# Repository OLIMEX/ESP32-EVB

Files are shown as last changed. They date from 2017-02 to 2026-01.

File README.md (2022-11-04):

# ESP32-EVB

ESP32 wifi / BLE development board with Ethernet, relays, microSD card, CAN, infrared, Li-Po charger, GPIOs.

Product page: https://www.olimex.com/Products/IoT/ESP32/ESP32-EVB/open-source-hardware

Open-source hardware board made with open-source CAD software. Comes with either ESP32-WROOM-32E or ESP32-WROOM-32UE module, depending on variant. Board vairants are:

| Board variant | ESP32 module  | External antenna  | Temperature range |
| --- | --- | ---  | --- |
| ESP32-EVB | ESP32-WROOM-32E  | No  | 0-70°C  |
| ESP32-EVB-EA  | ESP32-WROOM-32UE  | Yes  | 0-70°C  |
| ESP32-EVB-EA-IND  | ESP32-WROOM-32UE  | Yes  | -40+85°C |
| ESP32-EVB-IND  | ESP32-WROOM-32E  | No  | -40+85°C |

ESP32-EVB - ESP32-WROOM-32E module, no external antenna, commercial temeprature range 0-70°C

ESP32-EVB-EA - ESP32-WROOM-32UE module, fitting external antenna, commercial temeprature range 0-70°C

ESP32-EVB-EA-IND - ESP32-WROOM-32UE module, fitting external antenna, industrial temeprature range -40+85°C

ESP32-EVB-IND - ESP32-WROOM-32E module, no external antenna, industrial temeprature range -40+85°C

You can find design hardware sources, schematic exports, BOMs, and more, in the "HARDWARE" folder.

You can find ESP-IDF and Arduino IDE examples, in the "SOFTWARE" folder.

# FAQ

---

**Q:** I have some trouble downloading my code to ESP32-EVB. Is there a way to force boot mode?

**A:** By default the board comes without BOOT button functioanlity. However, we have providedan option to can convert user BUT1 into BOOT button to force button but this requires hardware change and soldering. Soldering experience is required since it is a tight spot. You need to perform two changes:

- Solder the pads of R46 together (or solder 0R resistor in 0603 size in the R46 position there);
- Unsolder R14 and solder its pads together (or again solder 0R resistor in 0603 size in the R14 position).

After the two changes, to manually force boot mode, hold button BUT1 then reset the board with RST1. Both R46 and R14 are near the button BUT1. Notice that the button will still act as user button after the initial boot sequence. You can find more about what changing these resistors does if you inspect the schematic.

---

**Q:** The Ethernet doesn't start after a restart, it throws "init phy failed" error. What should I do?

**A:** Ethernet might hang of initialized too quickly after a reset. Add some delay at the start of the code before the Ethernet initialization. For example, if you are using the default Arduino IDE demo for LAN8720 try adding delay () after Serial.begin(), as shown below:
```
void setup()
{
Serial.begin(115200);
delay (2000);
WiFi.onEvent(WiFiEvent);
ETH.begin();
}
```

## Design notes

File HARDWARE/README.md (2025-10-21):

# ESP32-EVB

Hardware revisions changes:

- revision A - internal, not released
- revision B - initial public release
- revision C - changes:

1. MicroUSB connector moved back, 40 mils to the middle of the board.
2. All mounting holes are now connected to GND.
3. Improved the ground layer around the infra red's pads and wires.

- revision C1 - changes:

1. Changed R38 from 10k/0603 to 100k/0603 to lower the time without clock
2. Changed C28 from 100n/0603 to 10n/0603 to increase the time in reset

- revision D - changes:

1. Added a resistor (1k) between OSC_DIS and reset of the PHY.
2. Added option to use MCP2562-E/SN and SN65HVD230D upotreba -> R58(NA/R0603)!
4. U2 be promeneno ot SY8009AAAC(SOT23-5) na SY8089AAAC(SOT23-5).
5. FET1 and FET2 were changed from IRLML6402 to WPM2015-3/TR.

- revision D1 - changes:

1. Removed C18(10uF)
2. U8 changed from BD5230G-TR(SSOP5/SOT-23-5) to NCP303LSN27T1G(SOT-23-5), due to unavailability;
3. C28 changed from 100nF/50V/20%/Y5V/C0603 to 470nF/16V/10%/X7R/C0603, because of the U8 change;

- revision D2 - changes:

1. U6 changed from MCP2551-I/SN(SOIC-8_150mil) to MCP2562-E/SN(SOIC-8_150mil)
2. R58 changed from NA/R0603 to 0R/R0603.

- revision E - changes:

MCP2551 got "Not recommended for new designs" status so it is replaced with MCP2562 and this lead to:

1. R58(0R/R0603) was deleted and U6's pin<5> was connected to +3.3V.
2. R52(680R/R0603) was deleted.
3. R50(330R/R0603) and R51(330R/R0603) were deleted.
4. The MCP2562-E_SN(SOIC-8_150mil)'s symbol was updated, i,.e. U6's component was exchanged with 2562!

Changes related to the problems with ethernet PHY:

5. The following components were added to enable powering on the PHY after the 50MHz oscillator has been started: L5(NA(FB0805/600R/2A)), FET3(WPM2015-3/TR), FET4(BSS138), C29(22uF/6.3V/20%/X5R/C0603), R50(1k/R0603) and R51(10k/R0603).

Changes related to optimizations:

6. R26(330R/R0603) and R27(330R/R0603) were changed to 220R/R0603 to reserve a feeder.
7. C1 was changed from 47uF/6.3V/20%/X5R/C0805 to NA(47uF/6.3V/20%/X5R/C0805).	
8. C3 was changed from 47uF/6.3V/20%/X5R/C0805 to NA(47uF/6.3V/20%/X5R/C0805).

- revision F - changes:

1. BUT1 and RST1 new packages.
2. Minor PCB routing optimizations.
3. All footprints were updated.

- revision G - internal, not released

1. Changed the Li-Po charger to BL4054B (was MCP73833 previously).

- revision H - limited release, changes:

1. CH340 now powered only from USB (not from battery). Added D7 and D8 on TX/RX, levels are adjusted via R35 and R40. Pin #20 now disconnected. SY8089AAAC(SOT23-5) devider now R20 49.9k and R19 220k. R24 now 470ê.
2. Added battery voltage sense option. This is controlled with jumper BAT/BUT1, C30, R9, and R10. It is not enabled by default to maintain compatiblity with previous revisions.
3. Added 3D models of the components.
4. L2 now 2.2uH/1.5A/DCR=72mR/20%/3.00x3.00x1.50mm/CD32(NR3015T2R2M). Some improvements on ESP-WROOM-32_MODULE package.

- revision H1 - released, changes:

Improved start up for certain hardware setups. Revision H1 has same PCB as revision H (and the PCB of revision H1 says "H") but couple of component changes:

1. Changed R24 from 470k/0603 to 1k/0603, the 1k resistor is soldered over the 470k one to reduce chances of damage.

- revsion I - released, changes:

Applied the changes from revision H1 to the PCB and the design, and further improved start-up reliability by adding a capacitor:

1. Added C31(1uF/10V/10%/X5R/C0603) on the ESP_EN signal and R24's value changed from 1k/0603 to 10k/0603;
2. Added several text lables at the botttom of the board about CAN's connector signals and the battery polarity.

- revision I1 - released, changes:

1. Changed C18 from NA(10uF/6.3V/20%/X5R/C0603) to 1nF/50V/5%/NPO(COG)/C0603 - this improves Ethernet reliability during relay switcing;

- revision I2 - released, changes:

1. Changed U8, from NCP303LSN27T1G(SOT-23-5) to NCP303LSN18T1G(SOT-23-5).

- revision I3 - released, changes:

1. Changed U6 from MCP2562-E/SN(SOIC-8_150mil) to SIT1042T/3(SOIC-8_150mil).

- revision I4 - released

1. Changed U2 value to NCV303LSN23T1G.

- revision J - not released

1. Due to global unavailability of MCP2562-E/SN chips, it was necessary to adjust the CAN schematic for compatiblity with MCP2551/SIT1050 too. Following changes were required:
- U6 changed from MCP2562-E/SN(SOIC-8_150mil) to SIT1050T(SOIC-8_150mil);
- Added R12, NA/R0603;
- Added R13, 330R/R0603;
- Added R15, 680R/R0603;
2. CE sign added in the PCB;
3. Changed C18 from NA(10uF/6.3V/20%/X5R/C0603) to 1nF/50V/5%/NPO(COG)/C0603 - this improves Ethernet behavior during relay switching;
4. Added U11(VDA2710NTA(SOT-23)), D10(BAT54A(SOT23-3)), R58(49.9R/1%/R0402), R52(220k/R0603) and C32(1uF/10V/10%/X5R/C0603), so that we can have option to replace the reset chip NCP303LSN27T1G(SOT-23-5). Changed U8 to (NA(NCP303LSN27T1G(SOT-23-5))) and C28 to NA(470nF/16V/10%/X7R/C0603);
5. Added D9(1N5819S4(SOD-123)), to rptoect ESP_EN from 4.2V surge during programming; also to protect C32 gettomg cjarged from DTR output of CH340, else new reset schematic (VDA2710NTA) has random timing after pressing reset button;
6. Added ESD protection on the Ethernet, TVS1(ESDS314DBVR(SOT-23-5));
7. R28, R31, R32, and R33 changed from 49.9R/1%/R0603 to 49.9R/1%/R0402;
8. U7 changed from RPM7236-H8 to VS1838B.

- revision K - released

1. Labelling improvements;
2. Removed "GPIO4" from the "Internal Bootstrapping Resistors" table.

- revision K1 - released

1. Changed reset IC from VDA2710NTA(SOT-23)to HX7027 (due to unavailability of VDA2710NTA).
2. HX7027 has slightly bigger consumption and when powered trought R52 the voltage might get too low; so also changed R52 from 220k to 100k.

- revision K2 - released
------
1. Changed battery chager to TP4054-42-SOT25-R;
2. Changed R8 from 2k to 10k to reduce battery charger current to 100mA.

- revision L - released
------

1. Migated the whole project to KiCad7;
2. R57 deleted to reduce possible environment noise picking in combination with relay switching;
3. Relays changed;
4. U2-SY8089 changed to TPS62A02ADRLR(SOT-563-6);
5. CH340 changed with smaller variant ch340X.

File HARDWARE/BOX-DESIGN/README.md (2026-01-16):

Box can be purchased from here: https://www.olimex.com/Products/IoT/ESP32/BOX-ESP32-EVB/

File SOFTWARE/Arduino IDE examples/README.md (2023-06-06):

Arduino IDE would not work with ESP32 boards out-the-box. ESP32-EVB and the rest of the Olimex-made ESP32 boards are supported by this Arduino for ESP32 package. You need to install ESP32 support in Arduino IDE, follow the advice here: 

https://docs.espressif.com/projects/arduino-esp32/en/latest/installing.html

After the package is installed select the ESP32-EVB entry from the board selector and the COM port it was assigned by your operating system.

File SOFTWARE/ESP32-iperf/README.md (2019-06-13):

This demo is based on the original iperf demo in esp-idf with adapted configuration for ESP32-EVB.

In order to make it work:
1) Select the port where the board has connected using menuconfig. To do so type inside the console (msys32 or terminal):
make menuconfig

2) Navigate to "Menu flasher config --> Default serial port" select your port.

3) After that flash the board (this may take a while the first time after you change any of the configurations)
make flash

4) Then run the terminal
make monitor

5) Wait to initialize follow the instructions on the terminal:
5.1) Run the ethernet
ethernet start
5.2) Optionally if you want to see more details (IP address, mask, default gateway) type
ethernet macro

6) Run the iperf
6.1) Server mode:
iperf -s -i 1 -t 10
with this you will run it for 10 seconds transfer (more than that will trigger the watchdog reset) and 1 second interval.

6.2) Client mode:
iperf -c SERVER_IP_ADDRESS -i 1

You can check the sample data inside the ESP32-PoE_Data.txt file.

YYYY/MM/DD
2019/06/13

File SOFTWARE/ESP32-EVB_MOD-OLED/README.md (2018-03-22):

Demo example for Olimex ESP32-EVB (revision D) with Olimex MOD-OLED-128x64 connected to the UEXT.

Used I2C-1 for communication between the host board and the module. More comments can be found in main.c. 

After programming on the screen you will see a welcome message. When you click the button BUT1, a counter will appear on the screen. The setup looks like this:

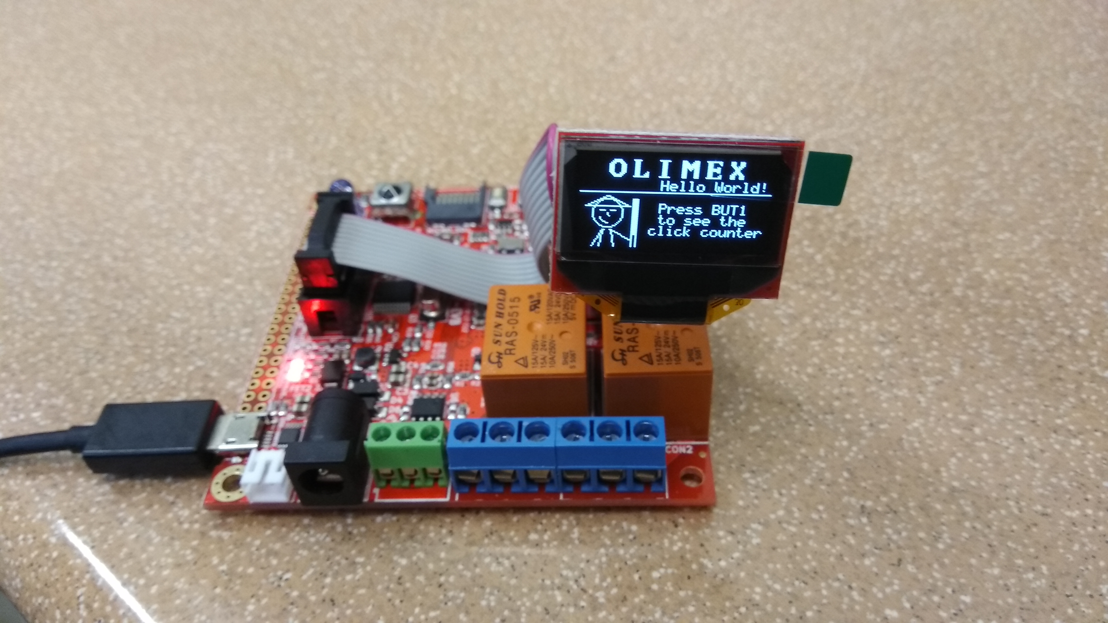
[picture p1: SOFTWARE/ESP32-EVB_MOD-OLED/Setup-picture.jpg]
Setup


Products used:

ESP32-EVB: https://www.olimex.com/Products/IoT/ESP32-EVB/open-source-hardware

MOD-OLED-128x64: https://www.olimex.com/Products/Modules/LCD/MOD-OLED-128x64/open-source-hardware

Stanimir Petev
2018/03/22

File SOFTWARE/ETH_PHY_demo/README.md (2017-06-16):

# Ethernet Example 
( customized for Olimex ESP32 EVB-REV-B with LAN8710 CAN & more ) 

Initialises the ethernet interface and enables it, then sends DHCP requests and tries to obtain a DHCP lease. If successful then you will be able to ping the device.

# PHY Configuration

Use "make menuconfig" to set the PHY model and the PHY address, and configure the SMI I/O pins (see below). These configuration items will vary depending on the hardware configuration you are using.

The customize default example configuration is correct for Olimex ESP32 EVB-REV B Ethernet board with LAN8710 PHY. 

## PHY Address

The PHY address depends on the hardware and the PHY configuration. Olimex ESP EVB-REV-B use PHY address 0.

FYI:
* Address 31 is correct for Espressif's Ethernet board with TLK110 PHY.
* Address 1 is correct for the common Waveshare LAN8720 PHY breakout.
* Default Address 0 is correct for the Olimex ESP32 EVB REV B IoT LAN8710 PHY Board with CAN
* Other LAN8720 breakouts may take address 0.

If the PHY address is incorrect then the EMAC will initialise but all attempts to read/write configuration registers on the PHY will fail.

## RMII PHY Wiring

The following PHY connections are required for RMII PHY data connections. These GPIO pin assignments cannot be changed.

| GPIO | RMII Signal | ESP32 EMAC Function | Notes |
| --- | --- | --- | ----- |
| 0 | REF_CLK | EMAC_TX_CLK | Currently this must be a 50MHz reference clock input from the PHY (ext_osc configuration). |
| 21 | TX_EN | EMAC_TX_EN | |
| 19 | TX0 | EMAC_TXD0 | |
| 22 | TX1 | EMAC_TXD1 | |
| 25 | RX0 | EMAC_RXD0 | |
| 26 | RX1 | EMAC_RXD1 | |
| 27 | CRS_DV | EMAC_RX_DRV | |

## RMII PHY SMI Wiring

The following PHY connections are required for RMII PHY SMI (aka MDIO) management interface. These GPIO pin assignments can be changed to any unused GPIO pin.

For the example, these pins are configured via `make menuconfig` under the Example configuration.

| Default Example GPIO | RMII Signal | Notes |
| --- | --- | --- |
| 23 | MDC | Output to PHY |
| 18 | MDIO | Bidirectional |

The defaults in the customized example are correct for Olimex EVB-REV-B Ethernet IoT board with CAN.

## Note about GPIO0

Because GPIO0 is a strapping pin for entering UART flashing mode on reset, care must be taken when also using this pin as EMAC_TX_CLK. If the clock output from the PHY is oscillating during reset, the ESP32 may randomly enter UART flashing mode.

One solution is to use an additional GPIO as a "power pin", which either powers the PHY on/off or enables/disables the PHY's own oscillator. This prevents the clock signal from being active during a system reset. For this configuration to work, GPIO0 also needs a pullup resistor and the "power pin" GPIO will need a pullup/pulldown resistor - as appropriate in order to keep the PHY clock disabled when the ESP32 is in reset.

See the example source code to see how the "power pin" GPIO can be managed in software.

To using GPIO 17 for this function can be overriden. Example on Espressif's Ethernet development board, GPIO 17 is the power pin used to enable/disable the PHY oscillator.

On Olimex ESP32 EVB REV B IoT LAN8710 PHY Board with CAN there is a own solution from Olimex.
For deeper Information look in the Hardware folder on Olimex Github. There is the Shematic.
Also there is the HDK with board pcb and other design Informations.

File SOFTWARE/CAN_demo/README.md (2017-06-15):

# CAN DEMO Code Example

Starts a CAN demo to receive Standard Frames
if there is test frame set in Kconfig ( menuconfig ) 
there is also send a test frame.

# Note:

Olimex EVB Rev B 

Rx CAN = GPIO 35

Tx CAN = GPIO  5 

See the README.md file in the components CAN directory for more information about 
CAN Driver Pack.

# credit 

# CAN Driver 
by Thomas Bart, 

http://www.barth-dev.de/

Repo: https://github.com/ThomasBarth/ESP32-CAN-Driver

# CAN Driver Pack ESP-IDF 
by Rudi Wagner, rudi ;-) 

http://esp32.de

Repo: https://github.com/ESP32DE/ESP32-CAN-Driver/tree/Component_CAN_Driver_Pack

# DEMO code for CAN Driver Pack 

https://github.com/ESP32DE/ESP32-CAN-Driver/tree/DEMO_CAN

# look allways first to the origin's

https://github.com/ThomasBarth/ESP32-CAN-Driver

https://github.com/ESP32DE/ESP32-CAN-Driver/tree/Component_CAN_Driver_Pack

https://github.com/ESP32DE/ESP32-CAN-Driver/tree/DEMO_CAN

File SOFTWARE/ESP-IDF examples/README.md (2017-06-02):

# ESP32-EVB Software development

## Install ESP-IDF
To run the examples in this directory or your own you'll need to get
SDK from Espressif called [ESP-IDF](https://github.com/espressif/esp-idf).
We recommend reading their
[setup guide](https://github.com/espressif/esp-idf#setting-up-esp-idf).

When IDF_PATH is in your PATH you're ready to continue with example running.

## Run examples
To run our example all you need to do is:

* Run menuconfig
```sh
    make menuconfig
```

    * Configure serial flasher

    ESP32-EVB has built-in serial flasher to help users upload their projects.
    Connect the board to PC via USB-micro cable. New serial device should
    apear, for example **/dev/ttyUSB0**. Then in the menuconfig configure
    flasher as follows:

    ```
    Serial flasher config  --->
            (/dev/ttyUSB0) Default serial port
            Default baud rate (115200 baud) --->
            [*] Use compressed upload
            Flash SPI mode (DIO)  --->
            Flash SPI speed (40 MHz) --->
            Flash size (4 MB) --->
            [*] Detect flash size when flashing bootloader
            Before flashing (Reset to bootloader)  --->
            After flashing (Reset after flashing)  --->
            'make monitor' baud rate (115200 bps)  --->
    ```

    * Configure example

    Some examples have their own configuration menu. If it's present
    you can modify the options:

    ```
    Example Configuration  --->
            Select board relay to use in the example (Relay 1)  --->
    ```

Exit and save configuration.

* Compile example
To compile example run:
```sh
make
```

* Uploading example
As we previously mention uploading application is done automatically.
If serial flasher is configured do:
```sh
make flash
```

You'll see something like this:
```
esptool.py v2.0-beta3
Flashing binaries to serial port /dev/ttyUSB0 (app at offset 0x10000)...
esptool.py v2.0-beta3
Connecting........__
Uploading stub...
Running stub...
Stub running...
Configuring flash size...
Auto-detected Flash size: 4MB
Flash params set to 0x0220
Compressed 15808 bytes to 9219...
Wrote 15808 bytes (9219 compressed) at 0x00001000 in 0.8 seconds (effective 154.5 kbit/s)...
Hash of data verified.
Compressed 356080 bytes to 168292...
Wrote 356080 bytes (168292 compressed) at 0x00010000 in 14.9 seconds (effective 191.3 kbit/s)...
Hash of data verified.
Compressed 3072 bytes to 82...
Wrote 3072 bytes (82 compressed) at 0x00008000 in 0.0 seconds (effective 1905.4 kbit/s)...
Hash of data verified.

Leaving...
Hard resetting...
```

Optionally you can open serial monitor by typing:
```sh
make monitor
```

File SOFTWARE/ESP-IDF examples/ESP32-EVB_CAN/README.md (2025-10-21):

| Supported Targets | ESP32 | 
| --- | ----- |

# CAN Example
(See the README.md file in the upper level 'examples' directory for more information about examples.)

## Overview

This example demonstrates basic usage of `CAN driver`. The work flow of the example could be as follows:

1. Install CAN driver
2. Receive CAN messages
3. Send CAN message
4. Enable filter and receive only filtered messages (not implemented)

Code was heavily based on https://docs.espressif.com/projects/esp-idf/en/release-v3.3/api-reference/peripherals/can.html

If you have a new CAN application to create (for example, J1939 communication to a tank), try this as a basic template, then add your own code.

## How to use example
See Build, Flash, and Run below.

### Hardware Required

This example assumes you have an Olimex ESP32-EVB and was tested with a REV I version. 

#### Pin Assignment

This example uses the embedded ESP32 CAN/TWAI controller. On the ESP32-EVB the pins are assigned as

* CAN-TX is on GPIO5
* CAN-RX is on GPI35

In the example code, these assignments are hard-coded.

### Configure the project

```
idf.py menuconfig
```
No configuration options have been set up.

The CAN transceiver is a MCP2562-E/SN. By default on the ESP32-EVB it operates on the +5V sourced from the PWR2 connector or USB connector.

### Build, Flash, and Run

Build the project and flash it to the board, then run monitor tool to view serial output. Use a CAN monitoring tool to see the transmitted message.

```
idf.py -p PORT build flash monitor
```

(Replace PORT with the name of the serial port to use.)

(To exit the serial monitor, type ``Ctrl-]``.)

See the [Getting Started Guide](https://docs.espressif.com/projects/esp-idf/en/latest/get-started/index.html) for full steps to configure and use ESP-IDF to build projects.

## Example Output

```bash
Driver installed
Driver started
Message received
Message is in Extended Format
ID:1CEBFFFA, data:2 90 E7 FF FF FF FF FF
Message queued for transmission
ESP_ERR_TIMEOUT
```

## Troubleshooting

See common troubleshooting for examples from [upper level](../README.md#common-troubleshooting).

(For any technical queries, please open an [issue](https://github.com/espressif/esp-idf/issues) on GitHub. We will get back to you as soon as possible.)

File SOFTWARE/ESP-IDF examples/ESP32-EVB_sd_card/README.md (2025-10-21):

# ESP32-EVB Software development
See the [README.md](../README.md) file in the upper level [examples](../) directory for more information about examples.

Copied from the OLD-ESP-IDF sd_card example without modification, except for deleting the makefiles and adding CMakeLists.txt as needed.

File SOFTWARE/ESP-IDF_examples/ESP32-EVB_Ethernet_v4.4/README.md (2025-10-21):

| Supported Targets | ESP32 | ESP32-S2 | ESP32-C3 |
| --- | ----- | --- | --- |

# Ethernet Example
(See the README.md file in the upper level 'examples' directory for more information about examples.)

## Overview

This example demonstrates basic usage of `Ethernet driver` together with `tcpip_adapter`. The work flow of the example could be as follows:

1. Install Ethernet driver
2. Send DHCP requests and wait for a DHCP lease
3. If get IP address successfully, then you will be able to ping the device

If you have a new Ethernet application to go (for example, connect to IoT cloud via Ethernet), try this as a basic template, then add your own code.

## How to use example

### Hardware Required

This example assumes you have an Olimex ESP32-EVB and was tested with a REV I version. The Ethernet PHY is a LAN8710A-EZC. See the Ethernet example in the Expressif ESP32 GitHub repository for information on using different hardware.

#### Configure the project (including Pin Assignment)
Set the following options using the Expressif-IDF SDK Configuration Editor (idf.py), or equivalent:
* Internal EMAC: enabled
* Ethernet PHY Device: LAN87xx
* SMI MDC GPIO number: 23
* SMI MDIO GPIO number: 18
* PHY Reset GPIO number: -1
* PHY Address: 0
* SPI Ethernet: disabled

### Build, Flash, and Run

Build the project and flash it to the board, then run monitor tool to view serial output:

```
idf.py -p PORT build flash monitor
```

(Replace PORT with the name of the serial port to use.)

(To exit the serial monitor, type ``Ctrl-]``.)

See the [Getting Started Guide](https://docs.espressif.com/projects/esp-idf/en/latest/get-started/index.html) for full steps to configure and use ESP-IDF to build projects.

## Example Output

```bash
I (394) eth_example: Ethernet Started
I (3934) eth_example: Ethernet Link Up
I (3934) eth_example: Ethernet HW Addr 30:ae:a4:c6:87:5b
I (5864) tcpip_adapter: eth ip: 192.168.2.151, mask: 255.255.255.0, gw: 192.168.2.2
I (5864) eth_example: Ethernet Got IP Address
I (5864) eth_example: ~~~~~~~~~~~
I (5864) eth_example: ETHIP:192.168.2.151
I (5874) eth_example: ETHMASK:255.255.255.0
I (5874) eth_example: ETHGW:192.168.2.2
I (5884) eth_example: ~~~~~~~~~~~
```

Now you can ping your ESP32 in the terminal by entering `ping 192.168.2.151` (it depends on the actual IP address you get).

## Troubleshooting

See common troubleshooting for Ethernet examples from [upper level](../README.md#common-troubleshooting).

(For any technical queries, please open an [issue](https://github.com/espressif/esp-idf/issues) on GitHub. We will get back to you as soon as possible.)

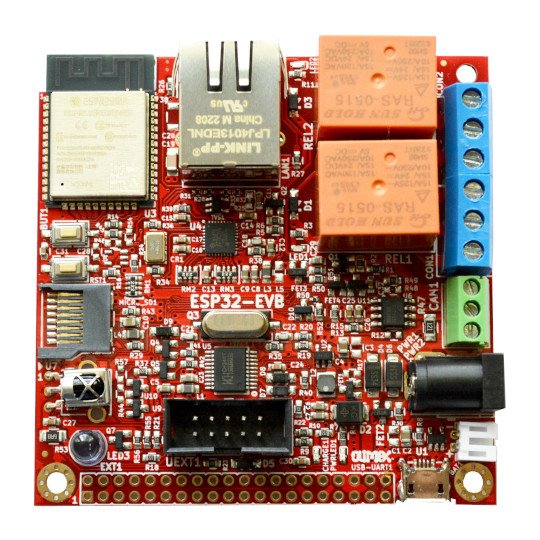
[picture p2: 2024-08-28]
DOCS/ESP32-EVB-2.jpg

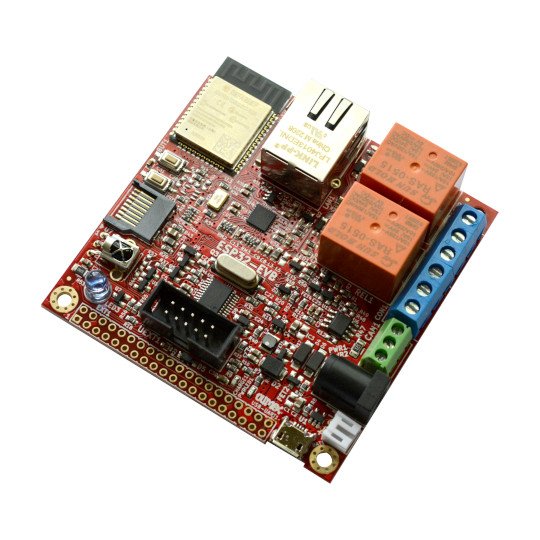
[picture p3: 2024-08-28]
DOCS/ESP32-EVB-1.jpg

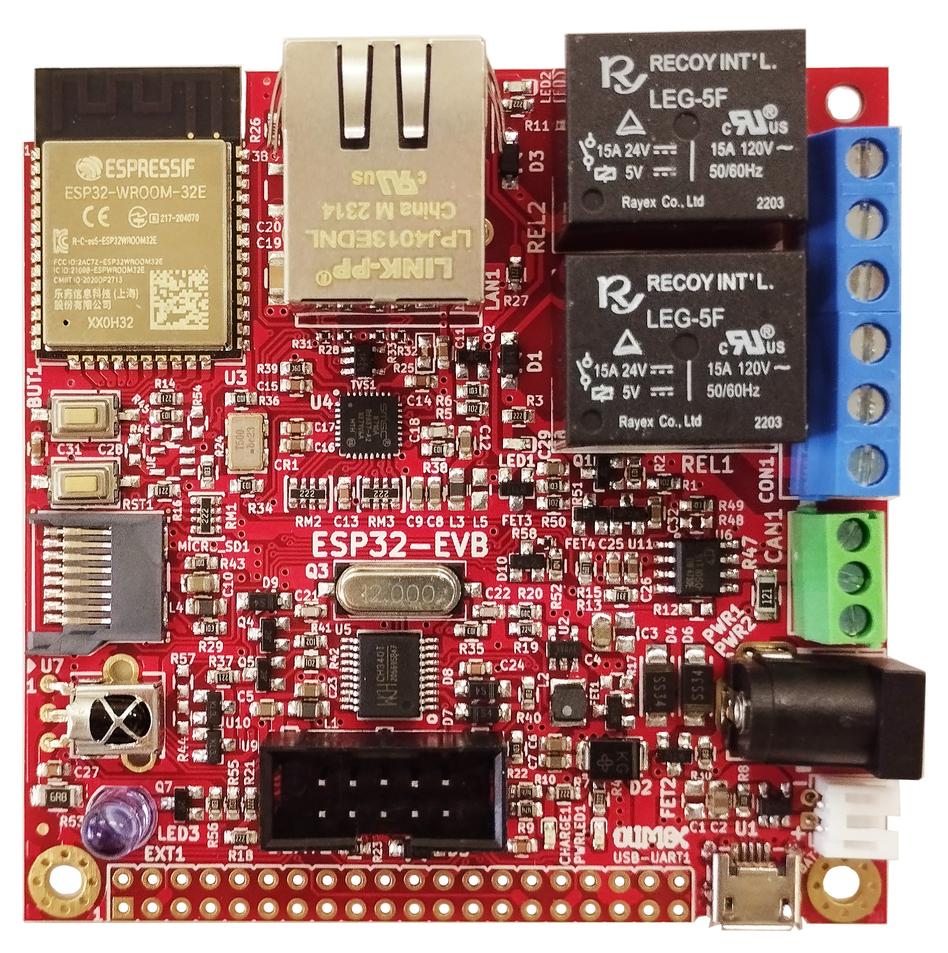
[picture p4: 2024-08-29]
DOCS/ESP32-EVB-2-new.jpg

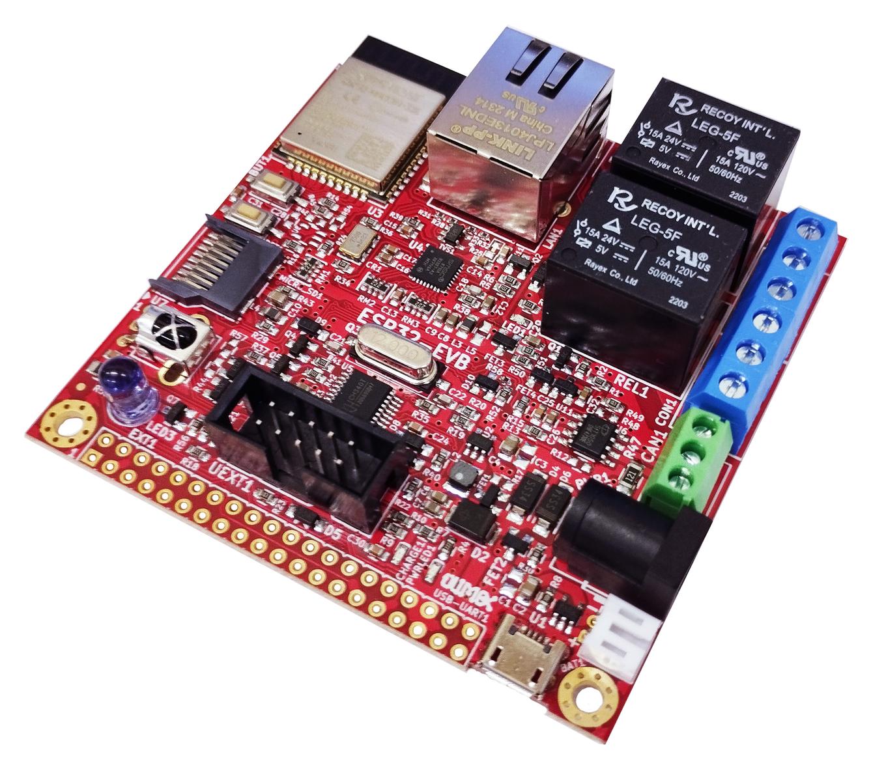
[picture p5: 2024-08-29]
DOCS/ESP32-EVB-1-new.jpg

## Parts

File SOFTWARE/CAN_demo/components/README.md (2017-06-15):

# Third Party Components

- ESPCan Driver 
  - Base CAN Driver [forked from Thomas Barth](https://github.com/ThomasBarth/ESP32-CAN-Driver)
  - General [Component CAN Driver Pack](https://github.com/ESP32DE/ESP32-CAN-Driver/tree/Component_CAN_Driver_Pack) Work for ESP-IDF with menuconfig from [rudi ;-)](http://esp32.de)

 version 0.1
 A basic CAN driver for the Espressif ESP32 by [Thomas Barth](http://barth-dev.de)
 
version 0.1_third_parts by [rudi ;-)](http://esp32.de)

Change Log from 21 May 2017
 - update to new DPORT Access
 - DPORT Access changed
    Details:
    https://github.com/espressif/esp-idf/commit/377a1f5ea1ca9152524d54df6a7294620f42173c

 - added RTR support
    Furetheremore, the complete FIR record is now copied into the 
    CAN frame type. This boosts performance.
    
    Details: 
    https://github.com/ThomasBarth/ESP32-CAN-Driver/commit/990a69465072a6ea7cf14f43f98fd6c95b8cf3a2

 - extended frames and interrupt types
    Added support for extended CAN frames and created an enum 
    for the CAN Interrupts.
    
    Details: 
    https://github.com/ThomasBarth/ESP32-CAN-Driver/commit/b1536a9ed3fe61abdeb1a1eaf4abdba978b2a09f

Change Log from 22 March 2017
 
   		- modified for esp-idf
   		- modified for component driver mode
 			- menuconfig file created
  			- cretaed component.mk for menuconfig and component version 
   		- modified and expanded demo code for using with menuconfig
 			- modified code for using it for Linux and Windows user
 
 			menuconfig config defines that you can use in the code:
 				ESPCan activated:
 					- CONFIG_ESPCAN ( bool ) 
  				baudrade 100,125, 250, 500, 800, 1000 and user: 
 					- CONFIG_CAN_SPEED_100KBPS 
 					- CONFIG_CAN_SPEED_125KBPS
 					- CONFIG_CAN_SPEED_250KBPS
 					- CONFIG_CAN_SPEED_500KBPS
 					- CONFIG_CAN_SPEED_800KBPS
 					- CONFIG_CAN_SPEED_1000KBPS
 					- CONFIG_CAN_SPEED_USER_KBPS
 				user CAN speed
 					- CONFIG_CAN_SPEED_USER_KBPS ( bool )
 						-CONFIG_CAN_SPEED_USER_KBPS_VAL (value)
 				gpio pins for CANRx and CANTx
 					- CONFIG_ESP_CAN_RXD_PIN_NUM
 					- CONFIG_ESP_CAN_TXD_PIN_NUM 
 				node id ( CAN identifier )
 					- CONFIG_ESP_CAN_NODE_ITSELF
 				enbable/disable send test frames
 					- CONFIG_CAN_TEST_SENDING_ENABLED
 					- CONFIG_CAN_TEST_SENDING_DISABLED

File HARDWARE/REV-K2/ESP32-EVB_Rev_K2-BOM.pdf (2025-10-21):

ESP32-EVB_Rev_K2_BOM | 02/25/2025
Qty | Designation | Package | Designator
1 | 0R(board_mounted) | 0R_0603 | R25
1 | 6.8R/R1206 | R_1206_5MIL_DWS | R53
2 | 10R/R0603 | R_0603_5MIL_DWS | R36,R43
5 | 49.9R/1%/R0402 | R_0402_5MIL_DWS | R28,R31,R32,R33,R58
1 | 120R/R1206 | R_1206_5MIL_DWS | R47
5 | 220R/R0603 | R_0603_5MIL_DWS | R14,R16,R26,R27,R37
1 | 330R/R0603 | R_0603_5MIL_DWS | R13
1 | 680R/R0603 | R_0603_5MIL_DWS | R15
6 | 1k/R0603 | R_0603_5MIL_DWS | R1,R5,R42,R41,R50,R55
1 | 2k/1%/R0603 | R_0603_5MIL_DWS | R8
6 | 2.2k/R0603 | R_0603_5MIL_DWS | R3,R4,R7,R11,R18,R21
15 | 10k/R0603 | R_0603_5MIL_DWS | R2,R6,R22,R23,R24,R29, R30,R34,R35,R38,R40,R45, R49,R51,R56
1 | 12.1k/1%/R0603 | R_0603_5MIL_DWS | R39
1 | 49.9k/1%/R0603 | R_0603_5MIL_DWS | R20
1 | 100k/R0603 | R_0603_5MIL_DWS | R52
1 | 220k/R0603 | R_0603_5MIL_DWS | R19
2 | 470k/R0603 | R_0603_5MIL_DWS | R9,R10
3 | RA1206_(4X0603)_4B8_2.2k | R_MATRIX_4 | RM1,RM2,RM3
2 | 27pF/50V/5%/C0G/C0603 | C_0603_5MIL_DWS | C21,C22
1 | 1nF/50V/5%/NPO(COG)/C0603 | C_0603_5MIL_DWS | C18
1 | 1nF/2000V/10%/X7R/C1206 | C_1206_5MIL_DWS_ISO | C19
9 | 100nF/50V/20%/Y5V/C0603 | C_0603_5MIL_DWS | C11,C13,C14,C15,C17, C25,C24,C27,C30
2 | 1uF/10V/10%/X5R/C0603 | C_0603_5MIL_DWS | C31,C32
1 | 2.2uF/6.3V/10%/X5R/C0603 | C_0603_5MIL_DWS | C16
1 | 10uF/6.3V/20%/X5R/C0603 | C_0603_5MIL_DWS | C26
8 | 22uF/6.3V/20%/X5R/C0603 | C_0603_5MIL_DWS | C5,C6,C7,C8,C9,C12,C23,C29
3 | 47uF/6.3V/20%/X5R/C0805 | C_0805_5MIL_DWS | C2,C4,C10
1 | 2.2uH/NRS3015T2R2MNGH | CD32 | L2
3 | 600R/2A/UPZ2012E-601-2R0TF | L_0805_5MIL_DWS | L1,L3,L4
1 | SMBJ6.0A(DO-214AA) | DO214AA_1(K)-2(A) | D2
2 | 1N5822/SS34/SMA | SMA-KA | D4,D6
6 | 1N5819S4(SOD-123) | SOD-123_1C-2A_KA | D1,D3,D5,D7,D8,D9
2 | BAT54C(SOT23-3) | SOT23-3 | U9,U10
1 | BAT54A(SOT23-3) | SOT23-3 | D10
1 | LED/IR333-A/5mm | LED-5mm-PTH-AK | LED3
1 | LED/Yellow/0603 | LED_0603_KA | CHARGE1
1 | LED/RED/0603 | LED_0603_KA | PWRLED1
2 | LED/GREEN/0603 | LED_0603_KA | LED1,LED2
5 | BC817-40(SOT23) | SOT23 | Q1,Q2,Q4,Q5,Q7
3 | WPM2015-3/TR | SOT23 | FET1,FET2,FET3
1 | BSS138 | SOT23 | FET4
1 | Q12MHz/2P/20ppm/20pF/HU49SM | Q_49U3HMS | Q3
1 | Q50MHz/25ppm/3V/4P/5x3.2mm | 5032-4P_HCX-3S | CR1
1 | ESDS314DBVR(SOT-23-5) | SOT-23-5 | TVS1
1 | ESP32-WROOM-32E-N4 | ESP-WROOM-32_MODULE | U3
1 | SIT1050T(SOIC-8_150mil) | SOIC-8_150mil | U6
1 | TP4054-42-SOT25-R | SOT-23-5 | U1
1 | LAN8710A-EZC(QFN32) | QFN32_EP(33)_5x5x0.9mm_ Pitch_0.5mm | U4
1 | HX7027(SOT-23) | SOT-23 | U11

ESP32-EVB_Rev_K2_BOM | 02/25/2025
1 | CH340T(SSOP20W) | SSOP-20W | U5
1 | SY8089AAAC(SOT23-5) | SOT-23-5 | U2
1 | VS1838B | RPM7236-H8 | U7
1 | PWRJ-2mm(YDJ-1134) | PWRJ-2mm(YDJ-1136) | PWR1
1 | BH10S(B-D-02x5-LF) | UEXT_ML10 | UEXT1
1 | TB3-3.5mm(HD-351 3P) | TB3-3.5mm | CAN1
1 | MISB-SWMM-5B-LF | USB-MICRO_MISB-SWMM-5B_LF | USB-UART1
1 | RJLBC-060TC1(LPJ4013EDNL) | RJLBC-060TC1 | LAN1
2 | DG306-5.0-3P | TB3-DG306-5.0_3P | CON1,CON2
1 | DW02R | LIPO_BAT-CON2DW02R | BAT1
1 | TFC-WXCP11-08-LF | TFC-WXCP11-08-LF | MICRO_SD1
2 | RAS-0515 (LEG-5) | Relay_RAS-05-15 | REL1,REL2
2 | T1107A(6x3,8x2,5MM) | T1107A(6x3,8x2,5MM) | BUT1,RST1
1 | Closed(1-2)/Opened(2-3) | SJ_2_SMALL_12_TIED | 5.0V/3.3V1
1 | Opened(2-3)/Soldered(1-2) | SJ_2_SMALL | BAT/BUT1
2 | Opened | SJ | CAN_T1,PHY_RST1
1 | NA(HN2x20) | HN2x20 | EXT1
1 | NA(TB2 DG306-5.0-2P) | TB2-DG306-5.0_2P | PWR2
1 | NA(1k/R0603) | R_0603_5MIL_DWS | R57
6 | NA/R0603 | R_0603_5MIL_DWS | R44,R54,R48,R46,R17,R12
2 | NA(47uF/6.3V/20%/X5R/C0805) | C_0805_5MIL_DWS | C3,C1
1 | NA(FB0805/600R/2A) | L_0805_5MIL_DWS | L5
1 | NA(470nF/16V/10%/X7R/C0603) | C_0603_5MIL_DWS | C28
1 | NA(1nF/2000V/10%/X7R/C1206) | C_1206_5MIL_DWS_ISO | C20
1 | NA(NCP303LSN27T1G) | SOT-23-5 | U8

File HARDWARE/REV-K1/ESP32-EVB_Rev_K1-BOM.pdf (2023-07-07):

ESP32-EVB_Rev_K1-BOM | 18/04/2023
Quantity | Designation | Package | Designator
1 | 0R(board_mounted) | R0603 | R25
1 | 6.8R/R1206 | R1206 | R53
2 | 10R/R0603 | R0603 | R36,R43
5 | 49.9R/1%/R0402 | R0402 | R28,R31,R32,R33,R58
1 | 120R/R1206 | R1206 | R47
5 | 220R/R0603 | R0603 | R14,R16,R26,R27,R37
1 | 330R/R0603 | R0603 | R13
1 | 680R/R0603 | R0603 | R15
6 | 1k/R0603 | R0603 | R1,R5,R41,R42,R50,R55
1 | 2k/1%/R0603 | R0603 | R8
6 | 2.2k/R0603 | R0603 | R3,R4,R7,R11,R18,R21
3 | RA1206_(4X0603)_4B8_2.2k | RA1206 | RM1,RM2,RM3
15 | 10k/R0603 | R0603 | R2,R6,R22,R23,R24,R29, R30,R34,R35,R38,R40, R45,R49,R51,R56
1 | 12.1k/1%/R0603 | R0603 | R39
1 | 49.9k/1%/R0603 | R0603 | R20
1 | 220k/R0603 | R0603 | R19
1 | 100k/R0603 | R0603 | R52
2 | 470k/R0603 | R0603 | R9,R10
3 | FB0805/600R/2A | L0805 | L1,L3,L4
1 | 2.2uH/1.5A/DCR=72mR/ 20%/3.00x3.00x1.50mm/ CD32(NR3015T2R2M) | CD32 | L2
2 | 27pF/50V/5%/C0G/C0603 | C0603 | C21,C22
1 | 1nF/50V/5%/NPO(COG)/C0603 | C0603 | C18
9 | 100nF/50V/20%/Y5V/C0603 | C0603 | C11,C13,C14,C15,C17, C24,C25,C27,C30
1 | 1nF/2000V/10%/X7R/C1206 | C1206 | C19
2 | 1uF/10V/10%/X5R/C0603 | C0603 | C31,C32
1 | 2.2uF/6.3V/10%/X5R/C0603 | C0603 | C16
1 | 10uF/6.3V/20%/X5R/C0603 | C0603 | C26
8 | 22uF/6.3V/20%/X5R/C0603 | C0603 | C5,C6,C7,C8,C9,C12,C23,C29
3 | 47uF/6.3V/20%/X5R/C0805 | C0805 | C2,C4,C10
1 | LED/Yellow/0603 | LED0603 | CHARGE1
1 | LED/RED/0603 | LED0603 | PWRLED1
2 | LED/GREEN/0603 | LED0603 | LED1,LED2
1 | LED/IR333-A/5mm | LED-5mm-PTH | LED3
1 | BAT54A(SOT23-3) | SOT23-3 | D10
2 | BAT54C(SOT23-3) | SOT23-3 | U9,U10
6 | 1N5819S4(SOD-123) | SOD-123 | D1,D3,D5,D7,D8,D9
2 | 1N5822/SS34/SMA | SMA | D4,D6
1 | ESDS314DBVR(SOT-23-5) | SOT-23-5 | TVS1
1 | SMBJ6.0A(DO-214AA) | DO214AA | D2
5 | BC817-40(SOT23) | SOT23 | Q1,Q2,Q4,Q5,Q7
1 | BSS138 | SOT23 | FET4
3 | WPM2015-3/TR | SOT23 | FET1,FET2,FET3
1 | BL4054B-42TPRN(SOT23-5) | SOT-23-5 | U1
1 | CH340T(SSOP20W) | SSOP-20W | U5
1 | ESP-WROOM-32 | ESP-WROOM-32 | U3
1 | LAN8710A-EZC(QFN32) | QFN32 | U4

ESP32-EVB_Rev_K1-BOM | 18/04/2023
1 | VS1838B | RPM7236-H8 | U7
1 | SIT1050T(SOIC-8_150mil) | SOIC-8 | U6
1 | SY8089AAAC(SOT23-5) | SOT-23-5 | U2
1 | HX7027(SOT-23) | SOT-23 | U11
1 | Q12MHz/20pF/30ppm/ 2P/HC-49SM(SMD) | Q_49U3HMS | Q3
1 | Q50MHz/25ppm/3V/4P/5x3.2mm | 5032-4P_HCX-3S | CR1
2 | RAS-0515 | Relay_RAS-05-15 | REL1,REL2
2 | T1107A(6x3,8x2,5MM) | T1107A(6x3,8x2,5MM) | BUT1,RST1
1 | BH10S | ML10 | UEXT1
1 | DW02R | DW02R | BAT1
1 | MISB-SWMM-5B-LF(USB_MICRO) | MISB-SWMM-5B_LF | USB-UART1
1 | PWRJ-2mm(YDJ-1134) | PWRJ-2mm | PWR1
1 | RJLD-060TC1(LPJ4013EDNL) | RJLBC-060TC1 | LAN1
1 | TB3-3.5mm | TB3-3.5mm | CAN1
2 | TB3-DG306-5.0-3P | DG306-5.0_3P | CON1,CON2
1 | TFC-WXCP11-08-LF | TFC-WXCP11-08-LF | MICRO_SD1
2 | Opened | SJ | CAN_T1,PHY_RST1
1 | Closed(1-2)/Opened(2-3) | SJ_2 | 5.0V/3.3V1
1 | Opened(2-3)/Soldered(1-2) | SJ_2 | BAT/BUT1
6 | NA/R0603 | R0603 | R12,R17,R44,R46,R48,R54
1 | NA(1k/R0603) | R0603 | R57
1 | NA(FB0805/600R/2A) | L0805 | L5
1 | NA(1nF/2000V/10%/X7R/C1206) | C1206 | C20
1 | NA(470nF/16V/10%/X7R/C0603) | C0603 | C28
2 | NA(47uF/6.3V/20%/X5R/C0805) | C0805 | C1,C3
1 | NA(NCP303LSN27T1G(SOT-23-5)) | SOT-23-5 | U8
1 | NA(HN2x20) | HN2x20 | EXT1
1 | NA(TB2 DG306-5.0-2P) | DG306-5.0_2P | PWR2

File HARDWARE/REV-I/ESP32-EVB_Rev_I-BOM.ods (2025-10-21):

Qty | Designation | Package | Designator
1 | DW02R | DW02R | BAT1
1 | 2.2uF/6.3V/10%/X5R/C0603 | C0603 | C16
1 | 1nF/2000V/10%/X7R/C1206 | C1206 | C19
3 | 47uF/6.3V/20%/X5R/C0805 | C0805 | C2,C4,C10
2 | 27pF/50V/5%/C0G/C0603 | C0603 | C22,C21
8 | 22uF/6.3V/20%/X5R/C0603 | C0603 | C23,C12,C9,C8,C7,C6, C5,C29
1 | 10uF/6.3V/20%/X5R/C0603 | C0603 | C26
9 | 100nF/50V/20%/Y5V/C0603 | C0603 | C27,C25,C24,C17,C15, C14,C13,C11,C30
1 | 470nF/16V/10%/X7R/C0603 | C0603 | C28
1 | 1uF/10V/10%/X5R/C0603 | C0603 | C31
1 | TB3-3.5mm | TB3-3.5mm | CAN1
1 | LED/Yellow/0603 | LED0603 | CHARGE1
2 | TB3 DG306-5.0-3P | TB3-DG306-5.0_3P | CON2,CON1
1 | Q50MHz/25ppm/3V/4P/5x3.2mm | 5032-4P_HCX-3S | CR1
1 | SMBJ6.0A(DO-214AA) | DO214AA | D2
5 | 1N5819S4(SOD-123) | SOD-123 | D3,D1,D5,D7,D8
2 | 1N5822/SS34/SMA | SMA-KA | D6,D4
3 | WPM2015-3/TR | SOT23 | FET2,FET1,FET3
1 | BSS138 | SOT23 | FET4
1 | 2.2uH/1.5A/DCR=72mR/20%/ 3.00x3.00x1.50mm/CD32 (NR3015T2R2M) | CD32 | L2
3 | FB0805/600R/2A | L0805 | L4,L3,L1
1 | RJLD-060TC1(LPJ4013EDNL) | RJLBC-060TC1 | LAN1
2 | LED/GREEN/0603 | LED0603 | LED2,LED1
1 | LED/IR333-A/5mm | LED-5mm | LED3
1 | TFC-WXCP11-08-LF | TFC-WXCP11-08-LF | MICRO_SD1
1 | PWRJ-2mm(YDJ-1134) | PWRJ-2mm(YDJ-1136) | PWR1
1 | LED/RED/0603 | LED0603 | PWRLED1
5 | BC817-40(SOT23) | SOT23 | Q1,Q4,Q5,Q7,Q2
1 | Q12MHz/20pF/30ppm/2P/HC-49SM(SMD) | Q_49U3HMS | Q3
6 | 1k/R0603 | R0603 | R1,R5,R41,R42,R50,R55
1 | 220k/R0603 | R0603 | R19
15 | 10k/R0603 | R0603 | R2,R6,R22,R23,R24,R29,R30, R34,R35,R38,R40,R45,R49, R51,R56
1 | 49.9k/1%/R0603 | R0603 | R20
1 | 0R(board_mounted) | R0603 | R25
4 | 49.9R/1%/R0603 | R0603 | R33,R32,R31,R28
5 | 220R/R0603 | R0603 | R37,R27,R26,R16,R14
1 | 12.1k/1%/R0603 | R0603 | R39
6 | 2.2k/R0603 | R0603 | R4,R21,R18,R11,R3,R7
2 | 10R/R0603 | R0603 | R43,R36
1 | 120R/R1206 | R1206 | R47
1 | 6.8R/R1206 | R1206 | R53
1 | 2k/1% | R0603 | R8
2 | 470k/R0603 | R0603 | R9,R10
2 | RAS-0515 | Relay_RAS-05-15 | REL1,REL2
3 | RA1206_(4X0603)_4B8_2.2k | R_MATRIX_4 | RM1,RM2,RM3
2 | T1107A(6x3,8x2,5MM) | T1107A(6x3,8x2,5MM) | RST1,BUT1
1 | BL4054B-42TPRN(SOT23-5) | SOT-23-5 | U1
2 | BAT54C(SOT23-3) | SOT23-3 | U10,U9
1 | SY8089AAAC(SOT23-5) | SOT-23-5 | U2
1 | ESP32-WROOM-32D-4MB | ESP-WROOM-32 | U3
1 | LAN8710A-EZC(QFN32) | QFN32 | U4
1 | CH340T(SSOP20W) | SSOP-20W | U5
1 | MCP2562-E/SN(SOIC-8_150mil) | SOIC-8_150mil | U6
1 | RPM7236-H8 | RPM7236-H8 | U7
1 | NCP303LSN27T1G(SOT-23-5) | SOT-23-5 | U8
1 | BH10S | UEXT_ML10 | UEXT1
1 | MISB-SWMM-5B-LF(USB_MICRO) | MISB-SWMM-5B_LF | USB-UART1
2 | Opened | SJ | CAN_T1,PHY_RST1
1 | Closed(1-2)/Opened(2-3) | SJ_2_SMALL_12_TIED | 5.0V/3.3V1
1 | Opened(2-3)/Soldered(1-2) | SJ_2_SMALL | BAT/BUT1
1 | NA(1k/R0603) | R0603 | R57
5 | NA/R0603 | R0603 | R44,R54,R48,R46,R17
2 | NA(47uF/6.3V/20%/X5R/C0805) | C0805 | C3,C1
1 | NA(1nF/2000V/10%/X7R/C1206) | C1206 | C20
1 | NA(HN2x20) | HN2x20 | EXT1
1 | NA(TB2 DG306-5.0-2P) | TB2-DG306-5.0_2P | PWR2
1 | NA(10uF/6.3V/20%/X5R/C0603) | C0603 | C18
1 | NA(FB0805/600R/2A) | L0805 | L5

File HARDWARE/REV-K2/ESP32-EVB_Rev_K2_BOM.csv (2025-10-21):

Id | Designator | Package | Quantity | Designation | Supplier and ref
1 | PWR2 | TB2-DG306-5.0_2P | 1 | NA(TB2 DG306-5.0-2P)
2 | PWR1 | PWRJ-2mm(YDJ-1136) | 1 | PWRJ-2mm(YDJ-1134)
3 | UEXT1 | UEXT_ML10 | 1 | BH10S(B-D-02x5-LF)
4 | U3 | ESP-WROOM-32_MODULE | 1 | ESP32-WROOM-32E-N4
5 | R33,R32,R28,R31,R58 | R_0402_5MIL_DWS | 5 | 49.9R/1%/R0402
6 | R43,R36 | R_0603_5MIL_DWS | 2 | 10R/R0603
7 | EXT1 | HN2x20 | 1 | NA(HN2x20)
8 | CAN1 | TB3-3.5mm | 1 | TB3-3.5ММ(HD-351 3P)
9 | LAN1 | RJLBC-060TC1 | 1 | RJLBC-060TC1(LPJ4013EDNL)
10 | REL2,REL1 | Relay_RAS-05-15 | 2 | RAS-0515 (LEG-5)
11 | BAT1 | LIPO_BAT-CON2DW02R | 1 | DW02R
12 | D4,D6 | SMA-KA | 2 | 1N5822/SS34/SMA
13 | D5,D7,D8,D3,D1,D9 | SOD-123_1C-2A_KA | 6 | 1N5819S4(SOD-123)
14 | Q3 | Q_49U3HMS | 1 | Q12MHz/2P/20ppm/20pF/HU49SM
15 | USB-UART1 | USB-MICRO_MISB-SWMM-5B_LF | 1 | MISB-SWMM-5B-LF
16 | BUT1,RST1 | T1107A(6x3,8x2,5MM) | 2 | T1107A(6x3,8x2,5MM)
17 | U6 | SOIC-8_150mil | 1 | SIT1050T(SOIC-8_150mil)
18 | U5 | SSOP-20W | 1 | CH340T(SSOP20W)
19 | MICRO_SD1 | TFC-WXCP11-08-LF | 1 | TFC-WXCP11-08-LF
20 | U4 | QFN32_EP(33)_5.00x5.00x0.90mm_Pitch_0.50mm | 1 | LAN8710A-EZC(QFN32)
21 | Sign_CE | CE_Sign | 1 | CE_Sign
22 | CON2,CON1 | TB3-DG306-5.0_3P | 2 | DG306-5.0-3P
23 | LED3 | LED-5mm-PTH-AK | 1 | LED/IR333-A/5mm
24 | U7 | RPM7236-H8 | 1 | VS1838B
25 | CR1 | 5032-4P_HCX-3S | 1 | Q50MHz/25ppm/3V/4P/5x3.2mm
26 | R29,R56,R49,R45,R30,R40,R38,R35,R34,R24,R23,R22,R6,R2,R51 | R_0603_5MIL_DWS | 15 | 10k/R0603
27 | C2,C4,C10 | C_0805_5MIL_DWS | 3 | 47uF/6.3V/20%/X5R/C0805
28 | Fid2,Fid1,Fid3 | Fiducial1x3 | 3
29 | R25 | 0R_0603 | 1 | 0R(board_mounted)
30 | D2 | DO214AA_1(K)-2(A) | 1 | SMBJ6.0A(DO-214AA)
31 | R57 | R_0603_5MIL_DWS | 1 | NA(1k/R0603)
32 | R44,R54,R48,R46,R17,R12 | R_0603_5MIL_DWS | 6 | NA/R0603
33 | U10,U9 | SOT23-3 | 2 | BAT54C(SOT23-3)
34 | Sign-RoHS | LOGO_ROHS_1 | 1 | Val**
35 | Sign-RecycleBin | LOGO_RECYCLEBIN_1 | 1
36 | Sign-PbFree | LOGO_PBFREE | 1
37 | Logo-OSHW | LOGO_OPENHARDWARE_8x8 | 1
38 | Sign-Antistatic | LOGO_ANTISTATIC_1 | 1 | Val**
39 | R37,R27,R26,R16,R14 | R_0603_5MIL_DWS | 5 | 220R/R0603
40 | C3,C1 | C_0805_5MIL_DWS | 2 | NA(47uF/6.3V/20%/X5R/C0805)
41 | R20 | R_0603_5MIL_DWS | 1 | 49.9k/1%/R0603
42 | R19 | R_0603_5MIL_DWS | 1 | 220k/R0603
43 | R4,R21,R18,R11,R3,R7 | R_0603_5MIL_DWS | 6 | 2.2k/R0603
44 | R55,R42,R41,R5,R1,R50 | R_0603_5MIL_DWS | 6 | 1k/R0603
45 | R53 | R_1206_5MIL_DWS | 1 | 6.8R/R1206
46 | R47 | R_1206_5MIL_DWS | 1 | 120R/R1206
47 | CAN_T1,PHY_RST1 | SJ | 2 | Opened
48 | C28 | C_0603_5MIL_DWS | 1 | NA(470nF/16V/10%/X7R/C0603)
49 | C27,C25,C24,C17,C15,C14,C13,C11,C30 | C_0603_5MIL_DWS | 9 | 100nF/50V/20%/Y5V/C0603
50 | C26 | C_0603_5MIL_DWS | 1 | 10uF/6.3V/20%/X5R/C0603
51 | C23,C12,C9,C8,C7,C6,C5,C29 | C_0603_5MIL_DWS | 8 | 22uF/6.3V/20%/X5R/C0603
52 | C22,C21 | C_0603_5MIL_DWS | 2 | 27pF/50V/5%/C0G/C0603
53 | C20 | C_1206_5MIL_DWS_ISO | 1 | NA(1nF/2000V/10%/X7R/C1206)
54 | C19 | C_1206_5MIL_DWS_ISO | 1 | 1nF/2000V/10%/X7R/C1206
55 | MH3,MH2 | Mounting_hole_Shield_3.3mm | 2 | Mounting_hole_Shield_3.3mm
56 | R39 | R_0603_5MIL_DWS | 1 | 12.1k/1%/R0603
57 | PWRLED1 | LED_0603_KA | 1 | LED/RED/0603
58 | LED2,LED1 | LED_0603_KA | 2 | LED/GREEN/0603
59 | GND1 | TESTPAD_40-ROUND | 1 | TESTPAD
60 | C18 | C_0603_5MIL_DWS | 1 | 1nF/50V/5%/NPO(COG)/C0603
61 | C16 | C_0603_5MIL_DWS | 1 | 2.2uF/6.3V/10%/X5R/C0603
62 | MH1 | Mounting_hole_3.3mm | 1 | Mounting_hole_Shield_3.3mm
63 | Logo-Olimex-Big | OLIMEX_LOGO_TB | 1
64 | RM1,RM2,RM3 | R_MATRIX_4 | 3 | RA1206_(4X0603)_4B8_2.2k
65 | U2 | SOT-23-5 | 1 | SY8089AAAC(SOT23-5)
66 | Q1,Q4,Q5,Q7,Q2 | SOT23 | 5 | BC817-40(SOT23)
67 | FET2,FET1,FET3 | SOT23 | 3 | WPM2015-3/TR
68 | U8 | SOT-23-5 | 1 | NA(NCP303LSN27T1G(SOT-23-5))
69 | L4,L3,L1 | L_0805_5MIL_DWS | 3 | 600R/2A/UPZ2012E-601-2R0TF
70 | L2 | CD32 | 1 | 2.2uH/NRS3015T2R2MNGH
71 | 5.0V/3.3V1 | SJ_2_SMALL_12_TIED | 1 | Closed(1-2)/Opened(2-3)
72 | FET4 | SOT23 | 1 | BSS138
73 | L5 | L_0805_5MIL_DWS | 1 | NA(FB0805/600R/2A)
74 | Logo-Olimex_Small | LOGO_OLIMEX_80 | 1
75 | CHARGE1 | LED_0603_KA | 1 | LED/Yellow/0603
76 | U1 | SOT-23-5 | 1 | TP4054-42-SOT25-R
77 | R8 | R_0603_5MIL_DWS | 1 | 2k/1%/R0603
78 | BAT/BUT1 | SJ_2_SMALL | 1 | Opened(2-3)/Soldered(1-2)
79 | R9,R10 | R_0603_5MIL_DWS | 2 | 470k/R0603
80 | C31,C32 | C_0603_5MIL_DWS | 2 | 1uF/10V/10%/X5R/C0603
81 | R13 | R_0603_5MIL_DWS | 1 | 330R/R0603
82 | R15 | R_0603_5MIL_DWS | 1 | 680R/R0603
83 | TVS1 | SOT-23-5 | 1 | ESDS314DBVR(SOT-23-5)
84 | D10 | SOT23-3 | 1 | BAT54A(SOT23-3)
85 | R52 | R_0603_5MIL_DWS | 1 | 100k/R0603
86 | U11 | SOT-23 | 1 | HX7027(SOT-23)

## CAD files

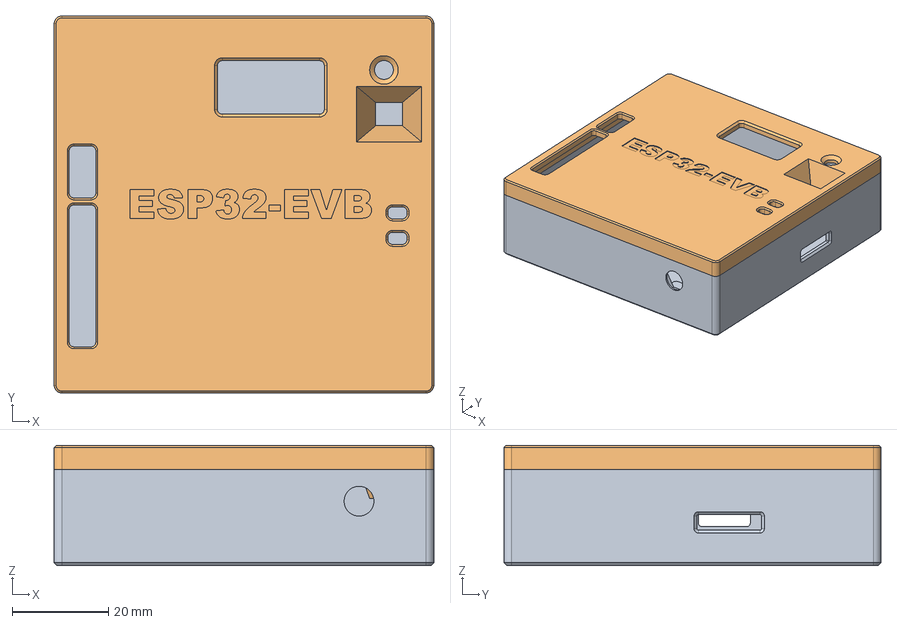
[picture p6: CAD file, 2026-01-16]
HARDWARE/BOX-DESIGN/esp32-evbrevk.step
79.0 x 78.4 x 25.0 mm

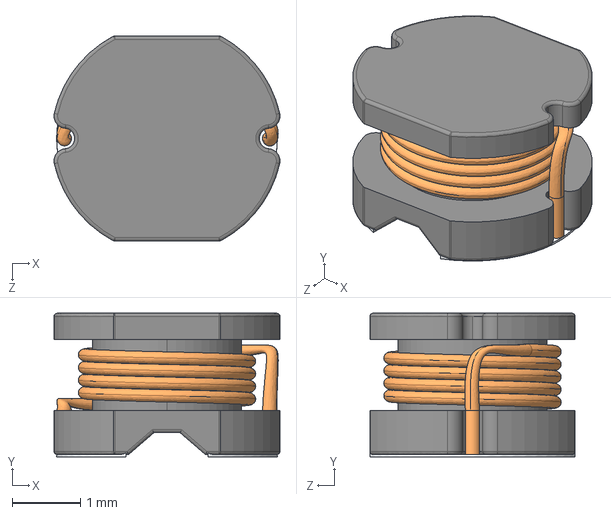
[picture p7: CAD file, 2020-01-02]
HARDWARE/REV-H/3d/CD32_inductor.step
3.30 x 2.10 x 3.00 mm

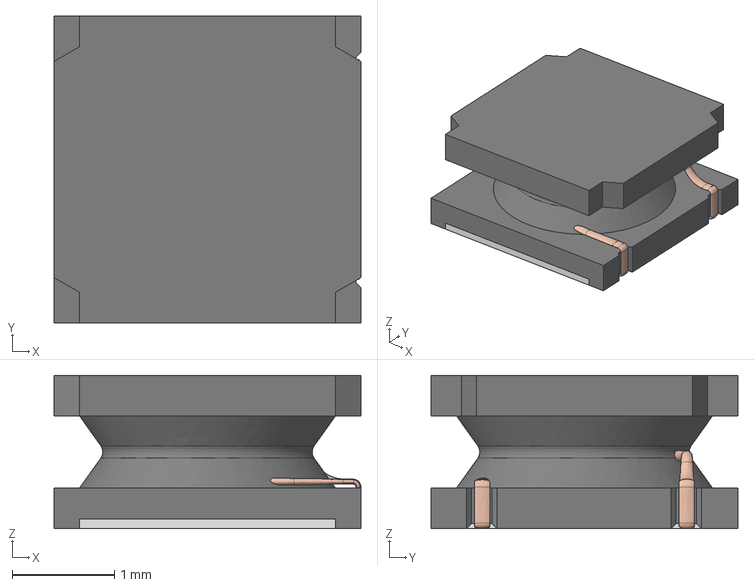
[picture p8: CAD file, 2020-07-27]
HARDWARE/REV-K2/3d/L-CD32_shielded.step
3.00 x 3.00 x 1.50 mm

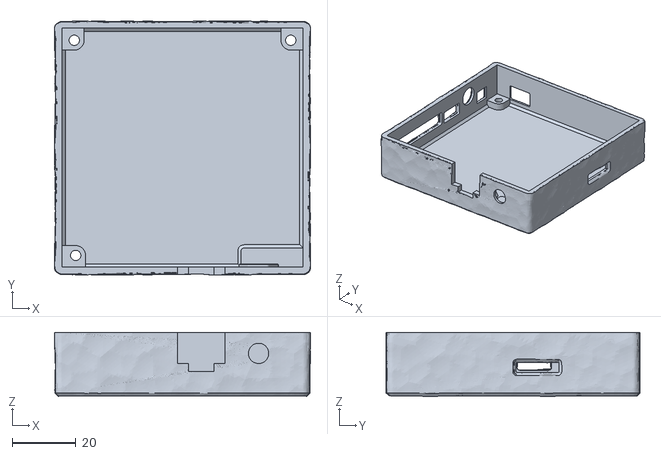
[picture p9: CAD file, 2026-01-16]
HARDWARE/BOX-DESIGN/bottom_v2_textured.stl
80.6 x 80.0 x 20.2

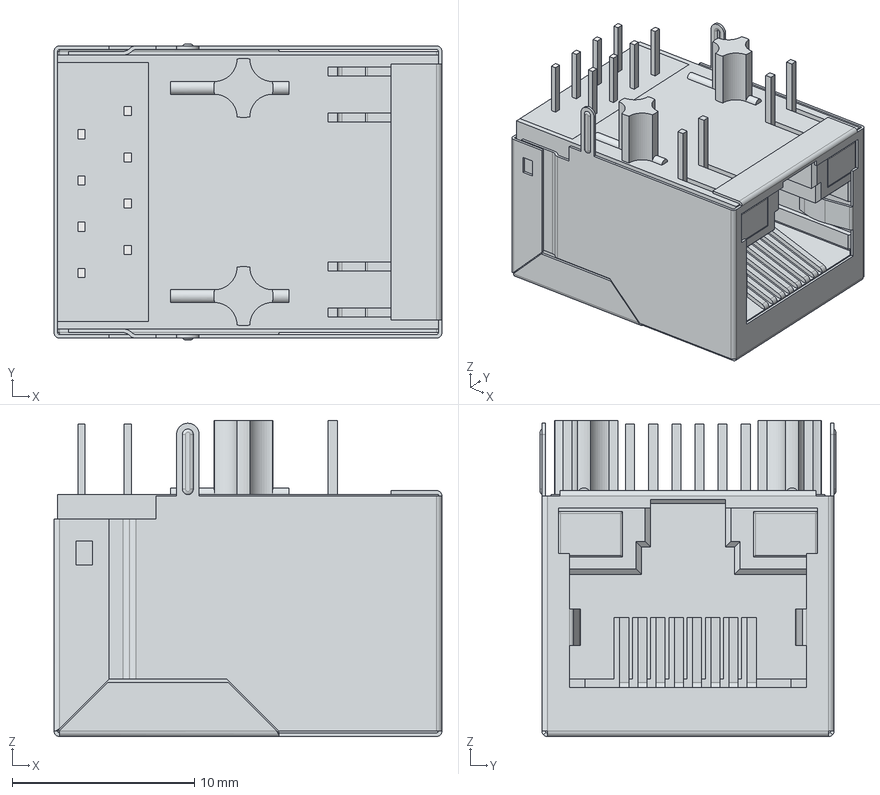
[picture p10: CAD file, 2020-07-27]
HARDWARE/REV-K2/3d/Connector_1Port_RJ45_Magjack_10-100Base-T_AutoMDIX_Wurth_Electronics-7499010441.stp
21.3 x 16.2 x 17.4 mm
Shielding
Insulator 3
Insulator 1
Insulator 2
Green_Yellow_LED x 2

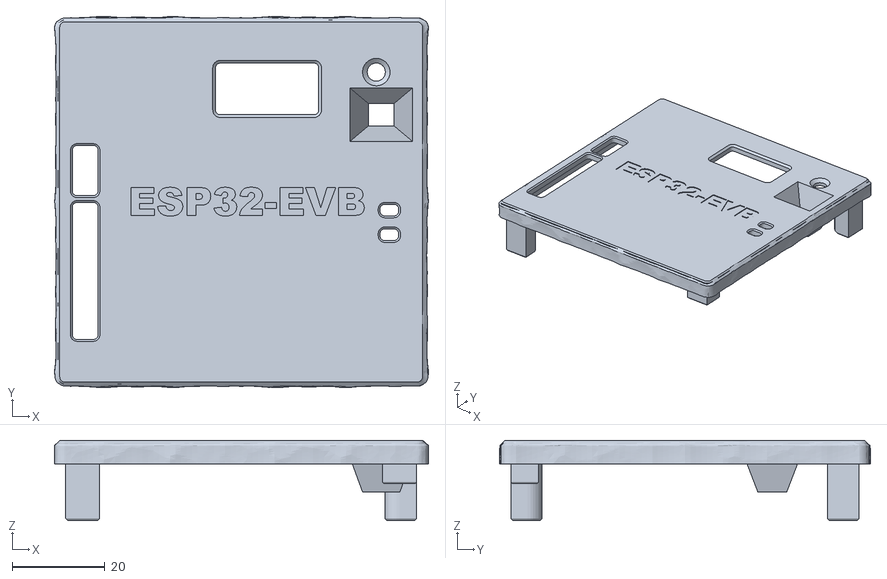
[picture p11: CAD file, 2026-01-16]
HARDWARE/BOX-DESIGN/top_v2_textured.stl
80.6 x 80.0 x 17.3

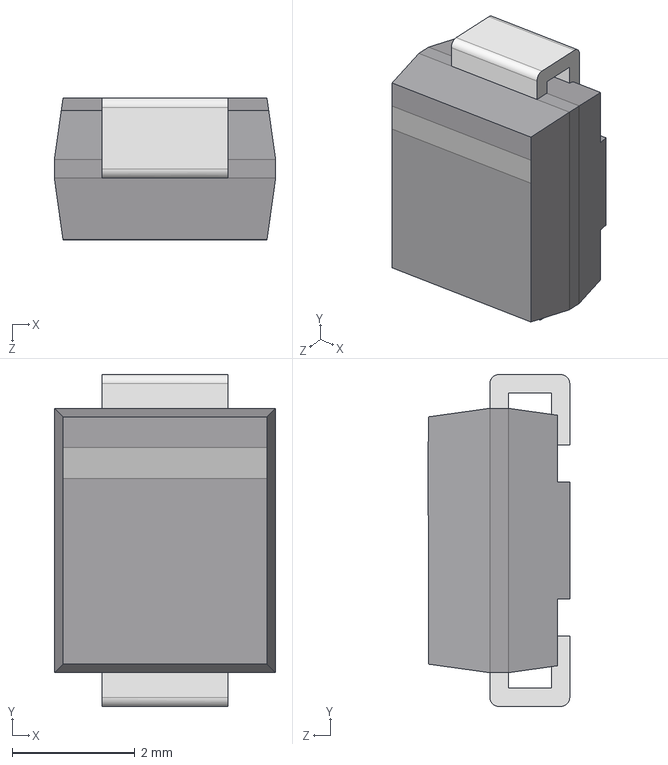
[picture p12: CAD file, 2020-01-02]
HARDWARE/REV-K2/3d/DO-214AA_SMB.step
3.60 x 5.40 x 2.30 mm

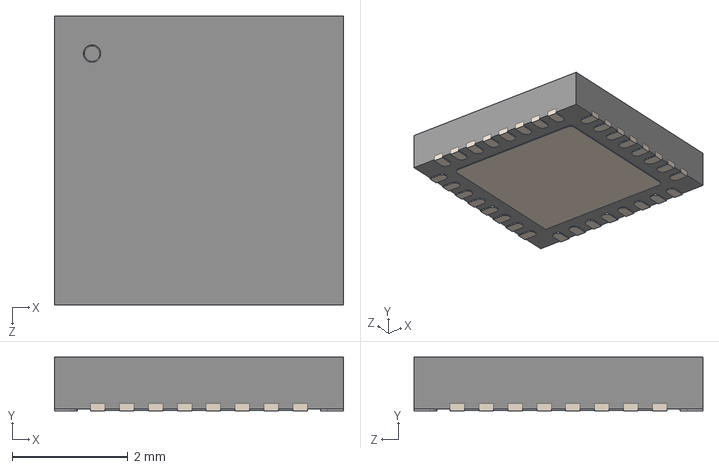
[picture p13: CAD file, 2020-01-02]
HARDWARE/REV-K2/3d/QFN32_5x5.step
5.00 x 0.93 x 5.00 mm

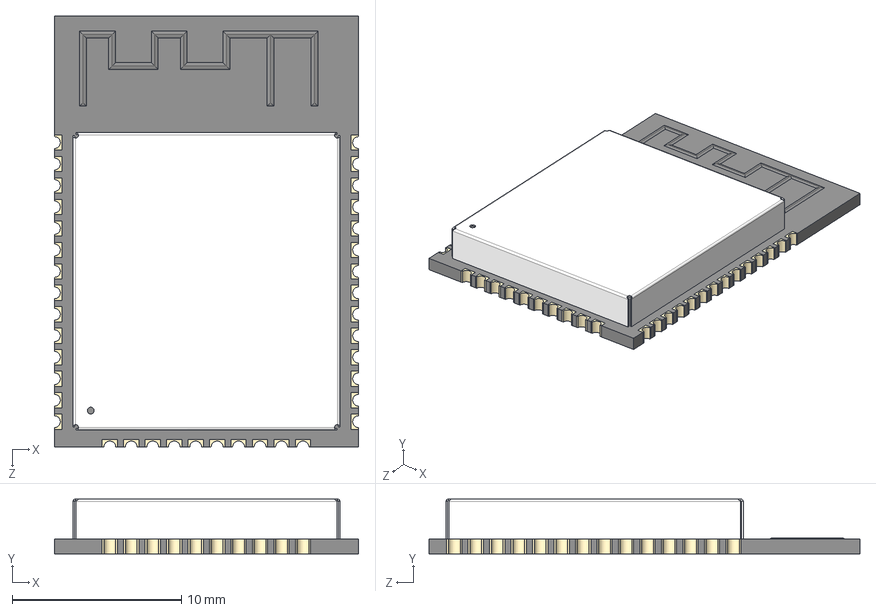
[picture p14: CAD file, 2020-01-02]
HARDWARE/REV-K2/3d/ESP32-WROOM-32D-56544.STEP
18.0 x 3.25 x 25.5 mm

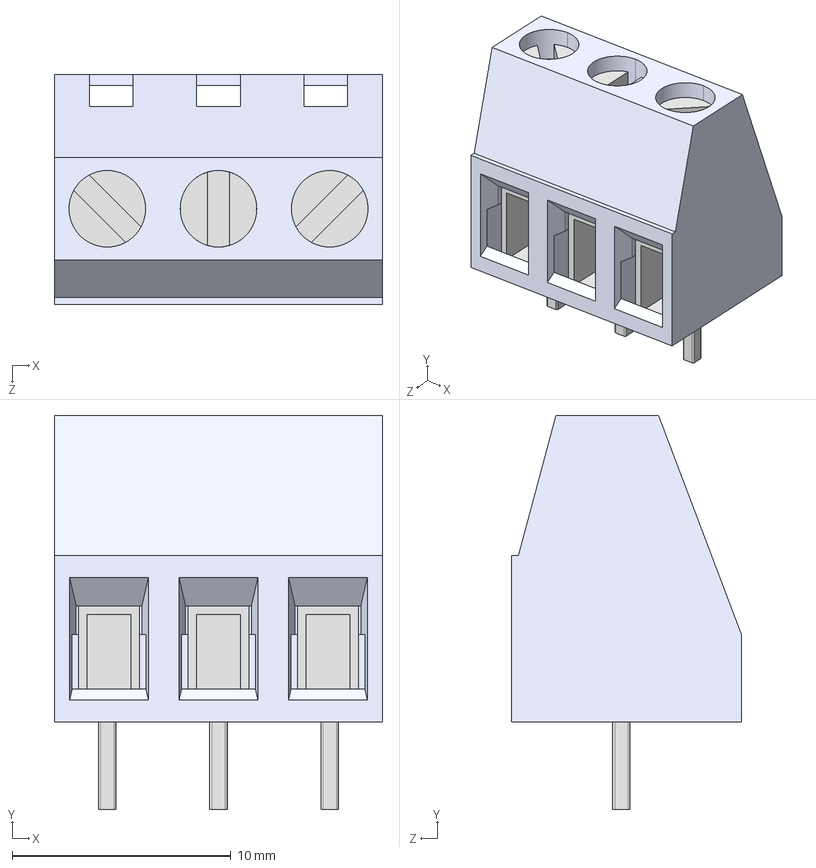
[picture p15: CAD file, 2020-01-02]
HARDWARE/REV-K2/3d/klema-5mm-3pin.step
15.0 x 18.0 x 10.5 mm

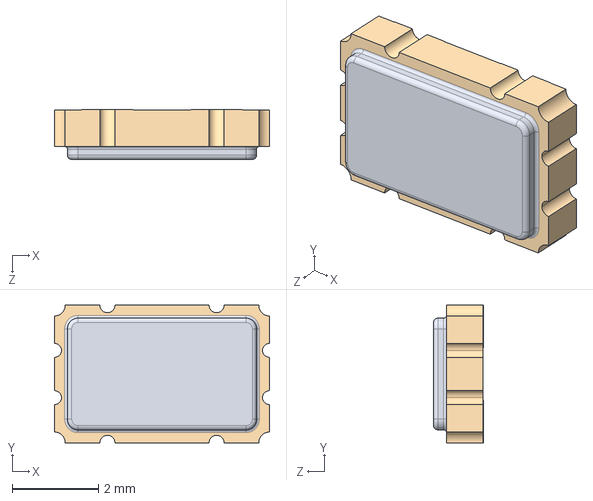
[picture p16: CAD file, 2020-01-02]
HARDWARE/REV-K2/3d/QSG5032.step
5.00 x 3.20 x 1.16 mm

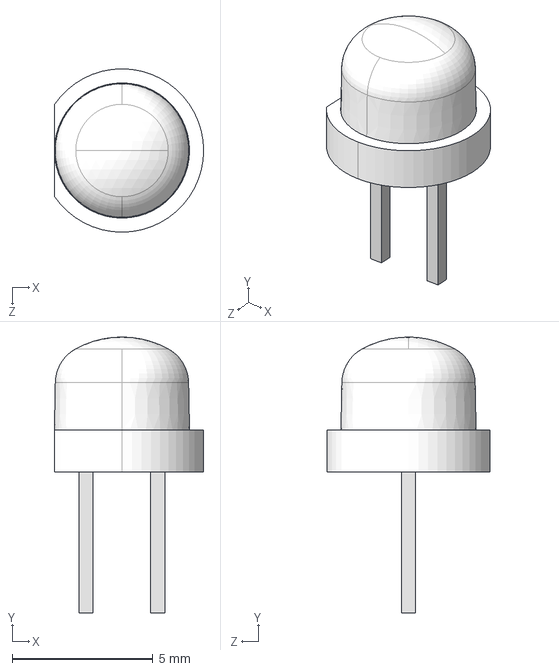
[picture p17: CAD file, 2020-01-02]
HARDWARE/REV-K2/3d/LED5mm_120.STEP
5.30 x 9.80 x 5.80 mm

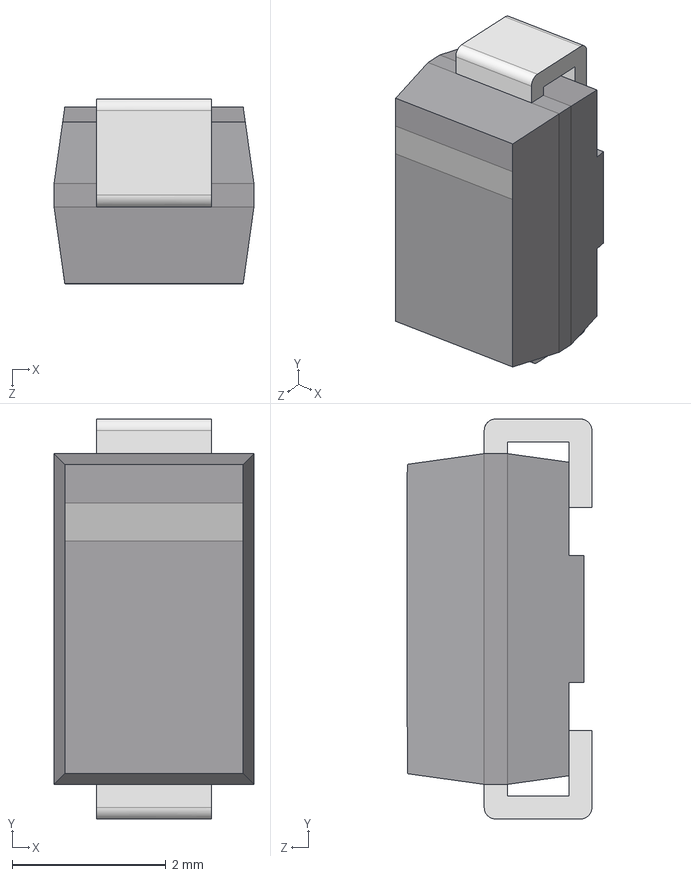
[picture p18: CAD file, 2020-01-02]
HARDWARE/REV-K2/3d/DO-214AC_SMA.step
2.60 x 5.20 x 2.40 mm

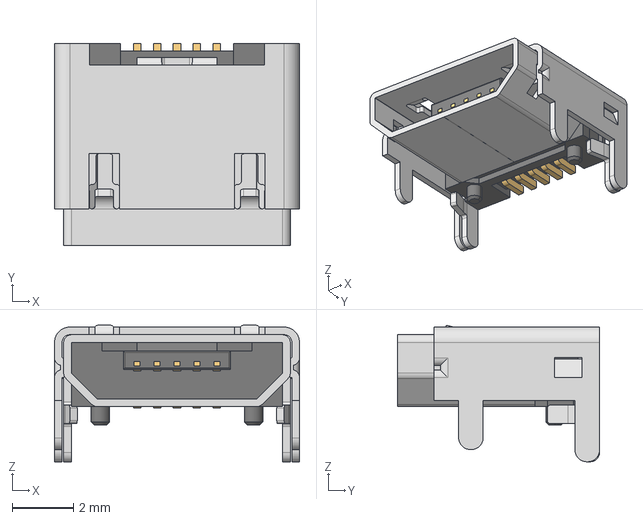
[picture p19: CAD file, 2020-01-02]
HARDWARE/REV-K2/3d/usb_micro_4p.stp
8.00 x 6.60 x 4.46 mm

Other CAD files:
HARDWARE/REV-K2/3d/User Library-GP1UE26.STEP
HARDWARE/REV-K2/3d/BAT54.step
HARDWARE/REV-K2/3d/TEConnectivity -ORWH-SH-124D1F000.stp
HARDWARE/REV-K2/3d/SOT-23-5.step
HARDWARE/REV-K2/3d/434121043836 (rev1).stp
HARDWARE/REV-K2/3d/5040771891.stp
HARDWARE/REV-K2/3d/BH-10__64.step
HARDWARE/REV-K2/3d/JST_B2B-PH-SM4-TB(DW02R).step
HARDWARE/REV-K2/3d/SO-8_150mil---SN65HVDA1050AQDRQ1.STEP
HARDWARE/REV-K2/3d/SOD123.step
HARDWARE/REV-K2/3d/SOT-23.step
HARDWARE/REV-K2/3d/User_Library-Crystal_HC49_US-SM.step
HARDWARE/REV-K2/3d/esp-wroom-32.step
HARDWARE/REV-K2/3d/pj-102ah.stp

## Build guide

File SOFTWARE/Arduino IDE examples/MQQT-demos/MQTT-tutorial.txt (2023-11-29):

MQTT examples between Olimex ESP32-EVB and public broker mqttx 

Each folder cotnains example with own ino file suitable for Arduino IDE. The four examples are:

ESP32-EVB_MQTT_GPIO - toggle relays and scans for the button state with commands via the MQTT app; uses WIFI for connecting to the internet;

ESP32-EVB_MQTT_GPIO_ETH - toggle relays and scans for the button state with commands via the MQTT app; uses Ethernet for connecting to the internet;

ESP32-EVB_MQTT_I2C - uses MOD-RTC module that is connected to the UEXT and I2C, allows to print data from MOD-RTC via the MQTT app using commands (time and date); uses WIFI for connecting;

ESP32-EVB_MQTT_I2C_ETH - uses MOD-RTC module that is connected to the UEXT and I2C, allows to print data from MOD-RTC via the MQTT app using commands (time and date); uses Ethernet for the Internet connection.

- Setting the ESP32-EVB with the code:

1. Pick one of the three Arduino examples. "ESP32-EVB_MQTT_GPIO" is easier to use since it requires no extra hardware. Demo allows to toggle the relays and also allows to scan the button state.
2. Edit the WIFI settings inside the example with the one of your WIFI network. 
3. Build the example and download it to the ESP32-EVB via Arduino IDE (remember to install the ESP32 for Arduino package, selected ESP32-EVB from the board selector).

- Setting the MQTT application:

1. Download the app from: https://mqttx.app/ and install it
2. Start the application
3. Create a "New Connection"
4. Enter a name and Client ID (they can be whatever)
5. Leave Host and Port with their default values: (mqtt://broker.emqx.io:1883)
6. Connect
7. Create a "New Subscription"
  7.1. At the Topic field you must enter the same topic that is defined in the Arduino sketch (for example: emqx/ESP32-EVB_GPIO). This is the topic you will listen to.
  7.2  At the bottom of the screen (just above the text box with the message) you type the same topic. This is the topic you will send to.
8. Click connect and you are ready to send and receive data.

Note: If you need, you can have multiple topics, from which you receive messages within the same connection.

Check the comments in the code for better understanding.

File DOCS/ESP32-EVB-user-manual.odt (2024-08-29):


ESP32-EVB

User Manual

Document revision 1.0, August 2024 | www. (http://www.olimex.com/)o (http://www.olimex.com/)limex.com (http://www.olimex.com/)

# 1. What is ESP32-EVB

ESP32-EVB is a mature Open Source Hardware development board that incorporates n ESP32 module. The ESP32-EVB board is designed and manufactured by Olimex, while the ESP32 module is designed and manufactured by Espressif systems. The ESP32 modules are extremely popular WIFI/BT modules due to their size, price, and very good documentation.

The ESP32-EVB board has the following features:

- ESP32-WROOM-32E or ESP32-WROOM-32UE module (depending on variant) with WiFi, BLE connectivity
- USB micro connector for powering and programming
- Built-in CH340T programmer for Arduino and ESP-IDF
- Ethernet 100Mb interface with ETH8710A
- MicroSD card
- 2x10A/250VAC (15A/120VAC 15A/24VDC) relays with connectors and status LEDs
- CAN transceiver and interface
- IR received and transmitter, up to 5 meters distance
- LiPo charger for stand alone operation during power breaks with 4 status LEDs
- Power jack for external power supply, 5V DC
- UEXT connector to for expansion modules
- Reset and user buttons
- GPIO 40 pin connector with all ESP32 ports
- Dimensions: (75x75)mm ~ (2.95x2.95)"
- Optional external antenna (-EA)
- Industrial grade -40+85C version available (-IND)

## 1.1 ESP32-EVB variants

The board has 4 variants – ESP32-EVB, ESP32-EVB-EA, ESP32-EVB-EA-IND, ESP32-EVB-IND. The base variant ESP32-EVB works in commercial temperature range (0-70 degrees C) and has on-module antenna.

ESP32-EVB and ESP32-EVB-IND come with ESP32-WROOM-32E module;

ESP32-EVB-EA and ESP32-EVB-EA-IND come with ESP32-WROOM-32UE and external antenna;

ESP32-EVB and ESP32-EVB-EA work in the commercial temperature range 0-70C;

ESP32-EVB-IND and ESP32-EVB-EA-IND are functionally identical, but have all components rated for operating in the industrial temperature range -40+85C.

## 1.2 Board use requirements

You only need a fitting USB cable and a personal computer. The board requires USB micro connector. Usually only such cable is required:

https://www.olimex.com/Products/Components/Cables/USB-CABLE-A-MICRO-1.8M/

The computer needs software compatible with ESP32 modules. Most commonly used tools are ESP-IDF and Arduino IDE with ESP32 package. You can use ESP32-EVB with any software tool that supports the main ESP32 module.

## 1.3 ESP32-EVB Open Source Licenses

ESP32-EVB is Open Source Hardware, listed in OSHWA.org here:

https://certification.oshwa.org/bg000011.html

The hardware files are released under CERN OSHW license (https://github.com/OLIMEX/USB-gLINK/blob/master/cern_ohl_s_v2.pdf).

The software is released under GPL 3 license (https://github.com/OLIMEX/USB-gLINK/blob/master/LICENSE).

The documentation is released under CC BY-SA 3.0 (https://creativecommons.org/licenses/by-sa/3.0/) license.

# 2. ESP32-EVB general layout

ESP32 module

Ethernet commector

Relay 2


UEXT connector

EXT header

Relay
terminals

CAN

terminal

Power jack

Li-Po
connector

Mount hole

Battery
LEDs

Micro USB

User

button

Reset

button

MicroSD

card holder

Infrared

User LED

# 3. ESP32-EVB power supply and consumption

ESP32-EVB typically consumes between 40mA and 200mA of current depending on the software. The board can consume much less using the power saving modes.

The absolute maximum power ESP32-EVB can draw from the power supply would be the determined by the maximum input of the regulator on the power input line. Of course, consider that on-board peripherals and the main module would use some of that current. There are two major cases:

1) If you power the board from the PWR jack or the USB – > the regulator is SY8089 can output maximum 2000mA continuously

2) If you power the board from battery –> the Li-Po battery charger MCP73833 can output up to 1200mA

# 4. ESP32-EVB schematics and dimensions

ESP32-EVB was designed with KiCAD (free and open-source CAD tool). ESP32-EVB schematics and sources can be found at GitHub here:

https://github.com/OLIMEX/ESP32-EVB/tree/master/HARDWARE

There are also PDF exports if you don’t want to install KiCAD.

Board dimensions can be found here:

https://github.com/OLIMEX/ESP32-EVB/blob/master/HARDWARE/ESP32-EVB_dimensions.pdf

# 5. ESP32-EVB pinout description:

The board doesn’t have many free pins, most of the free pins are available at the UEXT connector. Even at the UEXT some of the pins are multiplex with the SD card, meaning that if you have SD card attached these won’t work.

The ESP32 chip has very good multiplexer so you can set the free GPIO pins for alternative functions via software means.

The SD card interface is in 1-bit eMMC mode.

The CAN is controlled by SIT1050T (different hardware revisions might use different CAN transceiver chip) and by default the CAN terminating resistor is disconnected. If this is end CAN device (or if you just have 2 CAN devices on that bus) it is good idea to close it. Solder CAN_T1 jumper to connect the terminating resistor.

# 6. ESP32-EVB software installation

Esspresif guide for Arduino IDE installation (https://docs.espressif.com/projects/arduino-esp32/en/latest/installing.html) – after installation – there is own entry for the board, it should be listed as OLIMEX ESP32-EVB in the board selection

Espressif ESP-IDF installation (https://github.com/espressif/esp-idf)

Esspressif guide for PlatformIO installation (https://docs.espressif.com/projects/arduino-esp32/en/latest/installing.html).

Olimex provides some ESP-IDF and Arduino examples here:

https://github.com/OLIMEX/ESP32-EVB/tree/master/SOFTWARE

# 7. Document revision history

Revision 1.0 August 2024

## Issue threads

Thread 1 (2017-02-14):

Здравейте!

me-no-dev, 2017-02-14:
Здравейте!
Казвам се Христо Гочков, работя за Еспресиф и в частност съм отговорен за Ардуино средата за ЕСП32. Понеже сме си сънародници :) реших да ви пиша и да ви кажа че ще се радвам ако можем да сме си полезни, пък и да ви оставя контакт :) Ако имате въпроси относно контролерите, не се колебайте да ги зададете.

ESP32DE, 2017-02-15:
Fine! You are welcome Christo ;-)

best wishes
rudi ;-)

TsvetanUsunov, 2017-02-15:
Здрасти, прати един имейл на info @ olimex com

stankow, 2018-09-04:
Малко късно попадам на тази поща, чак след година. Работим с ESP32, много сме доволни ! Ценим много вашият принос ! Прехвърляме наш код от предишни Ардуино проекти и вашите библиотеки за ESP32 добре ни идват !  Поздрави, успех !

me-no-dev, 2018-09-04:
Нищо :) тя офертата си е валидна и сега

Closed 2017-07-19.

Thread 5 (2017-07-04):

Error in naming on schematics - IR block GPIO39 misnamed (lack of letter) :)

Netoperz, 2017-07-04:
as in title.

:)

DanKoloff, 2017-07-05:
I don't understand what do you mean. What is wrong and how should it be corrected?

DanKoloff, 2017-08-17:
I would close this since I believe what @Netoperz meant is that GPI36 should be named GPIO36; which is not very correct since it can be only input (it can't be output); so GPI is a more fitting abbreviation.

Netoperz, 2017-08-24:
Yes, the pin is input only in arduino ide. but can be innput/outp[ut if using driver on espressif ide. so naming it GPI is fine because normally without any magic it is input only.

Issu should be closed.

DanKoloff, 2017-08-25:
I am not happy with your explanation which might perplex someone reading this. The input/output availability has nothing to do with Arduino IDE, or ESP-IDF. In order to clarify I would cite version 1.7 of ESP32's datasheet, page 36:

"GPIO pins 34-39 are input-only. These pins do not feature an output driver or internal pullup/pull-down
circuitry. The pin names are: SENSOR_VP (GPIO36), SENSOR_CAPP (GPIO37), SENSOR_CAPN (GPIO38), SENSOR_VN (GPIO39), VDET_1 (GPIO34), VDET_2 (GPIO35)."

Closed 2017-08-17.

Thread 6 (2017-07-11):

USB-UART Circuit

Ayush123Singh, 2017-07-11:
Hi,
I am new to ESP32 and i am having some doubt in USB-UART circuit, what are the uses of DTR, DSR, RTS, CTS pin in CP2102.
If i have asked some obviously simple question then sorry for inconvenience but little help will be very much appreciated. Thanks.

StefanMavrodiev, 2017-07-12:
We are using CH340T, not CP2102.
CTS and DSR pins are not used.

On the schematic there is table about the work of DTR and RTS pins.
In short:
DTR = 1, RTS = 0 - the board is in reset
DTR = 0, RTS = 1 - GPIO0 is pulled low

carhero, 2017-07-12:
Are you having trouble to connect ESP32-EVB with windows?
If so please refer below.
https://github.com/OLIMEX/ESP32-EVB/issues/8

here is direct link for CH340T
http://www.winchiphead.com/download/CH341/CH341SER.ZIP

Closed 2017-08-17.

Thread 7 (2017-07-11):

SD card is not working!

pbecchi, 2017-07-11:
There is no documentation or example, but in EVB board rev B , the SD adapter is showing a SPI connection but SS pin is not connected to any GPio and is pulled up!
To allow communication from the SD, SS should be connected and/or pulled down.

Any other way to make it work?

StefanMavrodiev, 2017-07-12:
SS should be connected if you're using SD card in SPI mode, which is unnecessary. SD protocol needs only 3 pins: CMD, DATA0 and CLK.

You can check Physical Layer Simplified Specification here:
https://www.sdcard.org/downloads/pls/index.html

We will upload SD-card example later today.

StefanMavrodiev, 2017-07-12:
You can see working example here:
https://github.com/OLIMEX/ESP32-EVB/tree/master/SOFTWARE/sd_card

Here is the example output:

```
I (967) example: Initializing SD card
Name: SL08G
Type: SDHC/SDXC
Speed: default speed
Size: 7580MB
CSD: ver=1, sector_size=512, capacity=15523840 read_bl_len=9
SCR: sd_spec=2, bus_width=5
I (1137) example: Opening file
I (1247) example: File written
I (1317) example: Renaming file
I (1347) example: Reading file
I (1357) example: Read from file: 'Hello SL08G!'
I (1357) example: Card unmounted
```

pbecchi, 2017-07-12:
I have tested your example : it work only one time over ten trial......don't ask me why.
Arduino-core SdMMc example never work and it should!
May be you closed the issue too soon!

StefanMavrodiev, 2017-07-12:
> it work only one time over ten trial......don't ask me why.
You don't know or you won't tell us?

If you do the same change in the arduino library, example should work:

https://github.com/espressif/arduino-esp32/blob/master/libraries/SD_MMC/src/SD_MMC.cpp
```
host.max_freq_khz = SDMMC_FREQ_HIGHSPEED;
//host.flags = SDMMC_HOST_FLAG_1BIT; //use 1-line SD mode
```
to

```
host.max_freq_khz = SDMMC_FREQ_PROBING;
host.flags = SDMMC_HOST_FLAG_1BIT; //use 1-line SD mode
```

pbecchi, 2017-07-12:
Yes thanks
It is what I did , in my case it didn't work! May be you have to try this yourself.
Major problem anyhow is reliability : your code it doesn't work all the time.
I doubt may be due to the default pin left unconnected and may be used by other applications.

StefanMavrodiev, 2017-07-12:
Here is my output.

```
rst:0x10 (RTCWDT_RTC_RESET),boot:0x1b (SPI_FAST_FLASH_BOOT)
configsip: 0, SPIWP:0x00
clk_drv:0x00,q_drv:0x00,d_drv:0x00,cs0_drv:0x00,hd_drv:0x00,wp_drv:0x00
mode:DIO, clock div:1
load:0x3fff0008,len:8
load:0x3fff0010,len:160
load:0x40078000,len:10632
load:0x40080000,len:252
entry 0x40080034
SD_MMC Card Type: SDHC
SD_MMC Card Size: 7580MB
                        Listing directory: /
                                              FILE: /test.txt  SIZE: 0
  FILE: /foo.txt  SIZE: 13
Creating Dir: /mydir
                    Dir created
Listing directory: /
                      FILE: /test.txt  SIZE: 0
  FILE: /foo.txt  SIZE: 13
  DIR : /mydir
Removing Dir: /mydir
                    Dir removed
Listing directory: /
                      FILE: /test.txt  SIZE: 0
  FILE: /foo.txt  SIZE: 13
Writing file: /hello.txt
                        File written
Appending to file: /hello.txt
                             Message appended
Reading file: /hello.txt
                        Read from file: Hello World!
                                                    Deleting file: /foo.txt
                                                                           File deleted
Renaming file /hello.txt to /foo.txt
                                    File renamed
Reading file: /foo.txt
                      Read from file: Hello World!
                                                  0 bytes read for 0 ms
                                                                       1048576 bytes written for 25351 ms

```

Maybe there is something wrong with the SD-card?

pbecchi, 2017-07-12:
The main problem is in HW.
I guess is probably a contact from card holder and SD. Moving the SD card goes and fail.
I tried also with core SdMMc library with similar results : could be the holder of the SD but I tried with several SD.
I had also a problem of SD non written by the SW (with no error) probably because it was a Fat32 SD.

StefanMavrodiev, 2017-07-12:
Could you try several tests, while you press the SD card towards the board?

pbecchi, 2017-07-12:
Done several test, unfortunately I have only 2 SD formatted FAT16 :
for booth moving SD sideways (perpendicular to insertion movement) create bad or good contact.
This may be due to an holder too large or due to two narrow SD.

quikue, 2019-02-11:
Sorry,
:)
I have the problem of I can use SPI with SD_MMC,
I understand that the pinout is:
MISO 02
MOSI 15
CLK    14
CHIP SELECT CS0 14
But that also need a SPI with four wires.

Can you help me?

Thanks!

quikue, 2019-02-11:
Sorry,
:)
I have the problem of I can't use SPI with SD_MMC,
I understand that the pinout is:
MISO 02
MOSI 15
CLK 14
CHIP SELECT CS0 14
But that also need a SPI with four wires.

Can you help me?

Thanks!

bioshock2k, 2020-10-24:
Hi, did anyone had it working with the Arduino IDE?

teson2000, 2023-08-24:
SD_CARD working in Arduino IDE when changing library from SD to MMC.
(This fixes the 4-bit vs 1-bit problem)
Likewise, any references to SD needs to be changed to MMC. Working example:

```
#include "SD_MMC.h"
#include "SPI.h"

void initSDCard(){
  if(!SD_MMC.begin("/sdcard",true)) {
    Serial.println("Card Mount Failed");
    return;
  }
  uint8_t cardType = SD_MMC.cardType();

  if(cardType == CARD_NONE){
    Serial.println("No SD card attached");
    return;
  }

  Serial.print("SD Card Type: ");
  if(cardType == CARD_MMC){
    Serial.println("MMC");
  } else if(cardType == CARD_SD){
    Serial.println("SDSC");
  } else if(cardType == CARD_SDHC){
    Serial.println("SDHC");
  } else {
    Serial.println("UNKNOWN");
  }
  uint64_t cardSize = SD_MMC.cardSize() / (1024 * 1024);
  Serial.printf("SD Card Size: %lluMB\n", cardSize);
}

void setup() {
  delay(1000);
  Serial.begin(115200);
  initSDCard();
}

void loop() {

}
```

gjt211, 2023-09-15:
@teson2000, thanks kindly - I have been trying to get this to work for hours. The SD_MMC example works for me.

Closed 2017-08-25.

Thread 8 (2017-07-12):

Is there USB2.0-Serial driver files?

carhero, 2017-07-12:
When I insert micro USB into ESP32-EVB(Rev.B), PC does not recognize this device.
I prefer to develop in windows os not linux.
Is there USB2.0-Serial driver file for manual installing?
I'm using windows 7 os.

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

carhero, 2017-07-12:
It is cleared with below USB driver for windows.
http://www.winchiphead.com/download/CH341/CH341SER.ZIP

Closed 2017-07-12.

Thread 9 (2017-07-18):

MicroPython compatibility?

riklaunim, 2017-07-18:
I wonder if someone tried flashing this board with MicroPython for ESP32 and if so - which features are supported out of the box?

magantiakhilchandra, 2018-06-08:
Well I was trying to use CAN. No modules for that. Says we can export a CAN module on to it and import but, I was not sucessful

DanKoloff, 2018-06-08:
For the CAN look here: https://github.com/OLIMEX/ESP32-EVB/tree/master/SOFTWARE/CAN_demo

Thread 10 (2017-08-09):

Flash / monitor failure

jonface, 2017-08-09:
I am getting the following errors when trying to flash and use monitor, unit is brand new.

The default linux ch341 driver gave me input/output error when trying to open the serial port. I've compiled and inserted the ch34x driver from your website which at least allows me to open the serial port.

Any ideas? Broken unit?

Thanks

```
/hello_world$ make flash
Flashing binaries to serial port /dev/ttyUSB0 (app at offset 0x10000)...
esptool.py v2.1-beta1
Connecting........_____....._____....._____....._____....._____....._____....._____....._____....._____....._____

A fatal error occurred: Failed to connect to ESP32: Timed out waiting for packet header
/home/jmasters/Downloads/xtensa-esp32-elf/esp-idf/components/esptool_py/Makefile.projbuild:52: recipe for target 'flash' failed
make: *** [flash] Error 2
```

```
MONITOR
--- idf_monitor on /dev/ttyUSB0 115200 ---
--- Quit: Ctrl+] | Menu: Ctrl+T | Help: Ctrl+T followed by Ctrl+H ---
ets Jun  8 2016 00:22:57

rst:0x1 (POWERON_RESET),boot:0x1b (SPI_FAST_FLASH_BOOT)
flash read err, 1000
Falling back to built-in command interpreter.
OK
>ets Jun  8 2016 00:22:57

rst:0x10 (RTCWDT_RTC_RESET),boot:0x1b (SPI_FAST_FLASH_BOOT)
flash read err, 1000
Falling back to built-in command interpreter.
OK
>ets Jun  8 2016 00:22:57

rst:0x10 (RTCWDT_RTC_RESET),boot:0x1b (SPI_FAST_FLASH_BOOT)
flash read err, 1000
Falling back to built-in command interpreter.
OK
>ets Jun  8 2016 00:22:57

... This goes on forever
```

```
Linux vmxubuntu16 4.4.0-45-generic #66-Ubuntu SMP Wed Oct 19 14:12:37 UTC 2016 x86_64 x86_64 x86_64 GNU/Linux
```

`chmod 777 on /dev/ttyUSB0`

jonface, 2017-08-09:
I have also tried from an un powered USB hub and powered. Also external 5v.

DanKoloff, 2017-08-14:
The re-occurring message is not surprising ("flash read err, 1000"). The board comes with empty flash.

It is more interesting why the programming fails. Probably very high baud rate (try with lower) or bad USB port (try with another USB port).

jonface, 2017-08-14:
OK, I setup the environment using the windows UART drivers, Arduino IDE and it is flashing fine @ 115200

I think, at a guess, it is the linux UART driver, even at 9600 I get nothing. I might try Wireshark at some point and check, if anything, what the USB port is doing.

The main thing is the hardware is working, feel free to close this.

Thanks

DanKoloff, 2017-08-14:
By default Linux should come with properly working ch34x driver. The driver that we published is only for old kernels older than version 3.14. Your ubuntu has kernel 4.4.0+ and doesn't need this driver.

jonface, 2017-08-16:
I've tried again, with the built in HL-340 driver,

`1a86:7523 QinHeng Electronics HL-340 USB-Serial adapter`

monitor is working, I understand what you meant previously now about the error, as I can see the serial output fine from the application, but flashing still doesn't work (tried 9600/115200)

```
Flashing binaries to serial port /dev/ttyUSB0 (app at offset 0x10000)...
esptool.py v2.1-beta1
Connecting........_____....._____....._____....._____....._____....._____....._____....._____....._____....._____

A fatal error occurred: Failed to connect to ESP32: Timed out waiting for packet header
/home/jmasters/Downloads/xtensa-esp32-elf/esp-idf/components/esptool_py/Makefile.projbuild:52: recipe for target 'flash' failed
make: *** [flash] Error 2
```

I'm assuming this isn't technically a problem with the ESP32-EVB so I should really head over to the ESP github?

Thanks

DanKoloff, 2017-08-16:
Since you managed to program it via the Arduino, I'd guess the problem is not in the hardware.

jonface, 2017-08-16:
Closing as problem not specific to Olimex ESP32-EVB.

Thanks.

Closed 2017-08-16.

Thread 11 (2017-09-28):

Emac rx buff err in ETH example

gjongenelen, 2017-09-28:
Hello,

I bought a ESP21-EVB Rev.C  board and am trying to run the ETH_PHY_demo program. Connection to the PHY is established, but I'm getting the following error:
`E (137287) emac: emac rx buf err!!`

Is this a result of using Rev.B examples on a Rev.C board?

No IP is assigned to the ethernet-port via DHCP btw.

DanKoloff, 2017-09-29:
The software example was written for older version of ESP-IDF, it needs to be updated, for now follow the advice I posted here until we fix it: https://github.com/OLIMEX/ESP32-GATEWAY/issues/3

gjongenelen, 2017-10-09:
Thanks, it works

jovermann, 2017-12-13:
I see the same issue with the Olimex ETH_PHY_demo (also using a Rev C board). I can also confirm that the workaround pointed to by the link above works.

Concretely, the workaround is:
1. Use the ethernet example provided with the esp-idf. Do not use the ETH_PHY_demo at all.
2. Use these settings in make menuconfig:
CONFIG_PHY_TLK110=
CONFIG_PHY_LAN8720=y
CONFIG_PHY_ADDRESS=0
CONFIG_PHY_CLOCK_GPIO0_IN=y
CONFIG_PHY_CLOCK_GPIO0_OUT=
CONFIG_PHY_CLOCK_GPIO16_OUT=
CONFIG_PHY_CLOCK_GPIO17_OUT=
CONFIG_PHY_CLOCK_MODE=0
CONFIG_PHY_USE_POWER_PIN=
CONFIG_PHY_SMI_MDC_PIN=23
CONFIG_PHY_SMI_MDIO_PIN=18

DanKoloff, 2018-03-27:
The examples had been updated and should work properly with the latest ESP-IDF.

Closed 2018-06-07.

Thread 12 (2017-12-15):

EXT1 and USB-UART1 are too close

Miceuz, 2017-12-15:
It is impossible to use 40 pin IDC shrouded header for EXT1 as USB connector is too close.

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

It is possible to trick it into semi-usable configuration, but pin numbering is screwed up in this case and ultra-thin usb connector has to be used.

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

So basically, the only workaround is to use 34 pin connector and loose access to +5V and +3.3V.

Otherwise, thank you for this board. We are using it to build an electronic lock in our hackerspace.

DanKoloff, 2018-09-27:
This is not the connector we had in mind during the design. The schematic of the board says what is the component that we had in mind while designing these pinholes - it is HN2X20 (and the NA is short from Not Assembled). Search for "HN2x20 connector" to see such products.

The pinholes were meant to be used with male connectors like these: https://www.olimex.com/Products/Components/Connectors/MALE-PAV16X-2x05/ - they have a plastic base that would lift it above the micro USB connector and would allow connecting a female.

Closed 2018-09-27.

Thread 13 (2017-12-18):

ESP32-EVB Non-Evaluation board

Elkrival, 2017-12-18:
Hello Olimex,

Is there a production ready version of this board?

Best,

Ivan

DanKoloff, 2017-12-18:
What does this mean? Like stripped down version of ESP32-EVB with less features?

Elkrival, 2017-12-18:
On the Olimex website there's this notice.

 Evaluation Board/Kit Important Notice

OLIMEX Ltd provides the enclosed product(s) under the following conditions:

This evaluation board/kit/module is intended for use for ENGINEERING DEVELOPMENT, DEMONSTRATION OR EVALUATION PURPOSES ONLY and is not considered by OLIMEX Ltd to be finished end-product fit for general consumer use. Persons handling the product must have electronics training and observe good engineering practice standards. As such the goods being provided are not intended to be complete in terms of required design-, marketing-, and/or manufacturing related protective considerations, including product safety and environmental measures typically found in the products that incorporate such semiconductor components or circuit boards. This evaluation board/kit/module does not fall within the scope of the European Union directives regarding electromagnetic compatibility, FCC, CE or UL and therefore may not meet the technical requirements of these directives or other related documents.

The user assumes all responsibility and liability for proper and safe handling of the goods. Further the user indemnifies OLIMEX from all claims arising from the handling or use of the goods. Due to the open construction of the product, it's the user responsibility to take any and all appropriate precautions with regard to electrostatic discharge, conducted and radiated emissions.

EXCEPT TO THE EXTENT OF THE INDEMNITY SET FORTH ABOVE NEITHER PARTY SHALL BE LIABLE TO THE OTHER FOR ANY INDIRECT SPECIAL INCIDENTAL OR CONSEQUENTIAL DAMAGES.

I wanted to know if there's a model of this board that is not only for development.

DanKoloff, 2017-12-18:
This is the only version of the ESP32-EVB board (we have a variant called ESP32-GATEWAY). We have the exact same notice under ALL of our products. Feel free to use the product for professional purposes, a lot of people embed our boards in their designs. There are reasons for the notice, but I bet you can find why it is there yourself.

Elkrival, 2017-12-18:
Appreciate the help and Thank you for the quick response!

Closed 2017-12-18.

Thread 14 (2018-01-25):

ETH-PHY  demo doesn't work

hexanet67, 2018-01-25:
Hi,

I'm trying ETH_PHY_demo on Olimex ESP32-EVB. No problem with compilation, but when flash compiled firmware, yellow led on ETH connector start flashing and I can see thi in terminal log window:

`I (257) cpu_start: Pro cpu start user code
I (275) cpu_start: Starting scheduler on PRO CPU.
I (0) cpu_start: Starting scheduler on APP CPU.
I (277) emac: mac version 1137a
I (277) emac: emac start !!!

I (277) emac: emac reset done
I (287) system_api: Base MAC address is not set, read default base MAC address from BLK0 of EFUSE
E (1297) emac: Timed out waiting for PHY register 0x2 to have value 0x0007 (mask 0xffff). Current value 0xffff
E (2297) emac: Timed out waiting for PHY register 0x3 to have value 0xc0f0 (mask 0xfff0). Current value 0xffff
E (3297) emac: Timed out waiting for PHY register 0x2 to have value 0x0007 (mask 0xffff). Current value 0xffff
E (4297) emac: Timed out waiting for PHY register 0x3 to have value 0xc0f0 (mask 0xfff0). Current value 0xffff
E (5297) emac: Timed out waiting for PHY register 0x2 to have value 0x0007 (mask 0xffff). Current value 0xffff
E (6297) emac: Timed out waiting for PHY register 0x3 to have value 0xc0f0 (mask 0xfff0). Current value 0xffff
E (7297) emac: Timed out waiting for PHY register 0x2 to have value 0x0007 (mask 0xffff). Current value 0xffff
`
I have also tried with external power supply 5V/2A but results are the same.
Any idea how to get ethernet working ?

Regards,

    Jan

DanKoloff, 2018-01-26:
Take a look here: https://github.com/OLIMEX/ESP32-EVB/issues/11

hexanet67, 2018-01-26:
Hi,
thank you for a quick reply.
I did what is described in 'Emac rx buff err in ETH example #11' and I can confirm that it worked for me.
I was trying original ethernet example in esp-idf before, but probably didn't set all configuration options correctly.
Regards,
    Jan

Closed 2018-01-26.

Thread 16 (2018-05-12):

Error While opening PCB Design file

Karthick1994, 2018-05-12:
EAGLE
Error:

line 1, column 1: Start tag expected.

DanKoloff, 2018-05-21:
Are you trying to open the hardware sources with Eagle? The design of ESP32-EVB is made with KiCAD - it is open source and free to download. Make sure to get the latest nightly build (the latest stable release might not be recent enough to open the design without problems).

Closed 2018-05-21.

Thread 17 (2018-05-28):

Guys if you use KiCad nightly please at least give the version you used in the readme!

poeschlr, 2018-05-28:
Projects created with nightlies are only guaranteed to work with that one version. Earlier nightlies and all stable releases will most likely not be able to open it.
Even a later nightly builds can struggle as sometimes a file format modification is later removed again.

_This has happened once in the version 5 development cycle. There where a few days where the 3d model offset value [at] used mm instead of inches. Later the at value was again used for inches whereas a new field was introduced for the metric stuff [offset]. So if you would open a project that was created within these few days with any other version of kicad, you would get the wrong 3d model offset._

---

It seems at least Rev D is made with a recent nightly. So with luck it is one from after the feature freeze. (Meaning the dangers described above should be minimized.)

TsvetanUsunov, 2018-05-29:
KiCAD always embed the version which is used in the first line of PCB and SCH files:

(kicad_pcb (version 20170123) (host pcbnew "(2017-04-24 revision 50716c901)-makepkg")

Closed 2018-05-29.

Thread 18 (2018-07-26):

ethernet can't be connected with ethernet

shubham7946, 2018-07-26:
This type of error is coming while connecting with LAN to olimex.My connected network is of DHCP type.

E (1323) emac: Timed out waiting for PHY register 0x2 to have value 0x2000 (mask 0xffff). Current value 0xffff
E (2323) emac: Timed out waiting for PHY register 0x3 to have value 0xa210 (mask 0xfff0). Current value 0xffff
E (3323) emac: Timed out waiting for PHY register 0x2 to have value 0x2000 (mask 0xffff). Current value 0xffff
E (4323) emac: Timed out waiting for PHY register 0x3 to have value 0xa210 (mask 0xfff0). Current value 0xffff

Kindly suggest me solution.

DanKoloff, 2018-07-26:
Did you try using exactly this demo: https://github.com/OLIMEX/ESP32-EVB/tree/master/SOFTWARE/ETH_PHY_demo ?

maqtech, 2018-10-03:
Hi I tried to use the demo with a REV C, but the board does not connect to ethernet, could you please support me!

DanKoloff, 2018-10-04:
What exactly happens? Is there some error message or where does it stop?

DanKoloff, 2020-07-17:
Closing due to lack of reply and details. If the problem remains and new details emerge I'd reopen it.

Closed 2020-07-17.

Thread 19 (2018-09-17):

The BOM does not have a suggested part number for the CR1

tracemils, 2018-09-17:
Can the BOM be more detailed with suggested part numbers

DanKoloff, 2018-09-18:
We can't recommend parts that we haven't used and the parts that we use are wholesale - you can't find then nor purchase small volumes. That is why we provide details on what to search for. In the case of the oscillator search for Q50MHz/25ppm/3V/4P/5x3.2mm.

I have narrowed it down to this search: https://www.digikey.com/short/jwhtbm

DanKoloff, 2020-07-17:
Seems answered, closing this issue.

Closed 2020-07-17.

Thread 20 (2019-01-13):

CAN Demo Speed & Power Requirements

steffeng, 2019-01-13:
I'm trying to get the CAN demo running with the code provided. When monitoring I see the "Can Init done" message but no can bus or error messages are printed.

As my bus is using 20kbps, I changed the range of CAN_SPEED_USER_KBPS_VAL. Does the Rev. D work with this speed as well. Why is this set to a minimum of 50kbps?

My board is powered by USB, does the CAN adapter need additional power?

steffeng, 2019-08-27:
[ESP32 CAN documentation](https://docs.espressif.com/projects/esp-idf/en/latest/api-reference/peripherals/can.html) lists valid values for parameters that determine the bitrate:

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

So maximum number of time quanta is 25 (1 + 16 + 8), which would need an unsupported brp of 80000000 / (20000 * 25) = 160. The minimum bitrate is 25Kbps.

Power via USB is sufficient.

Closed 2019-08-27.

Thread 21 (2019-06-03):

Working on examples for Arduino

RevoluPowered, 2019-06-03:
I'm working on Arduino code examples for this board, do you mind if I submit a PR with them?

It will include the button usage, relay control, can interface, 1-wire demo for (DS18B20 sensors).

also had some luck making the SD card slot work, as others have had difficulty with the SD_MMC not working for the ESP32/EVB so can also provide this too (to clatify, it has issues on Arduino, not on the ESP specific toolchain)

TsvetanUsunov, 2019-06-04:
no problem, let us review

RevoluPowered, 2019-06-04:
Cool will do, I will fork and merge later on when I'm back from work.

P.S. Really liking the EVB

RevoluPowered, 2019-06-07:
@TsvetanUsunov Still working on this but having some issues with the SD library from arduino-esp32.

Reading from SD MMC card slot with 1 wire bus interface takes 7 seconds to read 1 MB, even when using optimal settings but it does function.

Anything you know which can possibly help improve this?

I will probably do performance read/write tests with the ESP32 SDK

RevoluPowered, 2019-06-08:
https://github.com/espressif/arduino-esp32/issues/1611

Digging is available, appears to not be an issue with the evb, seems to be related to arduino-esp32 library as confirmed by my tests.

wimmmb, 2019-08-02:
Hi, i get the watering example not compiling, i placed the WebPage.c in data, uploaded it with the ESP32 sketch data upload tool and try to compile, get the error:
sketch\ESP32_Watering.ino.cpp.o:(.literal._Z13Print_WebpageR10WiFiClient+0x4): undefined reference to `WebPage'

Seems the external doesn work somehow:
extern const char WebPage [168][80];

Thanks, Wim

DanKoloff, 2020-07-17:
Closing due to inactivity. If you are still interested please comment I would re-open it.

Closed 2020-07-17.

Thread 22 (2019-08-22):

Program does not start correctly with GPIO4 on high.

Nestornp, 2019-08-22:
I need the UART1 for my project, with GPIO4 for U1TX and GPIO36 for U1RX. Uart on ESP32 works at 3.3v but the destiny UART target works at 2.7v, so i'm using a Logic Level Converter (the standar TXS0108E). The problem is that with this converter, the gpio4 is high when you connect the power and the olimex esp32 does not start the program. I do not understand why. It is necessary to press the reset button on the olimex 32 to start the program correctly (When you press the reset, the gpio4 is set to 0 V and the program starts correctly). This is a serious problem for me, on my application I need to turn the olimex on and off without having to press the reset button.
Any solution?

DanKoloff, 2019-08-22:
Look at the "Internal Bootstrapping Resistors" table GPIO4 is present and has a Pull-Down. Maybe this bugs the converter and the logic.

You can use one of the other pins at the UEXT connector instead of GPIO4 - Like all peripherals, the pins for the UARTs can be logically mapped to any of the available pins on the ESP32.

For example, try using GPIO16 (pin #6 from the UEXT); of course remember to change it in the code.

nagyrobi, 2021-12-28:
For reference, from: https://www.olimex.com/forum/index.php?topic=8093.0
_It seems like adding 1K pull down resistor between GPIO4 and GND fixes the issue._

Closed 2019-08-23.

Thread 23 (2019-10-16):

ethernet PHY init problem

micbuh, 2019-10-16:
Some month ago I purchased 2x ESP32-EVB boards Rev.D.
At that time, i didn't manage to get them reliable connected via ethernet.
Now, I tried once more the arduino examples (gpios adjusted), but I still have the issue, that
it will only connect sometimes. In most case I get following output:

`16:06:12.960 -> ETH Disconnected`
`16:06:24.983 -> ETH Connected`
`16:06:26.986 -> ETH Disconnected`
`16:06:34.975 -> ETH Connected`

The README.md contains following info:
> Changes related to the problems with ethernet PHY:
>The following components were added to enable powering on the PHY after the 50MHz oscillator >has been started: L5(NA(FB0805/600R/2A)), FET3(WPM2015-3/TR), FET4(BSS138), >C29(22uF/6.3V/20%/X5R/C0603), R50(1k/R0603) and R51(10k/R0603).

Is this related to what I am seeing? What have been the problems? Is there a work around for older revisions?

Thx.

DanKoloff, 2019-10-17:
After you upload the software, can you try to remove the power supply, wait 5 seconds and apply it again? Does the Ethernet start working after doing so?

drdelgado, 2019-12-31:
> After you upload the software, can you try to remove the power supply, wait 5 seconds and apply it again? Does the Ethernet start working after doing so?

This is typically what I see, with revision C gateway

DanKoloff, 2020-07-17:
Did you find the reason for this or the problem remains?

DanKoloff, 2020-10-13:
Closing due to inactivity.

Closed 2020-10-13.

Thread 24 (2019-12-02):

Use master branch of ESP-IDF (V4.x)

GISED-Link, 2019-12-02:
Hi,

We are currently running your demo code with an opcua server (see https://github.com/cmbahadir/opcua-esp32). To run your demo, we need ESP-IDF V3.3. That was the case 6 month ago. Is the project compatible with the new release of the ESP-IDF now?

At the moment, to update to the version 4.x of ESP-IDF, we need to rewrite the ETH part. If it is not done yet, we can do it. But it is possible to contribute on this git?

Thank you for the greate work until now 👍

DanKoloff, 2019-12-03:
We haven't updated our examples for ESP-IDF version 4.x since the official tags are still marked as either "dev" or "beta". There is still no stable release of ESP-IDF version 4.x. As soon as there is a stable tag we would start working on updating our examples. This was also announced here: https://github.com/OLIMEX/ESP32-POE/issues/7#issuecomment-523761856

The edit itself shouldn't be very difficult, a couple of paths are different. The last two posts of the issue thread that I linked above contain some instructions on getting the Ethernet working. These can be a bit different for ESP32-EVB (since it uses external clock generator, while all other Olimex ESP32 designs use the internal clock).

GISED-Link, 2019-12-04:
Thank you for the reply. I have some trouble between lwip and opcua layers (lwip and open62541) and I am not able to see what is happening. The guy who has ported open62541 to the esp32 use the latest V4.x of the ESP-IDF and has something that work quite properly. I really want to see if an update can fix the issue I have.

DanKoloff, 2020-07-17:
We published an Ethernet demo for version 4.0 here now: https://github.com/OLIMEX/ESP32-EVB/tree/master/SOFTWARE/ESP32-EVB_Ethernet_v4.0

Closed 2020-07-17.

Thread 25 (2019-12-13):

Kicad issues

johanliebs, 2019-12-13:
Downloaded the Kicad files to have a look and I am getting errors opening the project, PCB layout and schematic files for both revisions D & F.

Project error: file '/home/johan/...Rev-F/NB-IoT-DevKit_RevB.pro',line 7:'=' expected

Ubuntu 18.04
Kicad 5.1.15 (also 5.02 before upgrade)

Thanks!

DanKoloff, 2019-12-16:
Mmmm why does it say "Project error: file '...NB-IoT-DevKit_RevB.pro',line 7:'=' expected" - did you try to open NB-IoT-DevKit_RevB.pro project?

I assume you checked out something different there is no such file here: https://github.com/OLIMEX/ESP32-EVB/tree/master/HARDWARE/REV-F

johanliebs, 2019-12-16:
At first I downloaded the ZIP file and extracted it to : /home/johan/kicad/olimex iot dev kit/Rev-F/. When I open the *.pro file:

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

Second attempt is manually downloading each file from Rev-F (right click - save link as) to : /home/johan/kicad/olimex iot dev kit/Rev-F_manual_download/.  Same errors as the zip file.

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

Also when I try to open any other file like the schematic, I get more errors. The 1st error:
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

But if I go to https://github.com/RevoluPowered/ESP32-EVB and do a ZIP download of Rev-D, Kicad opens the project just file without any errors.

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

DanKoloff, 2019-12-17:
Can the issue be related to the path that you used to store the design files and which contains 3 x "space" character, namely "olimex iot dev kit". One thing I've learned is that Linux doesn't like space character, let alone three of them.

If you look at the path of the successfully opening revision D files - there is no space.

Re-downloaded and tested the design files on several machines here. No such issues here. And if I can't replicate it I can't fix it.

It doesn't seem like a problem with our design sources, not only because we have no such issue but also no one else reported something similar and these files had been out for some time. Aside from placing the project in path without "space" character I'd also suggest, that it might be some specific issue with the KiCAD release for your operating system. I'd recommend re-installing KiCAD and maybe trying latest nightly build for your system. If the problem persists report it to the KiCAD team.

johanliebs, 2019-12-18:
Removed all the spaces, made it simple, still the same error :
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

johanliebs, 2019-12-18:
I did another test with Kicad  4.0.6 on Mageia 6, which works fine without errors. Will try to re-install Kicad on Ubuntu 18.04

johanliebs, 2019-12-18:
Same as before after un-installing and re-installing the latest version of Kicad on Ubuntu 18.04....

But if I go to https://github.com/RevoluPowered/ESP32-EVB and do a ZIP download of Rev-D, Kicad opens the project just file without any errors. Why would Rev-D work fine?

TsvetanUsunov, 2019-12-18:
Hi
if you open the PCB file with text editor you will read this:
(kicad_pcb (version 20171130) (host pcbnew 6.0.0-rc1-unknown-0cca1c6~65~ubuntu16.04.1)
which means this file is made with KiCad PCB 6.0.0-rc1-unknown-0cca1c6~65~ubuntu16.04.1
you have to install same version of KiCad (hint read how to install the nightly builds) to may open and work with the file.
You try to open files made with 6.0 with KiCad 4 or 5 which is not possible.

Closed 2019-12-18.

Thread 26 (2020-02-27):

No issue

W-M-D, 2020-02-27:
I just wanted to thank you for being awesome and releasing these to make my life easier.

W-M-D, 2020-02-27:
I would like to recommend the teardrop via plugin as I see that you're manually changing trace width near THT holes.

DanKoloff, 2020-02-28:
Thanks, suggestions forwarded.

Closed 2020-02-28.

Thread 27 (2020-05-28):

Ethernet demo Compatibility with ESP-IDF(v4.0)

BHAKTIDESHPANDE, 2020-05-28:
I am working on olimex ESP32-EVB and using Ethernet interface for an application but after updating esp-idf to v4.0 the demo codes are not working.
When will you update your Ethernet component and demo example for esp-idf v4.0?

DanKoloff, 2020-07-17:
There is a demo for v4.0 here now: https://github.com/OLIMEX/ESP32-EVB/tree/master/SOFTWARE/ESP32-EVB_Ethernet_v4.0

Closed 2020-07-17.

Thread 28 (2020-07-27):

assets for rev I ?

wolfspyre, 2020-07-27:
Hi there!

It seems like this repo needs to be updated to include rev I of the board?

DanKoloff, 2020-07-27:
Hey,

Thanks for the notice, revision changes for H1 and I added. Files for revision I added.

https://github.com/OLIMEX/ESP32-EVB/tree/master/HARDWARE

Best regards,
Lub/OLIMEX

Closed 2020-07-27.

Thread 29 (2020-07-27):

Visual datasheet / hookup guides?

wolfspyre, 2020-07-27:
Hihi!

Thanks for updating the docs to incl rev. I of the board.
I reviewed the site/ this project, and any links I could find, but have yet to locate a diagram similar to the way sparkfun describes their boards:
take their esp32wroom for example:
https://www.sparkfun.com/products/15663
if you look at the documents tab on  that page:
they make a graphical datasheet for the board:
https://cdn.sparkfun.com/assets/learn_tutorials/8/5/2/ESP32ThingPlusV20.pdf

and then do a 'hookup guide'
https://learn.sparkfun.com/tutorials/esp32-thing-plus-hookup-guide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

that covers the nuance of that board.... it sorta serves as a collation point for information relating to that board.

is there such a place for y'alls products and I'm just.... ignorant?

DanKoloff, 2020-07-28:
Thanks for the feedback. This is definitely something we are looking into creating. We will see about ESP32-EVB, we have similar pinouts for the rest of the boards, for example:

https://www.olimex.com/Products/IoT/ESP32/ESP32-GATEWAY/resources/ESP32-GATEWAY-GPIOs-Rev.F-up.pdf
https://www.olimex.com/Products/IoT/ESP32/ESP32-POE/resources/ESP32-POE-GPIO.png
https://www.olimex.com/Products/IoT/ESP32/ESP32-POE-ISO/resources/ESP32-POE-ISO-GPIO.png

wolfspyre, 2020-07-31:
it appears riot-os has some of this info laid out for ya:

https://riot-os.org/api/group__boards__esp32__olimex-esp32-evb.html

Closed 2020-10-13.

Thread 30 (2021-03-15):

Ethernet restart

iBobik, 2021-03-15:
Hello,
I sometimes have issues with Ethernet stability (probably due power stagility or interferences). This could be easilly fixed by a restart of whole board (SW restart on ESP is not enough). Powering off or short circuit 3.3V with GND restarted it well enough. But I need to do it automatically.

So it seems like I need to restart Ethernet controller. Could I somehow restart it from ESP by it's GPIOs?

DanKoloff, 2021-03-16:
"short circuit 3.3V with GND" is not good idea... better remove the 3.3V instead of short-circuiting the board...

The reset signal that is connected to the reset button is ESP_EN, it can be found on pin #33 of the EXT1 header. To reset the board you need to keep ESP_EN in low position and then release it back up. It is risky to connect it to ESP32's GPIO tho, you might shoot yourself in the foot.

iBobik, 2021-03-16:
Thank you for reply.

Will be safe to ground ESP_EN by a transistor controlled by some GPIO?
Which transistor shoudl work?

Honza Pobořil

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

DanKoloff, 2021-03-17:
First test directly with a free GPIO, place 1uF capacitor on the wire. It is worth testing the simple setup first.

iBobik, 2021-04-14:
Hello,
I've tried to ground ESP_EN by 1-4 0,95uF capacitors, but restart not happened.

iBobik, 2021-04-14:
Here someone recommended to just wire GPIO and RST:
https://www.researchgate.net/post/How-to-reboot-reset-ESP32-without-pressing-the-reboot-button-on-the-board

What could happen?

DanKoloff, 2021-04-30:
Well I wrote the same: "First test directly with a free GPIO, place 1uF capacitor on the wire. It is worth testing the simple setup first."

iBobik, 2021-04-30:
Sorry, I am not sure I understand you, so I draw it :-)

Here is what I tried:
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

iBobik, 2021-04-30:
Also tried this:
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

DanKoloff, 2021-05-04:
Why GPIO5 exactly? Did you toggle GPIO5 in those tests by software means?

Try with one of the GPIOs that are available at the UEXT connector - for example GPIO16 or GPIO13.

iBobik, 2021-05-04:
U use GPIO5 because it is not used anywhere else. Yes, I toggled it by SW.
Is there something wrong with this?

I have not used UEXT pins because I use this connector for something else
(only GPIO 13, 14 and 15).

Honza Pobořil

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

DanKoloff, 2021-05-05:
Just as a test try with one of the pins from the UEXT instead of GPIO5, for example GPIO16 which seems that you don't use for the other connection.

Closed 2021-09-30.

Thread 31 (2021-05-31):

CAN bus cannot receive anything

githubxup, 2021-05-31:
I tried to receive messages from CAN bus by this board with CAN demo example, but nothing was happened.
I verified that the CAN sender is fine by using arduino UNO + CAN bus shield, and the messages are received as expected.
Do you have any suggestion?
Thank you

James

DanKoloff, 2021-06-01:
1) Make sure that the hardware connections are proper, CAN-HI is next to the power jack, CAN-LOW is in the middle.

2) Try another software, there is default CAN driver in ESP-IDF just change the pins to the ones we use.

3) In ESP32-EVB, the default the termination resistor is disconnected. Try enabling the termination resistor, it is actually required to have the termination resistors enabled in first and last node of a CAN network. If you have only two CAN devices you need to have termination circuits of both. To enable the termination resistor - close jumper CAN_T1 - solder carefully its pads together to establish connection.

githubxup, 2021-06-01:
Hi DanKoloff,

I got it work after sodering CAN_T1.
Thank you a lot.

James

Closed 2021-06-01.

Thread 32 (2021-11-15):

Schematics blank in Altium

katutxakurra, 2021-11-15:
I've noticed that the schematic files show an empty board when I open them in Altium. Any idea why this could be? It only happens after rev C. First 3 revisions show the board OK.

TsvetanUsunov, 2021-11-16:
They are designed with KiCad, try to open them with KiCad or contact Altium support, maybe they do not support some KiCad format feature which is used in the newer schematics

Closed 2021-11-16.

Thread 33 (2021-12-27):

Modbus transceiver generates CRC Check errors

nagyrobi, 2021-12-27:
Connecting to a MODBUS device using a transceiver like this one:
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
It's a pretty standard MAX485 RS485-TTL converter module.

This transceiver connected to a Nodemcu ESP-32S module works perfectly, software runs as expected (tested for several weeks now).
Moving the transceiver to ESP32-EVB, the exact same GPIOs and software generates Modbus CRC Check failed errors.

Tried various other GPIO combinations. Checked not to use bootstrapping pins. Tried adding pull-up and pull down resistors to TX, RX and Flow control pin - nothing changed. Replaced cables etc. nothing helps.
The transceiver, the bus and the device itself is OK because as soon as I connect it back in ESP-32S, things get back to normal.

The goal is to have Ethernet connection instead of WiFi and later use the 2 relays. This board is just perfect for the task, but I can't imagine what could interfere with the data transmission, as the old Nodemcu board doesn't have this issue.
I would prefer to use the UEXT1 connector if possible, it's just 4 GPIOs I need, 3 for this TTL board (RX, TX, Flow control) and 1 for Dallas temp sensors.

nagyrobi, 2021-12-28:
Seems like the problem is missing a [Modbus termination resistor](https://know.innon.com/bias-termination-rs485-network). The 120ohm resistor has to be put between the A+ and B+ wires of the bus.

But what I don't understand, is why when the transceiver is attached to Nodemcu ESP-32S this resistor is not needed (and works super reliable for long time), but when attached to Olimex ESP32-EVB I have to put it on, otherwise bad data appears immediately.

Closed 2021-12-28.

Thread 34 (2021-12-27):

ESP32-EVB vs ESP32-EVB-IND

nagyrobi, 2021-12-27:
I ordered an ESP32-EVB-IND but I think the mailman brought an ESP32-EVB. Is there any clear notation difference on the PCB that this actually is an IND version? It only has printed ESP32-EVB on it.
The first thing I noticed is that the relays are black and not orange as in the product photo on the website (RECOY LEG.5), this doesn't seem to comply with the -40+85C rated for the IND version board. That's what made me wonder, could it be that by mistake I did not receive an IND version?

I plan to use this board in harsh environment, I specifically need an IND version.

(Also having an ESP32-POE-ISO, which is clearly marked on the board as -ISO, that's why I would expect the -IND to be marked too.)

DanKoloff, 2021-12-28:
All ESP32-EVB board variants use same PCB hence white print is the same. However, the Ethernet chip is different modification. One is suitable for wider temperature range. The regular version uses LAN8720A while the industrial uses LAN8720Ai.

nagyrobi, 2021-12-29:
Like this?
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

DanKoloff, 2021-12-30:
Yes, my bad. It is 8710A and 8710Ai. This is also visible in the schematic. I've edited my previous post. The chip on your board is the industrial version.

Still I understand why it is not clear, this doesn't seem to be mentioned on the schematic. I will speak to the designers to generate Bill of Materials (BOM) for each board variant so I can upload it to GitHub.

The ESP32-POE and ESP32-POE-ISO have a lot of differences in the design to galvanically isolate the power supply from the POE and from the USB hence they have different PCBs. Still the IND versions just have few different components.

nagyrobi, 2021-12-30:
It's just the question of how can the customer easily identify, check that he received the correct product.

Closed 2021-12-30.

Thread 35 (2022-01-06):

Ethernet disconnects when relay is switching 240V

nagyrobi, 2022-01-06:
My ESP32-EVB exhibits a strange behavior. I have 2 consumers connected to the relays, one relay is switching a circuit feedig a small fishtank oxgen bubbles pump at 12V, the other relay is swithing a heating cable of 90W, at 240V. The board is powered by a quality 5V 2A MeanWell type power source.

Occasionally the board looses Ethernet connection after switching on the relay in the 240V circuit. The MCU is still running because I can see the other relay doing its job (switching on and off every few minutes). This only happens when the 240V circuit is powered on, regardless of the relay: I tried to swap the relays (use the first one for 240V and the second one for 12V) and the problem moved with the 240V circuit. No problem when switching 12V. Ethernet only disconnects when 240V switching occurs.

This happens in 70% of the cases and the biggest issue is that the board has to be powered off and back on to recover connection which is painful. Sometimes I have to cut the power twice to get the board's Ethernet back.

Seems like I'm not the only one having this issue: https://esp32.com/viewtopic.php?t=8055
Somehow I have a feeling that there's an interference issue affecting the `power_pin` of the LAN chip...? (On ESP32-POE it's connected to the MCU...)

Do you have any ideas what could be done? Any ferrite beads added to the cables could help?
A capacitor or a transil (supressor) diode maybe?

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

nagyrobi, 2022-01-07:
I temporarily added a separate relay from a cheap Chinese board connected to a different GPIO pin of ESP32-EVB, to switch the 240V circuit. Since then, no more Ethernet disconnects happen.

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

But this is a dirty solution, I especially bought ESP32-EVB-IND model to make use of both its relays in harsh conditions. The Chinese board is not something I'd expect to stay reliable on long term.

TsvetanUsunov, 2022-01-07:
Please try to move away the cable with high voltage current from ESP32-EVB. The high voltage / high current pulses induct spikes to the LAN trafo and PHY tracks which confuse the communication. When you add the external board in practice you move away the high voltage/high current stuff away of LAN.

nagyrobi, 2022-01-07:
OK I'll try to route that circuit as far as possible within the box, and let you know about the results.

nagyrobi, 2022-01-07:
Please look at the picture below:
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

The cable marked with red arrow is the one carrying the 240V. It goes as far as possible from the PCB. Also note that this is shielded power cable (it has a wire mesh shielding below the insulation, with 2x1mm2 wires inside.
Shield is connectedt to the earth ground together with the GND of the board (taken from the CAN connector).

This has brought some improvement, but still not 100% reliable.

I also noticed with an ohmmeter that the case of the RJ54 socket is not connected to GND. Why is that?

nagyrobi, 2022-01-07:
Unfortunately it is still very unreliable and I really can't figure out why...

nagyrobi, 2022-01-07:
Uptime graph when relay starts acting:
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
You see that in the latest tests the problem occurs when the relay turns OFF (breaks the circuit), not when it turns ON.
This should mean the problem is not caused by high current pulses inducting spikes in the transformers of the LAN interface, as when the circuit breaks, no high current pulses can occur.

nagyrobi, 2022-01-08:
Next experiment is to completely isolate the relay from ESP32-EVB, but keep the high voltage cabling in the box in the same position as the last photo above. I will use a Sonoff Mini which will connect galvanically only to the 240V circuit, ESP32-EVB will send its commands to it via MQTT (LAN port > switch > AP > WiFi). The Sonoff Mini will do nothing else bit switch the high voltage based on ON/OFF commands coming via MQTT.

nagyrobi, 2022-01-08:
Uptime graph when instead of local relay I employed a Sonoff Mini:
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

In the same box, same circuitry, same cables:
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

No problems neither at switching ON or OFF. Sonoff Mini also has a mechanical relay inside, so if any high current spikes are generated when a relay acts, these are present now too. But in this case, it doesn't effect the Ethernet...?

nagyrobi, 2022-01-08:
Maybe: https://electronics.stackexchange.com/a/321355 ?

TsvetanUsunov, 2022-01-10:
inductive loads generate high voltage pulses when the power is cut off. what is the load you switch on and off?

nagyrobi, 2022-01-10:
As I stated above in my first post, it's only 90W.
The Sonoff Mini has no such problems.

TsvetanUsunov, 2022-01-10:
the problem is not the heater, but the bubble pump they are big inductor with vibrating magnet
when the pump is switched off the inductor generates high voltage spike
try to switch on.off only the heater and see if these problems still exist.

nagyrobi, 2022-01-10:
It has no problem with the little pump. It's only 2W. That is still switched ON/OFF by ESP32-EVB and no problems occur.

Above I described that problem happens ONLY when the heater circuit switches OFF by relay on ESP32-EVB.

DanKoloff, 2022-01-10:
We will perform some tests, but need to know what is the hardware revision of your board exactly?

Also we did some empirical tests with a drill and vacuum cleaner with older revisions of ESP32-EVB a year and a half ago, there was no issue back then, maybe newer revisions or components introduced such issue. Will know better when we test. This is what we tested at the end of 2018:

https://www.youtube.com/watch?v=iTl9EQknGjA

https://www.youtube.com/watch?v=x3e_u8LgnTs

nagyrobi, 2022-01-10:
It's latest, revision I.

nagyrobi, 2022-01-10:
I tried adding a MOV (VDR-14D431K) to absorb the energy but still no help:
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

DanKoloff, 2022-01-11:
Try removing C31 and test if it hangs again. Just be aware that this will hinder further USB programming. You would need to place it back to program via USB.

nagyrobi, 2022-01-11:
Were you able to reproduce?
I'll try and let you know.

nagyrobi, 2022-01-11:
OK removed C31 and at first looked promising, I was able to turn the load ON/OFF for about 10 times and after that problem re-appeared. After that, after power-cycling the system it was enough to turn the relay ON/OFF only 1 or 2 times to reach in problem. Tried re-adding the MOV but absolutely no difference with or without it.

DanKoloff, 2022-01-12:
We did manage to bug the Ethernet by using the relays but can't say that it is a reproduction since the hardware setups are different. In fact, here removing C31 fixes the issue but it doesn't at your side, so there are differences, for sure. This also means that your feedback is important to solve this problem. We are looking into every possibility but so far can't find the reason for this behavior, including routing seems alright. We keep working and if there are further tests that you might carry I would let you know.

nagyrobi, 2022-01-12:
Ok, let me know what extra feedback you need
As a sidenote, the board is uset at outdoor temperature (attic), currently 1-2C. Maybe first test after removing C31 was partially OK because it was just brought back there from room temp...?
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
DanKoloff, 2022-01-24:
> Unfortunately I don't have the tools (and skills) to solder on SMD parts. I was able to remove C31 because it was at the edge of the board.

Alternatively, instead of placing it on C18 position, you can solder the extra 1nF capacitor at the bottom of the board on the PHY_RST1 jumper, this should make it easier. I attach a picture that shows how we've done it here:

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

Let me know if that is doable and how it goes.

nagyrobi, 2022-01-24:
I can try soldering a classical capacitor not an SMD one. How will these modifications affect my warranty (including removal of C31)?

DanKoloff, 2022-01-24:
Alright, PTH would also work, maybe consider NP0(C0G) one. If after the addition of this capacitor on the bottom, there are any problems with start up maybe try putting C31 back in its place.

If we instructed you to do hardware changes, as in this case, then the warranty is unaffected. It is not like you decided to do these yourself.

nagyrobi, 2022-02-20:
Since I temporarily fixed this with an SSR on another GPIO pin (and that works stable), I had to postpone investigation due to other projects. But please don't close this issue as I want to fix this.

nagyrobi, 2022-07-26:
Unfortunately I was not able to make it run stable with the 1nF capacitor soldered. It's a pity because otherwise it's a nice board. Sonoff Mini works...

Anyways, since I can't use the relays, I had to sacrifice GPIO pin for a SSR:
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

SSR type is MRA-23D2, can be driven directly by 3.3V (has opto built-in), and fits nicely on DIN rail:
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

No more Ethernet disconnects since.

nagyrobi, 2022-07-26:
I wonder, could I get a compensation/discount for my next purchase because of this?

nagyrobi, 2023-04-26:
😠 👎

peerweb-ant, 2023-11-22:
With SSR it's OK.
GPIO 5 and 12 (and 32 and 33) are OK as OUTPUT, 35 and 39 are only INPUT.
Yes, a bit sad that AC-current trough onboard-relays kills ethernet. Could have ordered board without relays.

nagyrobi, 2023-11-22:
Same experience.

DanKoloff, 2023-11-22:
About a board without relays - ESP32-GATEWAY is quite similar but without relays and few extra free pins. Alternatively, ESP32-POE-ISO.

About ESP32-EVB and relays - it is just these are electromechanical relays and there are some engineering considerations to be made when using them. The fact that your issues are fixed by using solid state relay is further confirmation of that. Start by placing the board away from the door controller so they don't influence each other. Inductive AC and DC loads are hard for electromechanical relays where welding contacts cause problems.  Normal way to solve this problem is to use clamp diodes or zener diodes in the poles of the load. However this lengthens the off delay and it does not totally eliminate the sparking in relay contacts. Switching the high DC voltages is also difficult for the electromechanical relays. I am sure there is a lot of solutions that might be suggested online. There are a number of workarounds or partial solutions but they depend on your exact design and setup. There is no solution that I can recommend 100% - you will have to try different things. And in some specific cases electromechanical relays are not suitable at all and can't be used for your goals.

We did a lot of tests of the relays when we designed the board, even some funny empirical ones can be found in these videos (I already shared these links further above):

https://www.youtube.com/watch?v=iTl9EQknGjA
https://www.youtube.com/watch?v=x3e_u8LgnTs

peerweb-ant, 2023-11-22:
Hi,
Tx for your reply.
It's not "spark-issue". I know that's also a risk.
I have done a test by moving the board away from powerlines, power supplies, ... . Same problem. As soon as AC-current is switched by the relays, ethernet hangs.
Board near or moved-away, if I disconnect doormagnet-wire, relay functions fine, ethernet keeps fine, although AC-voltage is nearby.
So, something around the relays isn't happy with switching AC-current.
I even did a test by using both relays, the 2nd one current in reverse direction (to get some sort of zero field). Didn't help.

Spark-issue (burn in) is another story. Relay displays 10A, it should be able to handle 1A, a doormagnet.

Whatever, it was cheap. So, it's fine. And now it works.
I appreciate your explainings.

Peter

nagyrobi, 2023-11-22:
Additionally, if I place anything else, like a Sonoff Mini or any other cheap chinese thing, that doesn't hang.

DanKoloff, 2023-11-24:
@peerweb-ant What is the hardware revision of your ESP32-EVB? It should be printed at the bottom of the PCB, under the name of the board?

peerweb-ant, 2023-11-24:
Rev K.
But all OK now.

DanKoloff, 2023-11-24:
Thanks, I understand that you found a workaround but we still investigate reports like that here.

Closed 2023-04-26.

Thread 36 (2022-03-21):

ESP32-WROOVER kit code don't work on ESP32-EVB

DylanVautrin, 2022-03-21:
Hi,
I've made a code on ESP32-WROOVER-KIT, it connect to an wifi hotspot if it had the ssid and password, and if not, it create an hotspot to fill the right informations to connect to an wifi hotspot.
This code works on ESP32-WROOVER but it don't work on the ESP-EVB, is there any modifications needed to use a code for ESP32-WROOVER on a ESP32-EVB ?
Thanks

DanKoloff, 2022-03-23:
These boards use different ESP32 modules as a main component.  ESP32-WROOVER-KIT uses ESP32-WROVER, while  ESP32-EVB uses ESP32-WROOM32.

The biggest difference between the WROOM and the WROVER chips is that the WROVER has "SPI PSRAM" chip on the module along with the ESP32-D0WDQ6. Probably the code uses that SPI PSRAM and this SPIPSRAM is not available on the ESP32-WROOM32 chip.

Closed 2022-03-30.

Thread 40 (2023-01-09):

pdf for REV K

kapyaar, 2023-01-09:
Can you please add schematic pdf for REV K? Or confirm nothing has changed in schematic from REV I?

DanKoloff, 2023-01-09:
There is PDF for revision K at the following link, it was added a couple of months ago: https://github.com/OLIMEX/ESP32-EVB/blob/master/HARDWARE/REV-K/ESP32-EVB_Rev_K.pdf

Closed 2023-01-09.

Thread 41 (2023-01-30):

ESP32-EVB_Ethernet_v4.4 compilation error

itsterit, 2023-01-30:
I'm using an ESP32-EVB board and want to run a standard ethernet example.

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

after setting

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

DanKoloff, 2023-01-31:
Did you try this instead: https://github.com/OLIMEX/ESP32-EVB/tree/master/SOFTWARE/ESP-IDF%20examples/ESP32-EVB_Ethernet_v4.4 ?

DanKoloff, 2023-01-31:
Also you are using ESP-IDF 5.0 for a project clearly labeled as suitable for ESP-IDF 4.4?

Closed 2023-04-10.

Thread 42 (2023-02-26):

Wifi to lan adapter.

Atlanta11, 2023-02-26:
Hello is this also possible with the module ESP32-EVB?

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

Thanks in advance
Gino

DanKoloff, 2023-04-26:
Yes. It is possible to use both WIFI and Ethernet, the hardware allows it. The question is whether the software allows it. I did some test for similar Olimex board, ESP32-GATEWAY, by combining two Arduino IDE examples - one for Ethernet, one for WIFI. Each interface had own IP address - WIFI has own IP address, Ethernet had own IP address. Both worked simultaneously.

There is an official support for Olimex ESP32-EVB in Arduino IDE for ESP32. My advice is to join either the espressif or the Arduino for ESP32 forums and check or ask for the others people's experience with using ESP32's Ethernet and WIFI simultaneously.

Closed 2023-04-26.

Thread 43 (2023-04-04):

12VDC 5A power input...

ApplicationNinja, 2023-04-04:
What would be involved for modifications to allow this board to be powered by a 12VDC 5A adapter, instead of the current 5VDC/2A?

DanKoloff, 2023-04-04:
You need to create external step-down voltage converter. Maybe use this or at least use its design as inspiration: https://www.olimex.com/Products/Power/DCDC-36-5-12/

Closed 2023-04-04.

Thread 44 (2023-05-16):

J1939 canbus Supported

samuelvvmm, 2023-05-16:
Hello,

Is the J1939 CanBus protocol supported??

I would like reading NMEA2000 bus. Is Possible??

samuelvvmm, 2023-05-16:
Hello,

Is the J1939 CanBus protocol supported??

I would like reading NMEA2000 bus. Is Possible??

DanKoloff, 2023-05-17:
What is the hardware revision of the board that you have ? The CAN transceiver used until recently was Microchip's MCP2562-E, which is what most likely your board has. Check its documentation (or search online) on whether " J1939 CanBus" and/or "NMEA2000 bus" work with MCP2562.

Closed 2023-12-21.

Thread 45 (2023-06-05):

Ethernet problem

Natsuchao, 2023-06-05:
Can't get ethernet working in arduino sketch on my ESP32-EVB-EA-IND. Seems related with a chip id problem (lan8710) :

E (101) lan87xx: lan87xx_init(499): wrong chip ID
E (101) esp_eth: esp_eth_driver_install(215): init phy failed

Any clue would be very appretiated.

Theo

DanKoloff, 2023-06-06:
Try adding "delay(300);" or  "delay(500);" in the beginning of the setup, like:

void setup()
{
  delay(300);
  Serial.begin(115200);
  WiFi.onEvent(WiFiEvent);
  ETH.begin();
}

Natsuchao, 2023-06-06:
It worked ! Thanks !

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

diplfranzhoepfinger, 2023-07-24:
> It worked ! Thanks !
> […](#)

pls close then !

Closed 2023-12-21.

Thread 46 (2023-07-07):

GPIO pins used by board hardware

quakec, 2023-07-07:
Is there any information on what pins on the ESP32 are used with the onboard components, I see relays are 32 and 33 based only on a code example.  But what about the rest of the components such as IR receiver, SD card and LAN8720 chip?

trevorXsingleton, 2023-07-09:
The information you are looking for in actually here on this github thread under hardware.  Not sure what board revision you have got as there have been many over the years.  I have put a pdf of the ESP32-EVB Rev I board below.

[ESP32-EVB_Rev_I_Schematic.pdf](https://github.com/OLIMEX/ESP32-EVB/files/11994875/ESP32-EVB_Rev_I_Schematic.pdf)

Closed 2023-07-10.

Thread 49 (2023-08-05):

Step CAD file of whole board ESP32-EWB

SurfingSpider, 2023-08-05:
Can you add this STEP file to this github repo, which is the whole board with all on it components? I had to download KiCad to create it but it might help someone in the future making a case design.

[ESP32-EVB_Rev_K.zip](https://github.com/OLIMEX/ESP32-EVB/files/12267420/ESP32-EVB_Rev_K.zip)

DanKoloff, 2023-08-21:
No, since we don't have the resources to verify it. As you pointed out it is simple enough to generate it via KiCAD (open the project, load the PCB, click File -> Export -> STEP...).

Closed 2023-08-21.

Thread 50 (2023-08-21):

Reset / Power on is entering DownloadBoot mode

quakec, 2023-08-21:
I have the ESP32-EVB Rev. K connected to a board I designed using the UEXT1 header, the schematic is below.

The issue I have is multiple resets are needed to get the board to boot SPI flash, sometimes it'll start up in SPI flash mode fine.

When I disconnect the GPIO2 pin between my board and the EVB board, the problem doesn't exist (starts up fine every single time).

In order to satisfy the condition which results in the ESP32 entering download boot mode both GPIO0 and GPIO2 are pulled down:
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

I am seeking a solution here, realising I may have to go back to the drawing board.
At this stage I have two questions:

1. If GPIO0 is pulled high internally, why is it randomly pulled down causing this?
2. Is there anything I can change on my circuit to prevent GPIO2 beign pulled down?

Q1 is a 2N2222A NPN transistor used to switch on leds built in to 3 x push buttons.  I had tried moving this over to GPIO15, however this prevents boot logs being sent over UART.
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

I am a novice at electronics so any advice would be greatly appreciated.

DanKoloff, 2023-12-12:
This reads like you've enabled watch dog and it expired and reboot... Are you sure you haven't enabled watchdog timer?

Closed 2023-12-21.

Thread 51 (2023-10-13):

Lipo Battery with CAN and Ethernet

rvxfahim, 2023-10-13:
Does Ethernet and CAN work with a lipo battery ?

DanKoloff, 2023-10-16:
Ethernet works on battery fine, no problems there. The things that don't work on battery are the CAN and the relays.

CAN - it won't work, the CAN driver operates from 4.5V, it is possible to modify the board but this requires placing another CAN driver and modifying a 3.3V/5V SMT jumper.

Also the relays won't work when powering the board from a battery.

rvxfahim, 2023-10-16:
I do not need the relays, so if i short the 3.3V/5V SMT jumper then will CAN start working ?

DanKoloff, 2023-10-18:
No. The on-board CAN driver chip SIT1050 doesn't work at 3.7V, hence I wrote "this requires placing another CAN driver and modifying a 3.3V/5V SMT jumper."

You would also need to desolder the SIT1050 chip and solder in its place 3.3V CAN chip. In the schematic at the bottom of the CAN part there are options listed. SN65HVD232D is 3.3V option but anything in similar package can do, make sure it works at 3.3V, most CAN drivers require 4.5V+ but there are lower voltage options too.

Closed 2023-10-20.

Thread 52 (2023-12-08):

Is CAN library interrupt based

rvxfahim, 2023-12-08:
Is the library given in the repo setup the CAN driver as interrupt driven, and then it sends frame to the freertos queue ?
or is it internally polling the buffer ?

DanKoloff, 2023-12-12:
No idea. We only patched the original ESP32-Arduino-CAN library (https://github.com/miwagner/ESP32-Arduino-CAN) then added two examples for ESP32-EVB. The code open and available to analyze.

Closed 2023-12-12.

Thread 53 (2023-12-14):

SD and MOD 2.8 TFT LCD

rvxfahim, 2023-12-14:
In arduino framework I am already using the MOD 2.8 TFT LCD with the ESP32 EVB board, but I can't seem to find a way to use the SD card with any library because almost all libraries I checked use CS pin and the spi pins for the card are also not standard pins. Any guidance ? Thanks.
EDIT: I figured out Espressif SD_MMC library works, but I can see that the on board sd shares MOSI MISO clock lines with the TFT.

DanKoloff, 2023-12-19:
I believe they can't be active simultaneously. But you can pause the SPI operation to access the 1-bit SD card then return to the display operation. Re-initialize each interface before usage. Notice that the SD card doesn't use SPI interface but 1-bit mode.

Closed 2023-12-21.

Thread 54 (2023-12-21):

Power supply through barrel connector 5V/2A results in instable webserver

fredlcore, 2023-12-21:
We now have several users who have reported that powering the EVB via the barrel connector with a 5V/2A power supply does power the board (i.e. LEDs are on), but network connectivity is shaky at best. We have experienced the same with power supplys over USB, but that seemed to have to do with low quality power supplies and the test for us is now that users should power the EVB via a laptop's USB to rule out a low quality power supply. So far, this has always led to a stable network connection.

Therefore, I wanted to check whether the power supply for the barrel connector on the EVB should really be just exactly 5V or whether there is a range as with other Olimex devices which you can power with 6-16V for example. Since the reports of users who have a problem with power supply via the barrel connector is significantly larger than the ones who complain about USB-powered boards, I wanted to make sure that this is not a design issue.
Thank you.

TsvetanUsunov, 2023-12-21:
ESP32-EVB requires regulated exactly 5V power supply, applying more than 5V will damage the board.
I recommend you to use SY0605E https://www.olimex.com/Products/Power/SY0605E/ or SY1005 https://www.olimex.com/Products/Power/SY1005E/ adapters to power the board.

Closed 2023-12-21.

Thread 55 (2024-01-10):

USB driver for MacOs Sonoma M2

stefan-tiva, 2024-01-10:
I'm not able to install the USB driver for MacOs Sonoma on a Macbook Pro M2.

Is there an update of this driver available?

DanKoloff, 2024-01-10:
It is a new Mac, probably it already has built-in CH340 driver... But if you have issues check the official CH340 manufacturers repo:

https://github.com/WCHSoftGroup/ch34xser_macos

CH340 is popular USB-serial converter, there is good chance you can find info about MacOS installation online.

stefan-tiva, 2024-01-10:
Thanks, I will check there

Closed 2024-02-10.

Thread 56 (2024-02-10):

Question about the SD card's CS connection

fredlcore, 2024-02-10:
I'm a bit puzzled about the connection of the chip select signal of the EVB's SD card reader:
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

My understanding of SPI is that CS is an active low signal that is to be set to logical low if the device is being accessed. Here, however, it is set to 3.3V constantly (through a 2.2k resistor). I read that if a device is the only SPI device, then CS can be tied to GND to have the device active all the time, but I don't understand how this is supposed to work here.

Is this therefore an error in the schematics or is it supposed to work that way and it's just my understanding of SPI that is wrong?

Thank you!

TsvetanUsunov, 2024-02-10:
this is not CS but CD pin and should be pulled up

fredlcore, 2024-02-10:
Thank you for your prompt and helpful answer, @TsvetanUsunov!

Closed 2024-02-10.

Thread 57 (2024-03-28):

External power supply via barrel connector not stable

fredlcore, 2024-03-28:
I'm maintaining a hardware project (https://www.bsb-lan.de) where probably half of the installations run on an Olimex (either EVB or POE). About a dozen users using the official Olimex power supply have now reported back to me that when they use WiFi on the Olimex, the system becomes unstable which shows in disconnects or slow WiFi connections.
The matter immediately changes when powering the Olimex via a stable USB power supply (a laptop's USB for example) and the issues are gone.

I'm not sure whether this is a (external) power supply or (internal) voltage shifting issue. At least It seems that it's not the ampere rating of the power supply because similar problems have also occurred with cheap USB power supplies which rate 2-3A. With these, it seems to be rather the case that the voltage level is not stable enough.

We will now add a recommendation to only power the Olimex via a reliable USB power supply, but since an external power supply is often a good choice, I wanted to let you know about this problem, so that hopefully you can fix it in the next hardware revision.

DanKoloff, 2024-04-02:
Can you clarify which is "official Olimex power supply"? We have at least 5 different 5V DC adapters, with currency rating ranging from 1A to 4A. Maybe the power jacks got worn out and no longer make good contact, it happens here.

Alternatively, maybe those boards had their power jack circuit damaged somehow and now only the USB circuit works fine.

fredlcore, 2024-04-02:
Sorry for not being more specific, since I first reported this issue several months ago on a more general basis (https://github.com/OLIMEX/ESP32-EVB/issues/54), our project recommends the SY1005E. But I would have to check if these users actually have this or another power supply. As for a damaged jack, I think this is rather not likely, because people usually buy these boards anew just for this project. If the jack was broken, it should not power at all, but the fact that it runs unstable seems to indicate to me that the voltage is not provided in a stable way. We have also experienced this with cheap USB power supplies, that's why we tell users to check if the problem still persists when they power the board via USB from their laptop. So far, this has always resulted in a stable performance.

DanKoloff, 2024-04-03:
We've manufactured a lot of ESP32 boards and variants and we've sold a lot of these boards to a lot of customers, truth to be told this is the first time we hear that the board's WIFI gets disconnected because of shaky power supply. I think it might be something related to your specific hardware or software implementation. But we lack details to pinpoint where exactly.

Do all users have the BSB header board attached to them? Can you give us some info about that board? What is expected current draw, which GPIOs it uses, can it affect bootstrap pins, etc?

How do you apply SY1005E to the ESP32-POE (it has no power jack)? Can you also specify exactly how many complaints are for ESP32-POE and how many for ESP32-EVB (or maybe other ESP32 boards like ESP32-GATEWAY or ESP32-POE-ISO) since the designs are quite different.

TsvetanUsunov, 2024-04-03:
Is it possible to send us "non working" setup to us for analysis? So we can reproduce this situation at our lab with all attached additional components?

fredlcore, 2024-04-03:
I'll check with the users that are having this problem and will get back to you.

horendus, 2024-05-06:
Hi, just thought I would chime in on this one, I have developed a product that runs on the esp32-evb board and have also found instability from a few customers when using the barrel jack, im using ethernet as the primary connection method.

My logging shows this as random unexplained reboots that go away when using quality USB connection.

TsvetanUsunov, 2024-05-07:
looks to me like problematic power supply cable

fredlcore, 2024-05-07:
I'm sorry, but the users that had reported the instability have not responded to my e-mails whether they could provide you with the Olimex devices and power supplies that they are using. If you are convinced that it cannot be a hardware issue, then that's fine with me, even though I don't know how on what you are basing your assumption that it's a problematic power supply cable.

@horendus: Could you try it out with a different barrel jack power supply? If the instability can be reproduced by using different power supplies, I think it would make a strong(er) case that the issue is not (entirely) related to problematic power supplies.

TsvetanUsunov, 2024-05-07:
I would measure +5V rail on the board on the anode of PWRLED1 or the RELAY coil when powered with USB and barrel power jack and see if there is difference.

fredlcore, 2024-05-07:
@horendus: Is this something you could check?

osro, 2024-06-10:
I can confirm this issue. I recently purchased an Olimex ESP32 EVB with an included power supply. When using the Olimex power supply, the board connects to the network but remains unresponsive. However, when I switch to a USB power supply, everything functions properly.

DanKoloff, 2024-06-10:
> I can confirm this issue. I recently purchased an Olimex ESP32 EVB with an included power supply. When using the Olimex power supply, the board connects to the network but remains unresponsive. However, when I switch to a USB power supply, everything functions properly.

I can test empirically here with few ESP32-EVB boards from the shop and Olimex power supplies. If we can replicate the problem here, we can work to resolve it. I have few questions to be certain we are using the same hardware:

1. Which Olimex power supply exactly?
2. Is it the base ESP32-EVB board (not one of the variants)?
3. What is the hardware revision printed on the board?
4. If possible also share the code that you use. If it propriety maybe simple it up (but confirm issue remains with new code).

osro, 2024-06-10:
1. This is the one that Olimex.com was suggesting for me:
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
2. Yes, ESP32-EVB
3. K1
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
fredlcore, 2024-06-13:
Ok, that would be great, but our `serial` is pointing to `Serial1` which we map to pins 36 and 17 respectively – how is it possible that the invalid data coming from the not completely unpowered CH340T comes in at `Serial1`? Shouldn't it be coming in on `Serial` which is on pins 1 and 3? Maybe I haven't really understood the problem on a hardware level, but I would have expected such issues on the Serial Monitor (which is connected to `Serial`'s pins 1 and 3 via the CH340T), not on our board's serial communication.

Last but not least: If that `while` loop is exited via a timeout, the not completely unpowered CH340T would continue to send data when that function is called in the next `loop()` iteration. So if there is always invalid data coming in on the same serial input stream that we are polling for new, valid data, our code won't be able to do its job even if it's not crashing, right?

fredlcore, 2024-06-13:
One more thing: Could you change line 26 (`  serial = &Serial1;`) in `bsb.cpp` from Serial1 to just Serial and try it again without your bugfix? If other code using `Serial` does not have this problem, the problem should go away when we move from Serial1, attached to pins 36 and 17, to Serial (attached to pins 1 and 3).
Alternatively, you could also change the RX pin in line 48 in bsb.cpp:
`  Serial1.begin(4800, SERIAL_8O1, rx_pin, tx_pin);`
If you set rx_pin to 1 (which should be the RX pin for `Serial`) and the problem goes away, it would be another proof that pin 36 is the issue.

@osro, could you also try this? The connection to the heater won't work then, of course, but just to check whether the ESP32 no longer hangs?

DanKoloff, 2024-06-13:
@fredlcore Yeah that also works changing &Serial1 to &Serial

fredlcore, 2024-06-13:
Ok, just to confirm, could you keep Serial1 and replace `rx_pin` in line 48 with `1`? If that also fixes the problem (provided you have removed your bugfixes), we know that pin 36 is the problem.
Would you have any idea why pin 36 is affected by the not completely unpowered CH340T?

DanKoloff, 2024-06-13:
Again it works. But now I can't get serial output on pin #2 of the EXT1 header. I had only that pin and GND attached to external USB-serial adapter.

No idea about GPI36 (it can't be output by definition btw).

fredlcore, 2024-06-13:
One other way to test this would be using one of the webserver/serial sketches that you tried above and worked (presumably because they use `Serial`) and change these to `Serial1` using pin 36 for RX and see if a similar problem occurs.

DanKoloff, 2024-06-13:
Other code doesn't hang if I change Serial with Serial1.

fredlcore, 2024-06-13:
Strange. Can you set the RX pin to 36 explicitly to make sure it isn't using any other pin?
So just to confirm again: Our code works fine if you either assign `serial` to `Serial` instead of `Serial1`, or if you keep `Serial1` but set the RX pin to something other than pin 36?

@osro: Could you use the `bsb.cpp` that @DanKoloff linked above and see if that also fixes the problem for you? Most importantly, could you also look whether you can access the heater? If there is continuously invalid data being generated when the EVB is powered via the barrel connector, then I wonder if the messages from the heater actually get through this "noise"...

DanKoloff, 2024-06-13:
Unfortunately, I'm overwhelmed with other tasks and I can't debug this project anymore. That's all I could do. It is really tedious with these 20 minute uploads after changing one variable and my other work is falling behind. My advice is to first recommend powering ESP32-EVB from USB.

fredlcore, 2024-06-13:
Ok, understood. We'll do as you suggest and thanks a lot for all the work you put into it. I hope I can figure out more with @osro, and if we come to more conclusive findings, we'll let you know.

fredlcore, 2024-10-18:
@DanKoloff, sorry for bringing this up again (and also not posting it in the [related POE issue](https://github.com/OLIMEX/ESP32-POE/issues/49), but I've had another user who had the same problem as above, but while powering the ESP32-POE-ISO via POE. The same intermittent reboots, and things worked perfectly fine when he used a POE splitter to use the POE power to power the USB port. Would your [explanation above](https://github.com/OLIMEX/ESP32-EVB/issues/57#issuecomment-2162757027) also explain this behavior?

DanKoloff, 2024-10-18:
Probably. It was all explained here: https://github.com/OLIMEX/ESP32-EVB/issues/57#issuecomment-2165214478

fredlcore, 2025-03-12:
We came to a
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

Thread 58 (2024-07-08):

Lag in mqtt/ethernet communication

programmeddeath1, 2024-07-08:
I am using the olimex esp32-evb-ind to execute the position,velocity and acceleration of a robotic arm. The path is generated on a cpu and the coordinates are then sent to the esp32 over ethernet cable.

When sending data over a control cycle of 0.04 (1 point generated every 0.04s or 40ms). The communication time from the cpu to esp32 is avg around 4ms (RTT) ie 2ms for communication
<google-sheets-html-origin><style type="text/css"><!--td {border: 1px solid #cccccc;}br {mso-data-placement:same-cell;}--></style>
ID | sentTime | ReceiveTime | ExecutedTime | Communication time | Execution time
-- | -- | -- | -- | -- | --
1 | 1720436672 | 1720436672 | 1720436672 | 4.03 | 4.96
2 | 1720436673 | 1720436673 | 1720436673 | 3.72 | 4.54
3 | 1720436673 | 1720436673 | 1720436673 | 4.01 | 4.96
4 | 1720436673 | 1720436673 | 1720436673 | 3.5 | 4.37
5 | 1720436673 | 1720436673 | 1720436673 | 4.19 | 5.49
6 | 1720436673 | 1720436673 | 1720436673 | 3.24 | 4.32
7 | 1720436673 | 1720436673 | 1720436673 | 3.62 | 4.5
8 | 1720436673 | 1720436673 | 1720436673 | 3.87 | 4.64
9 | 1720436674 | 1720436674 | 1720436674 | 4.27 | 5.19
10 | 1720436674 | 1720436674 | 1720436674 | 4.27 | 5.17

But if i reducee the control cycle to below 0.03, eg at 0.01, there seems to be significant lag and pile-up of messages causing constant lag
<google-sheets-html-origin><style type="text/css"><!--td {border: 1px solid #cccccc;}br {mso-data-placement:same-cell;}--></style>
Test 1 | sentTime | ReceiveTime | ExecutedTime | Communication time | Execution time
-- | -- | -- | -- | -- | --
1 | 1719317147 | 1719317147 | 1719317147 | 6.15 | 14.68
2 | 1719317147 | 1719317147 | 1719317147 | 14.63 | 25.86
3 | 1719317147 | 1719317147 | 1719317147 | 25.57 | 26.35
4 | 1719317147 | 1719317147 | 1719317147 | 25.49 | 26.54
5 | 1719317147 | 1719317147 | 1719317147 | 26.25 | 27.66
6 | 1719317147 | 1719317147 | 1719317147 | 25.65 | 26.82
7 | 1719317147 | 1719317147 | 1719317147 | 25.97 | 27.35
8 | 1719317147 | 1719317147 | 1719317147 | 25.17 | 26.31
9 | 1719317147 | 1719317147 | 1719317147 | 24.14 | 25.3
10 | 1719317147 | 1719317147 | 1719317147 | 24.15 | 25.05

I tried controlling the background processes by creating the mqtt callback task to pin to a core using xTaskCreatePinnedToCore. Such that it was run on core 0 as well as core 1, but the lag seems to remain.

Also the lag seems to be more on control cycle of 0.02 and 0.03 - <google-sheets-html-origin><style type="text/css"><!--td {border: 1px solid #cccccc;}br {mso-data-placement:same-cell;}--></style>
1 | 1720436867 | 1720436867 | 1720436867 | 3.12 | 28.74
-- | -- | -- | -- | -- | --
2 | 1720436867 | 1720436867 | 1720436867 | 28.88 | 55.37
3 | 1720436867 | 1720436867 | 1720436867 | 55.61 | 56.43
4 | 1720436867 | 1720436867 | 1720436867 | 55.33 | 56.06
5 | 1720436867 | 1720436867 | 1720436867 | 52.8 | 53.77
6 | 1720436867 | 1720436867 | 1720436867 | 47.12 | 48
7 | 1720436867 | 1720436867 | 1720436867 | 47.66 | 48.47
8 | 1720436867 | 1720436867 | 1720436867 | 47.18 | 47.99
9 | 1720436867 | 1720436867 | 1720436867 | 47.01 | 47.81
10 | 1720436867 | 1720436867 | 1720436867 | 47.2 | 48.27

I tried changing the message data size, sending in json format or as encoded byte format, but there seems to be almost no difference in the processing time.

Is this a limitation with the cpu processing capabilities of the esp32 that its not able to process points at such high frequencies.

The esp32 DOIT kit which runs WROOM-32 is able to achieve faster times with uart at a baud rate of 4000000. It seems counterintuitive that uart is faster here than ethernet or mqtt over LAN.

I have connected the esp32 over a link-local only lan setup and no router, the ping times are around 0.3ms.

DanKoloff, 2024-07-08:
This can likely be improved by software means but I doubt this is the proper place you'd receive the needed attention. Better check the communities with the MQQT or ESP32 libraries that you use.

There should be something like TCP_NODELAY in the mqqt options or maybe you can try UDP instead.

"The esp32 DOIT kit which runs WROOM-32", well ESP32-EVB also runs the same module (either ESP32-WROOM-32E or ESP32-WROOM-32UE depending if it has antenna).

>  It seems counterintuitive that uart is faster here than ethernet or mqtt over LAN.

Why? Which interface is easier to process and has less overhead? Ethernet requires huge software stack and UART is much simpler...

programmeddeath1, 2024-07-09:
I understand it has less overhead, but mqtt and ethernet are said to be faster based on all reference content available online.  And it is true too, since at control cycles of 0.04, mqtt takes around 4ms avg for round trip which is way less than usb serial's best time(which is around 8 to 10ms avg). This lag is when messages are getting piled up at a rate of 10ms(cc- 0.01) and there is a constant or increasing delay in their subsequent messages.

I will try with nodelay and UDP once and check. I'll have to check with the expressif communities, the mqtt and library communities are quite inactive.

Thanks for your response!

Closed 2024-07-09.

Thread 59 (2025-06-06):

GPIO0 is being triggered at startup?

Arcitec, 2025-06-06:
Hi! :) I'm looking at the latest schematic:

https://github.com/OLIMEX/ESP32-EVB/blob/master/HARDWARE/REV-K1/ESP32-EVB_Rev_K1.pdf

- It uses a 50 MHz crystal.
- The crystal is wired with +3.3v rail going to its VCC and ENABLE pins, meaning that the crystal is *always* running immediately at board power-on.
- The crystal output goes to the LAN8710A and to the ESP32's GPIO0 pin.

Now that's a red flag for me:

- GPIO0 is the pin that tells the ESP32 to go into bootloader/programming/flashing mode.
- So the crystal would be putting a signal on GPIO0 at startup, thus forcing the ESP32 into flashing mode.

Am I missing something?

Actually, just as I was writing this down, I guess that I'm also seeing some kind of oscillator disable/enable circuitry that is wired to the ESP32 Enable pin, but I really don't see how this board works?

DanKoloff, 2025-06-06:
Yes, due to lack of free GPIOs in ESP32-EVB's design, we couldn't sacrifice another pin for ETH enable so we used own circuit to delay GPIO0 by 500ms. Just look around the schematic and the text.

All other ESP32 boards that we have with Ethernet use the standard dedicated enable pin. Like if you compare ESP32-EVB's and ESP32-GATEWAY's schematics around the Ethernet you'd notice the differences.

Arcitec, 2025-06-06:
@DanKoloff Ah I see. So in this design your Ethernet chip is always enabled, and the crystal is controlled by the ESP32 enable (EN) signal with a 500ms time delay to prevent the crystal startup until after the ESP32 has booted already.

That 500ms delay seems very high since the crystal should be started before any ESP32 software tries to talk to the Ethernet chip. But I guess the ESP32 takes longer to boot than I thought.

---

I looked at the ESP-GATEWAY but it doesn't use an external crystal. It uses GPIO17 50MHz clock output from revision D and onwards (A-C used the time delay and external oscillator):

https://github.com/OLIMEX/ESP32-GATEWAY/blob/master/HARDWARE/Hardware%20revision%20I/ESP32-GATEWAY_Rev_I.pdf

---

Unfortunately there is a very severe hardware bug in every ESP32: The 50MHz clock goes unstable and crashes/hangs the ESP32 if you enable WiFi and Ethernet at the same time:

https://docs.espressif.com/projects/esp-chip-errata/en/latest/esp32/03-errata-description/esp32/clock-rmii-clock-when-using-ethernet-and-wifi.html

So I am going to solve it with a LAN8720A and an external crystal. That chip can be clocked with a 25MHz crystal and then generates 50MHz internally. The 50MHx is then output via it's REFCLKO output and needs to be routed into GPIO 0 on the ESP32 so that the ESP32 can talk to the Ethernet chip.

Which means that I need to implement a soft start for the crystal so that it doesn't output a signal during the ESP32 startup process.

Right now it seems like the best idea is to use the ESP32 enable pin signal and time-delay it, like you did.

But it might also be possible to use some other method to enable the crystal. Any ideas? Perhaps it can be tied to one of the Ethernet enable pins.

Arcitec, 2025-06-06:
Oh I think I have found the best solution.

- Wire any GPIO to the crystal enable pin. WT32-ETH01 uses GPIO 16.
- Then specify that GPIO as the "eth_power" pin in WLED. I am not sure if that is an ESP32 SDK feature or a WLED addition. But it's used here (see the WT32-ETH01 power definition here): https://github.com/wled/WLED/blob/main/wled00/network.cpp#L31
- Then you don't need any time delay circuits.

I haven't finished reading through the WT32-ETH01 schematic in detail to see if GPIO16 is connected to anything more or just to the crystal.

And I also need to look up whether GPIO 0 can be directly joined with both the CH340 and REFCLKO traces or if I need some mux/diodes to prevent signals going the wrong way in that trace. :)

Other than those two uncertainties, this seems like an awesome solution.

DanKoloff, 2025-06-06:
I haven't read everything you wrote but there is one important thing that has to be considered and I missed it in my first reply. You need to have the clock available on the LAN8720 chip before it gets powered, else it will hang. "During a Hardware reset, an external clock must be supplied to the XTAL1/CLKIN signal", page 33 of the manual:

https://ww1.microchip.com/downloads/en/devicedoc/00002165b.pdf

DanKoloff, 2025-06-06:
But yes, if you have free GPIO you can just install transistor and hold the Ethernet in reset. Check transistor T1 in ESP32-GATEWAY, its purpose is to hold the LAN in reset during initialization for some milliseconds, also can be used a mean to reset only the Ethernet if it hangs (and not reset the whole board).

Arcitec, 2025-06-06:
Thanks! I will see how the WT32-ETH01 achieved that, since they use GPIO16 to turn on the crystal and their code is at:

https://github.com/arendst/Tasmota/blob/f3d4b5275d55095f6652f3849f67732b7cc71adf/tasmota/tasmota_xdrv_driver/xdrv_82_esp32_ethernet.ino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

And in WLED their GPIO16 is listed as the Ethernet power pin, so I will ensure that WLED does the right thing and activates the crystal before trying to talk to the chip:

https://github.com/wled/WLED/blob/main/wled00/network.cpp#L31

I think it sounds like it's safe to power the LAN8720A without a crystal though (making it hang), and then just enable the crystal and send the Reset signal to restart the 8720A.

Arcitec, 2025-06-06:
Thanks for the tip about transistor T1 and holding the LAN8720A in reset.

The final thing that I am really unsure about is the GPIO0 mixing of CH340 signal + crystal clock signal. Is it safe to join those two traces to the same pin?

Or do you need some diode or something to protect the CH340/Crystal frommreverse voltage?

DanKoloff, 2025-06-06:
We use Schottky diodes between CH340 outputs and ESP32 GPIOs, the CH340T is powered from 5V DC while GPIOs of the ESP32 are 3.3V. Like D7, D8, D9, U9, U10.

Arcitec, 2025-06-06:
By the way, just in case it got lost in the discussion, I'll alert you again that the ESP32 has an unfixable hardware bug which is exactly why I won't use its own internal clock anymore. So you might want to consider switching to external crystals again. :/

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

DanKoloff, 2025-06-06:
Thanks for the headsup. Not much we can do about that at the moment but will see in future. But still WIFI and Ethernet can be used with time-sharing, so it depends on the application I've used both in the past (I guess not simultaneously but...):

https://github.com/OLIMEX/ESP32-POE/blob/master/SOFTWARE/ARDUINO/ESP32_PoE_Ethernet_WIFI_test/ESP32_PoE_Ethernet_WIFI_test.ino

I know customers have used both in the past too:

https://github.com/zorce/ESP32-POE_MQTT_example/blob/master/ESP32-POE_MQTT.ino

Anyway, glad to help, feel free to use our work as basis.

Arcitec, 2025-06-06:
@DanKoloff Thanks a lot again for the advice and explanation of your design, since it's really been helpful in figuring out solutions for using external crystals. :)

I don't think the timesharing solution there is correct. The only way to prevent the hardware bug is to call `WiFi.disconnect()` to turn off the radio.

Any WiFi data (even access point beacons) will disrupt the ESP32's PLL clock signal generation.

That disruption in turn leads to major packet loss and even the ESP32 hanging (if it tries to talk to the ethernet chip).

By the way, thinking about my plan above again, it seems I will need 3x GPIOs:

- GPIO 0 to receive the clock.
- GPIO X (let's say 5) to send the nRST signal.
- GPIO Y (let's say 17) to send the permanent crystal enable/power signal.

I can't think of any ways to combine the "crystal enable" with any other Ethernet pin purposes.

So either I'll have to do what you did with the delayed crystal startup which ensures the crystal is always available at startup and won't waste a GPIO (but needs some complexity with extra parts for the time-delay chip), otherwise I'll have to implement a separate GPIO pin that holds the crystal enable pin high, and add code for that in WLED (something like a `eth_crystal_enable` GPIO variable). 🤦‍♂

Arcitec, 2025-06-08:
@DanKoloff Hi again. I found an official reference now:

https://docs.espressif.com/projects/esp-techpedia/en/latest/esp-friends/advanced-development/performance/reduce-boot-time.html

> The startup time of ESP chips refers to the time it takes for the ESP chip to power on and execute the app_main function. The unoptimized startup process usually takes a long time (generally around 300 milliseconds).

So by delaying the crystal startup by 500 milliseconds, you're delaying it way past the code execution stage of the ESP32 firmware (at 300 milliseconds).

I mentioned that I thought 10-100 milliseconds was a more appropriate value for the crystal delay.

Was there any reason why 500 milliseconds of crystal startup delay was chosen? :)

DanKoloff, 2025-06-09:
It was empirically tested. But it is easy to change as you'd like simply pick lower value for C32 (currently 1uF).

Important notice - the delay is performed by R52, C32, U11. Notice that U8 is NA - not assembled.

Arcitec, 2025-06-09:
@DanKoloff Yeah, I have no doubt that 500ms has been tested across many board revisions and is working. :)

I was just wondering/worried about it since it seems way too high, considering the ESP32 boot sequence:

- 0ms: Power on the ESP32.
- 300ms: ESP32 has finished booting and is now executing the user firmware code. Where the firmware can do things like `ETH.begin()` very early.
- 500ms: Crystal turns on.

That's why I was asking if there was any reason why such a high value was chosen. Perhaps you discovered that "100ms doesn't work" etc?

I think the reason why 500ms works despite being very high is most likely that the ESP32 and LAN87X0A chips both simply hang/freeze when they try to communicate, and simply hang (waiting for the clock) until the clock pulse begins, so having a too-long delay probably doesn't harm anything.

It sounds reasonable to use something like 100-300ms crystal startup delay though, to be sure it's enabled before the ESP32 begins executing user code. Even 50ms sounds like it should work, since the boot mode selection happens within the first few milliseconds of the ESP32 power-on, and that's really the only clock signal interference that needs to be avoided at bootup.

So that's why I am very curious: Was there any test with a lower delay? If so, were there any issues?

DanKoloff, 2025-06-10:
Yes, empirically tested means "trial and error".

Arcitec, 2025-06-10:
@DanKoloff Thank you, I highly appreciate all the testing you have done to make sure that 500ms is rock solid!

The reason I was asking if you tried lower values is because the ESP32 manual says the following:

- After the voltage is high enough to turn on the chip, it takes around 3-4ms for it to start reading the GPIO 0 value.
- It then takes it 1ms to read the GPIO 0 value to choose the boot mode.
- After the bootstrap setting has been read, the GPIO 0 pin becomes a "regular I/O pin". Meaning it's safe to start blasting it with the clock signal.
- So, **4 or 5 milliseconds after boot, it's safe to start the crystal.** That's how fast the GPIO 0 becomes a regular I/O pin at boot.
- I definitely listened to your testing though, and have decided to use a 200 millisecond delay personally. It means it's definitely fully started before the ESP32 begins executing user code (at 300 milliseconds), and it's still long enough that it'll never be a problem.

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

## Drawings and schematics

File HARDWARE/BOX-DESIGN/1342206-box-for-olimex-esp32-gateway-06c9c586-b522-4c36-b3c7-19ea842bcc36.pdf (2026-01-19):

## Box for Olimex ESP32-GATEWAY

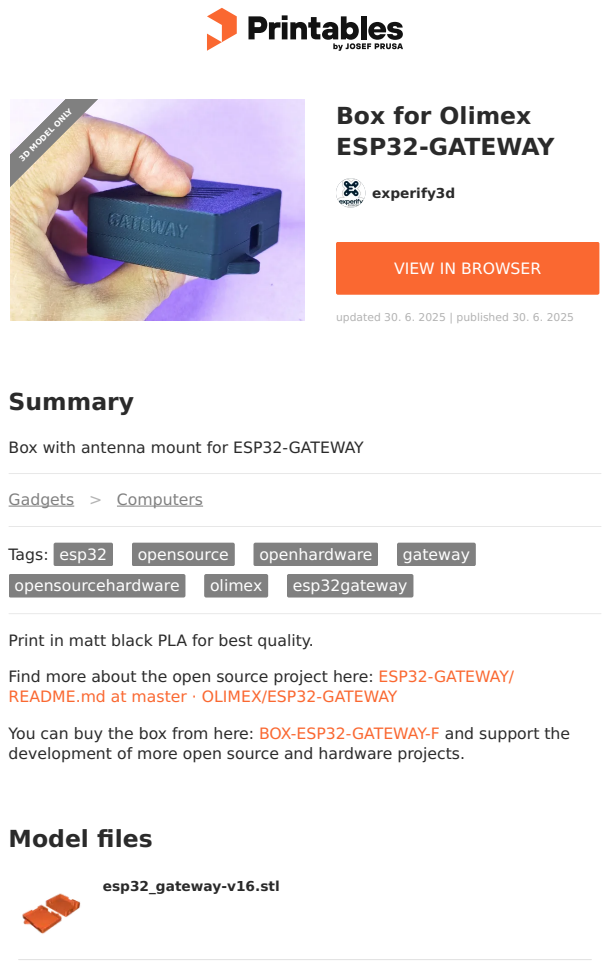
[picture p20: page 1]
Model files; Summary; Gadgets > Computers; Tags: esp32; opensource; openhardware; gateway; opensourcehardware; olimex; esp32gateway; experify3d; updated 30. 6. 2025 | published 30. 6. 2025; esp32_gateway-v16.stl; 3D MODEL ONLY

VIEW IN BROWSER (https://printables.com/model/1342206-box-for-olimex-esp32-gateway)

Box with antenna mount for ESP32-GATEWAY

Print in matt black PLA for best quality.

Find more about the open source project here: ESP32-GATEWAY/
README.md at master · OLIMEX/ESP32-GATEWAY (https://github.com/OLIMEX/ESP32-GATEWAY/blob/master/README.md)

You can buy the box from here: BOX-ESP32-GATEWAY-F (https://www.olimex.com/Products/IoT/ESP32/BOX-ESP32-GATEWAY-F/) and support the
development of more open source and hardware projects.

## License

This work is licensed under a
Creative Commons (4.0 International License)

Attribution (http://creativecommons.org/licenses/by/4.0/)

✖ | Sharing without ATTRIBUTION
✔ | Remix Culture allowed
✔ | Commercial Use
✔ | Free Cultural Works
✔ | Meets Open Definition

esp32_gateway-v16-bambu-lab-project.3mf

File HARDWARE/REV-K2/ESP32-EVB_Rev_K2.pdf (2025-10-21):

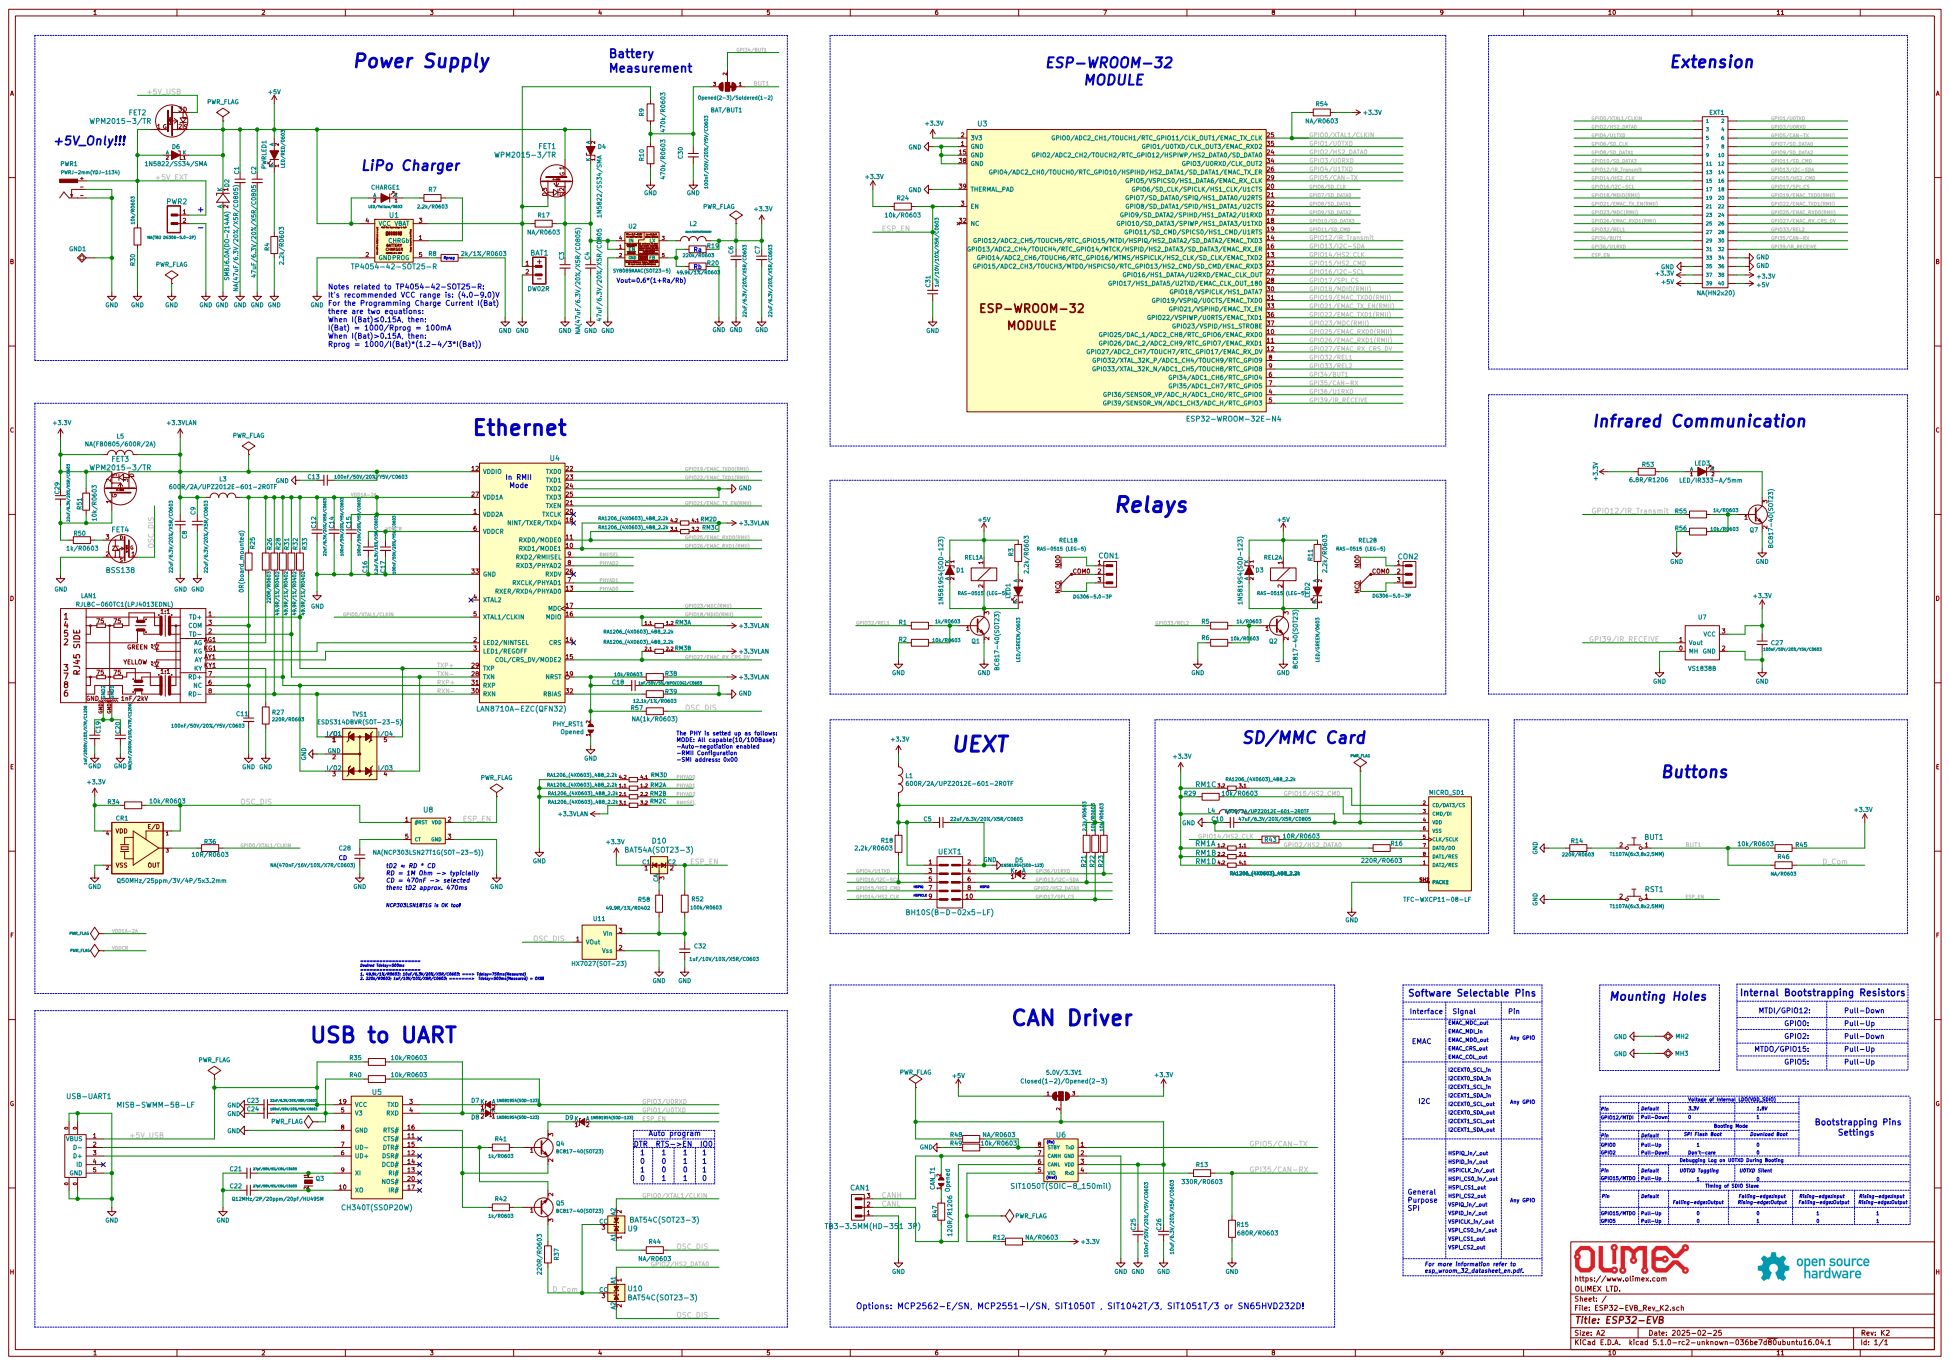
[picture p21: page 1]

2 PWRLED1 LED/RED/0603 GND GND GND GND GND

GPIO5/CAN-TX GPIO12/IR_Transmit GPI36/U1RXD GPIO4/U1TXD USB to UART

Rprog = 1000/I(Bat)*(1.2-4/3*I(Bat)) Rprog K

load current capability! Lx=2.2uH

Do not float. Enable control. FB Input Current, I(FB)=50nA(max) Feedback Reference Voltage, V(REF)=0.6V

It's recommended VCC range is: (4.0-9.0)V
For the Programming Charge Current I(Bat)
GND
there are two equations:
When I(Bat)0.15A, then:
I(Bat) = 1000/Rprog = 100mA
When I(Bat)>0.15A, then:
GPIO19/EMAC_TXD0(RMII) GPIO22/EMAC_TXD1(RMII) GPIO21/EMAC_TX_EN(RMII) The PHY is setted up as follows: MODE: All capable(10/100Base)

GPIO27/EMAC_RX_CRS_DV GPIO18/MDIO(RMII) GPIO23/MDC(RMII) RMIISEL PHYAD2 PHYAD1 PHYAD0 1 2PHY_RST1 Opened GND

GND Options: MCP2562-E/SN, MCP2551-I/SN, SIT1050T , SIT1042T/3, SIT1051T/3 or SN65HVD232D!

RD = 1M Ohm -> typiclally CD = 470nF -> selected

MISB-SWMM-5B-LF GND

File: ESP32-EVB_Rev_K2.sch Sheet: / OLIMEX LTD. https://www.olimex.com

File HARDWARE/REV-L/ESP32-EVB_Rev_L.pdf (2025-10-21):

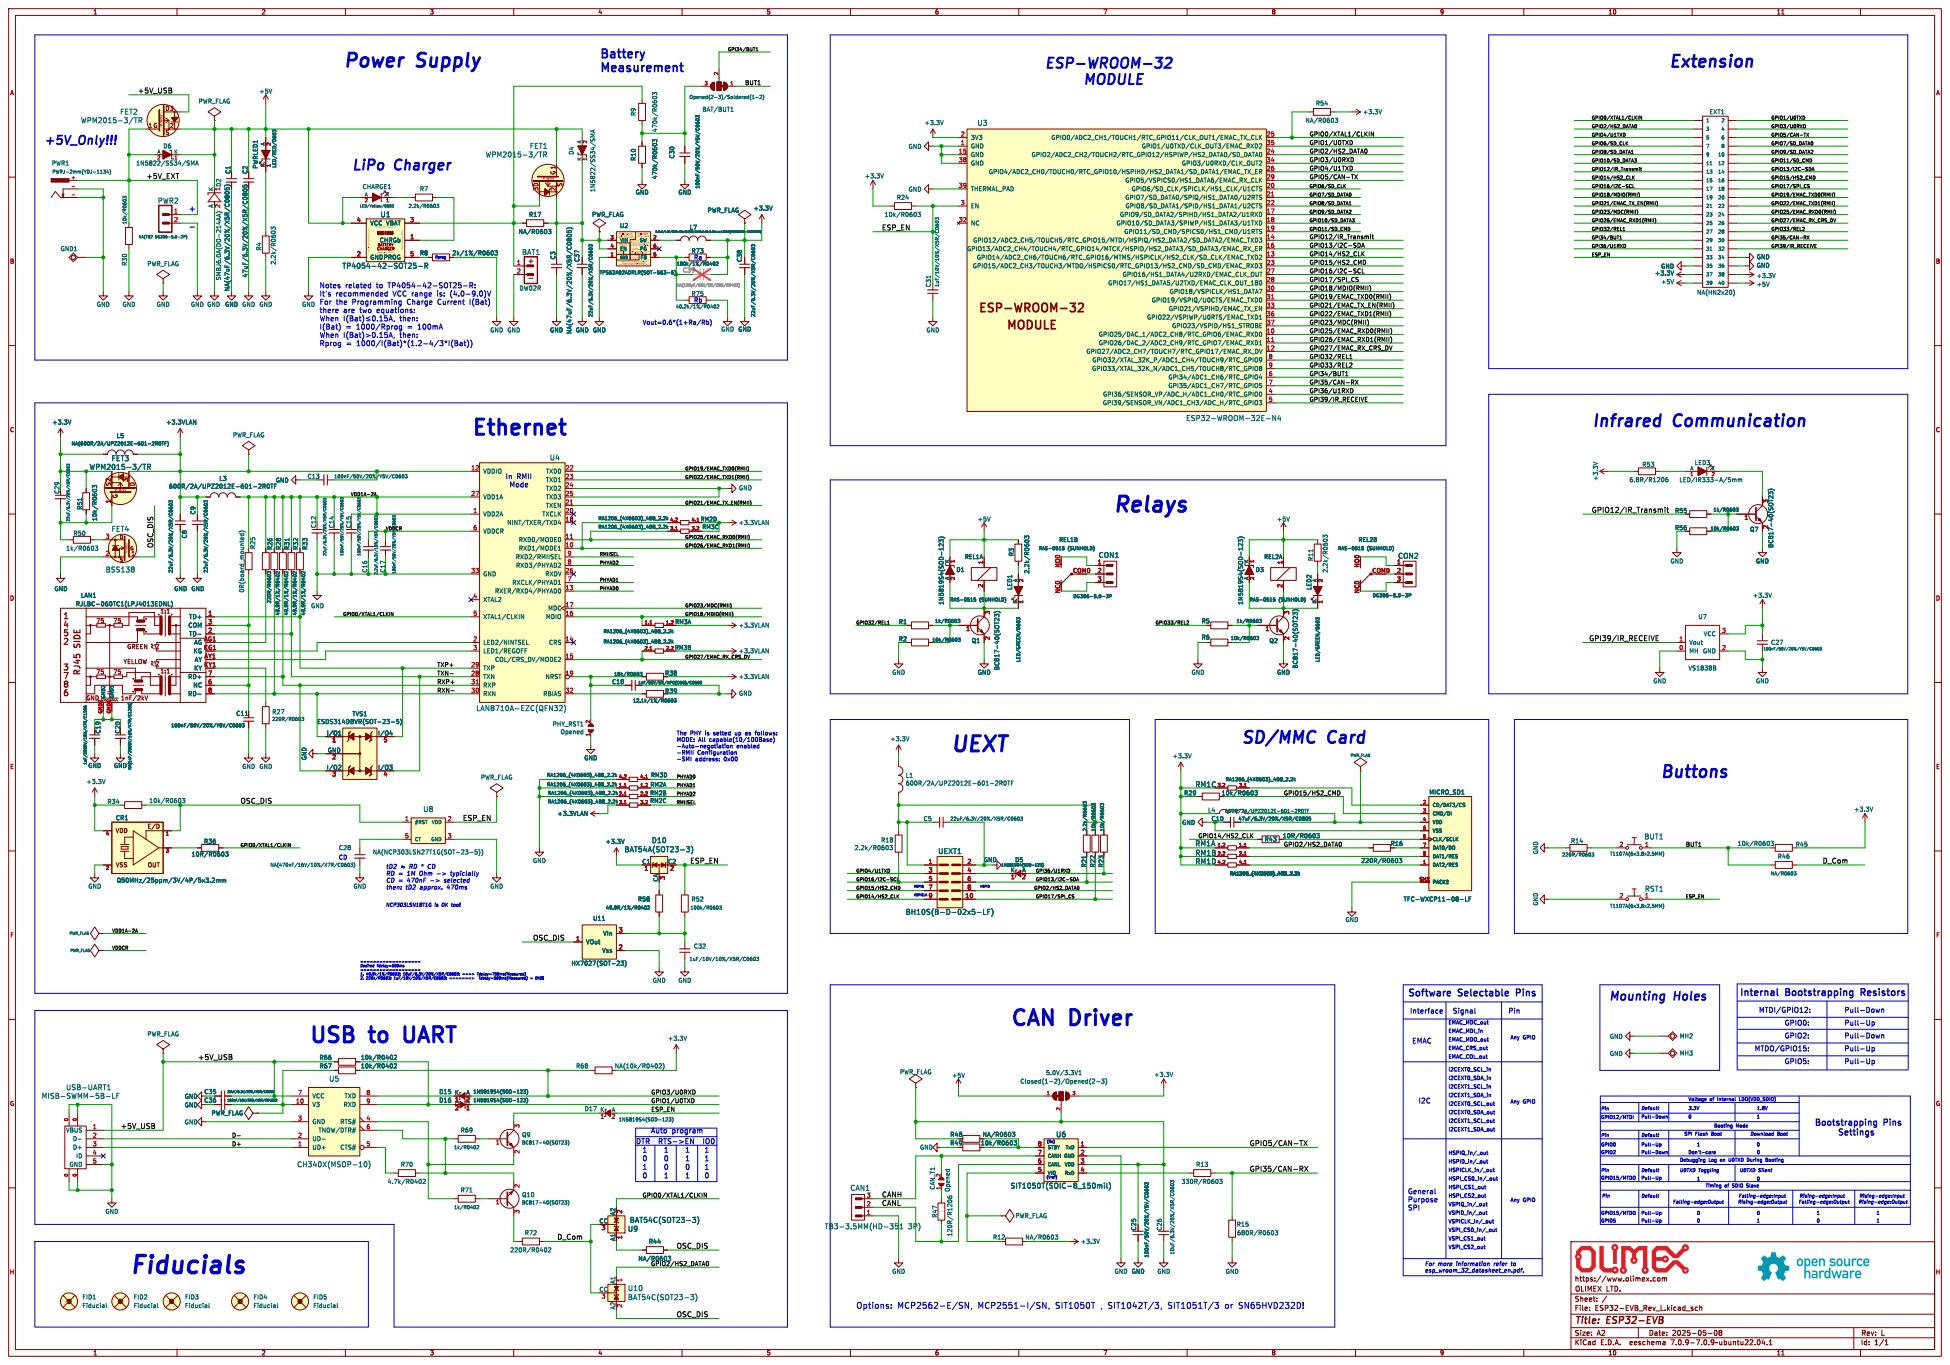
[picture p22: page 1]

GPIO13/I2C-SDA GPIO12/IR_Transmit GPIO2/HS2_DATA0 GPIO0/XTAL1/CLKIN GPIO5/CAN-TX GPIO4/U1TXD GPIO1/U0TXD GPIO3/U0RXD

2 PWRLED1 LED/RED/0603 GND GND

GPIO16/I2C-SCL GPIO18/MDIO(RMII) GPIO21/EMAC_TX_EN(RMII)

Cout=(10~22)uF/6.3V/X5Rþÿ(Vout"e1.8V). 22uFRecommended! Cout=22uF/6.3V/X5Rþÿ(1.2V"dVout<1.8V) Cout=44uF/6.3V/X5Rþÿ(0.6V"dVout<1.2V) DCR<50mR

In casea loweroutputrippleisdesired,higheroutputcapacitancecanhelpreducetheripple. Lx=1.0uH

Donotfloat. Enablecontrol. FB Input Current,I(FB)=100nA(max) FeedbackReferenceVoltage,V(REF)=0.6V
Rb mustnotbehigherthanþÿ100k© toprovideacceptablenoisesensitivity. ShutdownCurrentI(SHDN)=0.01-2uA

Rprog Notes related to TP4054-42-SOT25-R:

2 LED1 LED/GREEN/0603 C37 22uF/6.3V/20%/X5R/C0603 GND GND

GPIO21/EMAC_TX_EN(RMII) GPIO15/HS2_CMD GPIO14/HS2_CLK
GPIO23/MDC(RMII) GPIO17/SPI_CS GPI34/BUT1 GPI39/IR_RECEIVE
GPIO25/EMAC_RXD0(RMII) GPIO27/EMAC_RX_CRS_DV GPIO19/EMAC_TXD0(RMII) GPIO32/REL1 GPIO18/MDIO(RMII)

there are two equations: When þÿI(Bat)"d0.15A, then:

PHYAD0 GPIO18/MDIO(RMII) GPIO23/MDC(RMII) GPIO19/EMAC_TXD0(RMII)
PHYAD1 GPIO26/EMAC_RXD1(RMII)

The PHY is setted up as follows: MODE: All capable(10/100Base)
-RMII Configuration
-SMI address: 0x00

Pull-Up Pull-Down

Don't-care Any GPIO

Voltage of Internal LDO(VDD_SDIO)

Timing of SDIO Slave Pull-Up 1
1 VSPI_CS1_out 1

Debugging Log on U0TXD During Booting

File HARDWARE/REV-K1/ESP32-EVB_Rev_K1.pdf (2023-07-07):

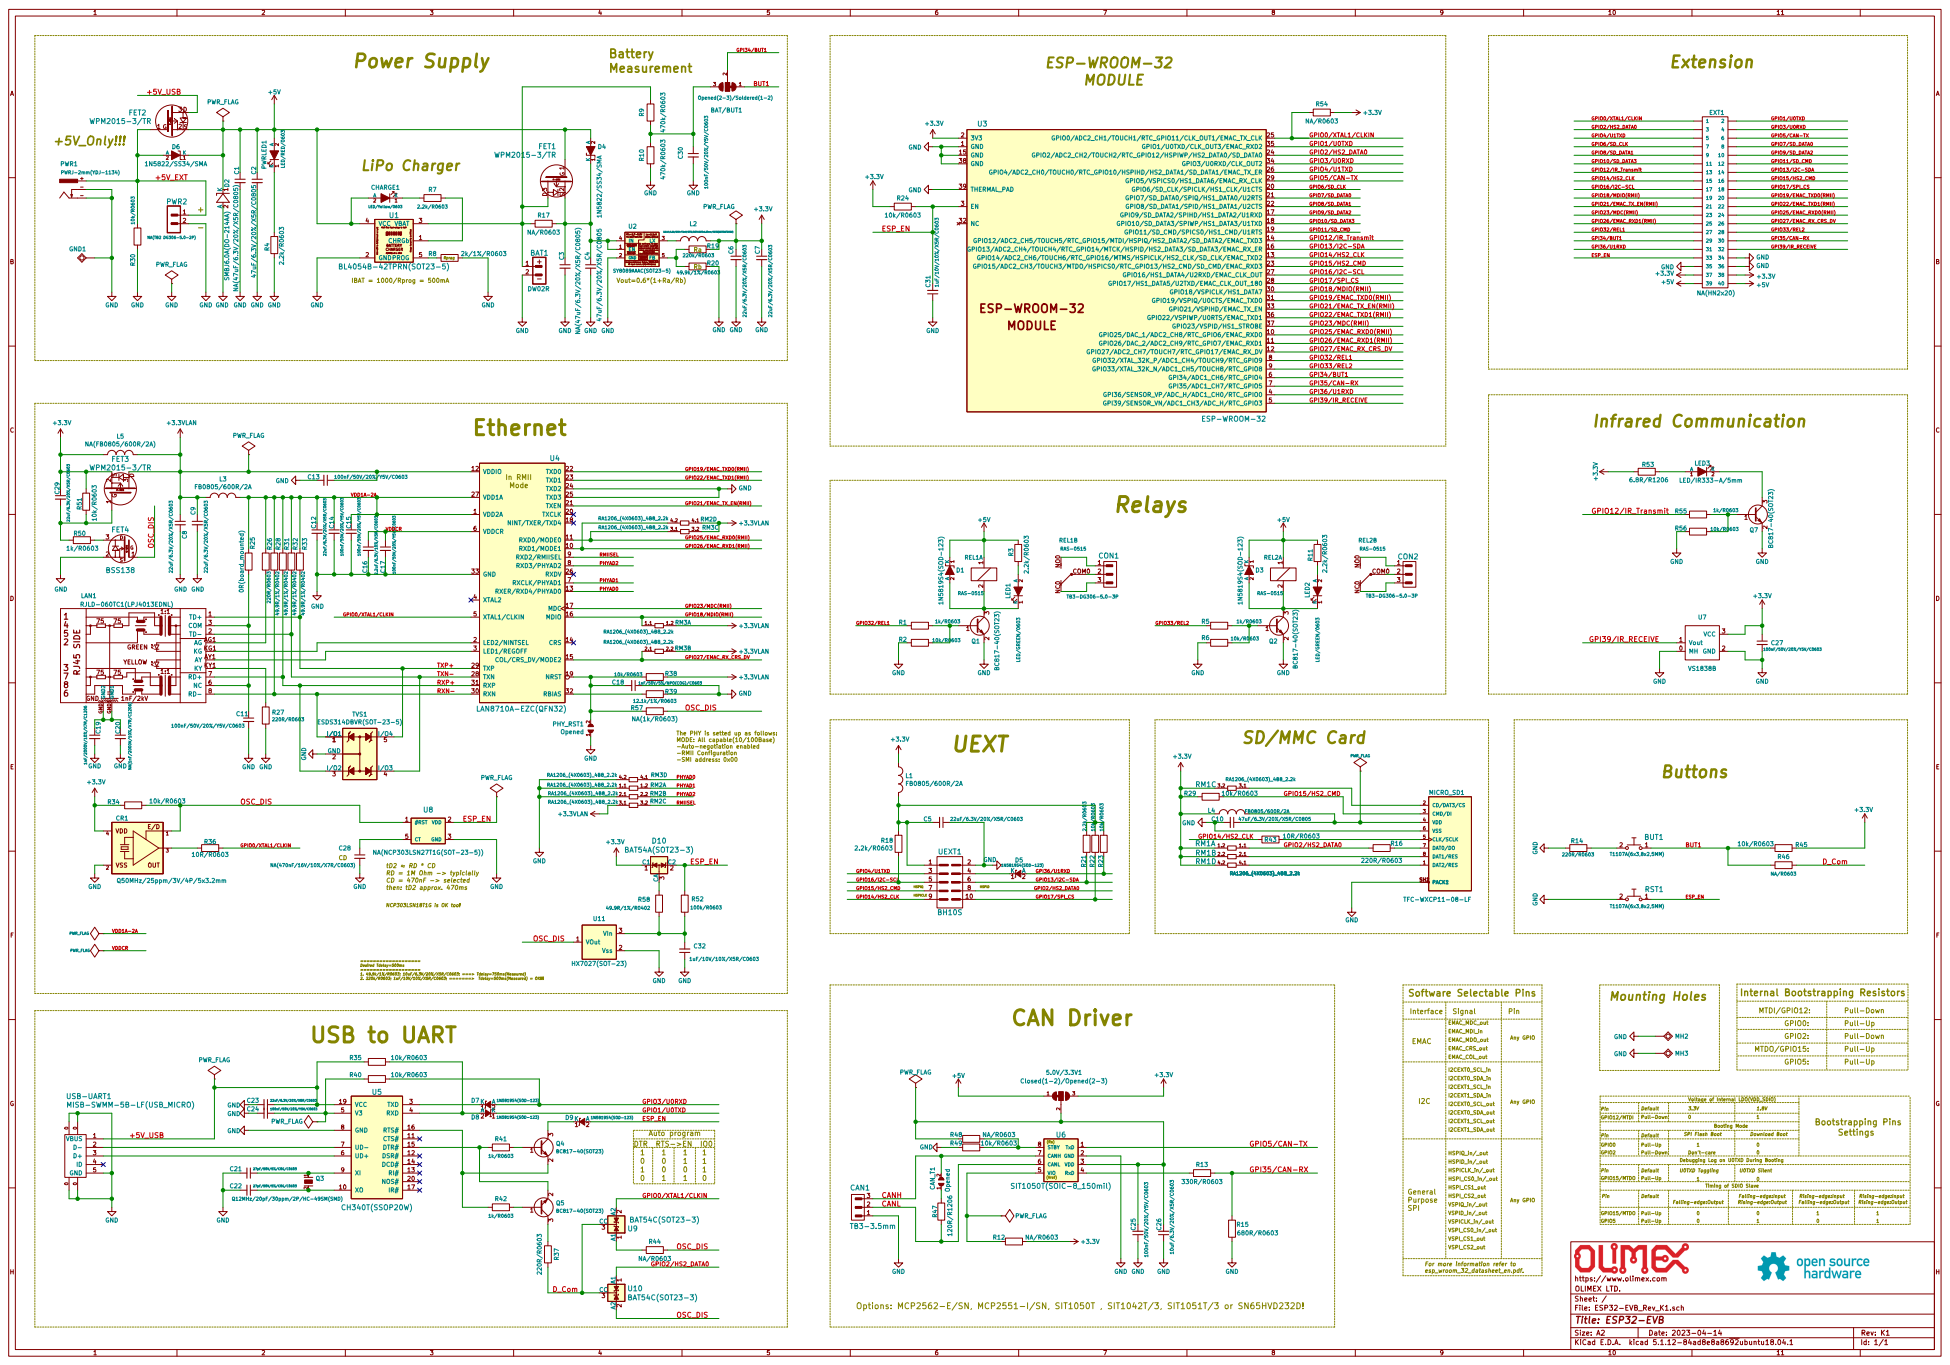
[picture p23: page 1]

Vout=0.6*(1+Ra/Rb) EN 1 GND 2

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

load current capability! Lx=2.2uH

ESP_EN GPIO19/EMAC_TXD0(RMII) RXN- RXP+ TXN- TXP+ OSC_DIS
PWR_FLAG

GPIO22/EMAC_TXD1(RMII) GPIO21/EMAC_TX_EN(RMII) GPIO25/EMAC_RXD0(RMII) GPIO25/EMAC_RXD0(RMII) GPIO18/MDIO(RMII) GPIO27/EMAC_RX_CRS_DV

1 2PHY_RST1 Opened C18 1nF/50V/5%/NPO(COG)/C0603 R39 GND

The PHY is setted up as follows: MODE: All capable(10/100Base)
-Auto-negotiation enabled
-RMII Configuration
2 CA3 D10 BAT54A(SOT23-3) GND

RD = 1M Ohm -> typiclally CD = 470nF -> selected

then: tD2 approx. 470ms USB to UART

Voltage of Internal LDO(VDD_SDIO) Signal Software Selectable Pins

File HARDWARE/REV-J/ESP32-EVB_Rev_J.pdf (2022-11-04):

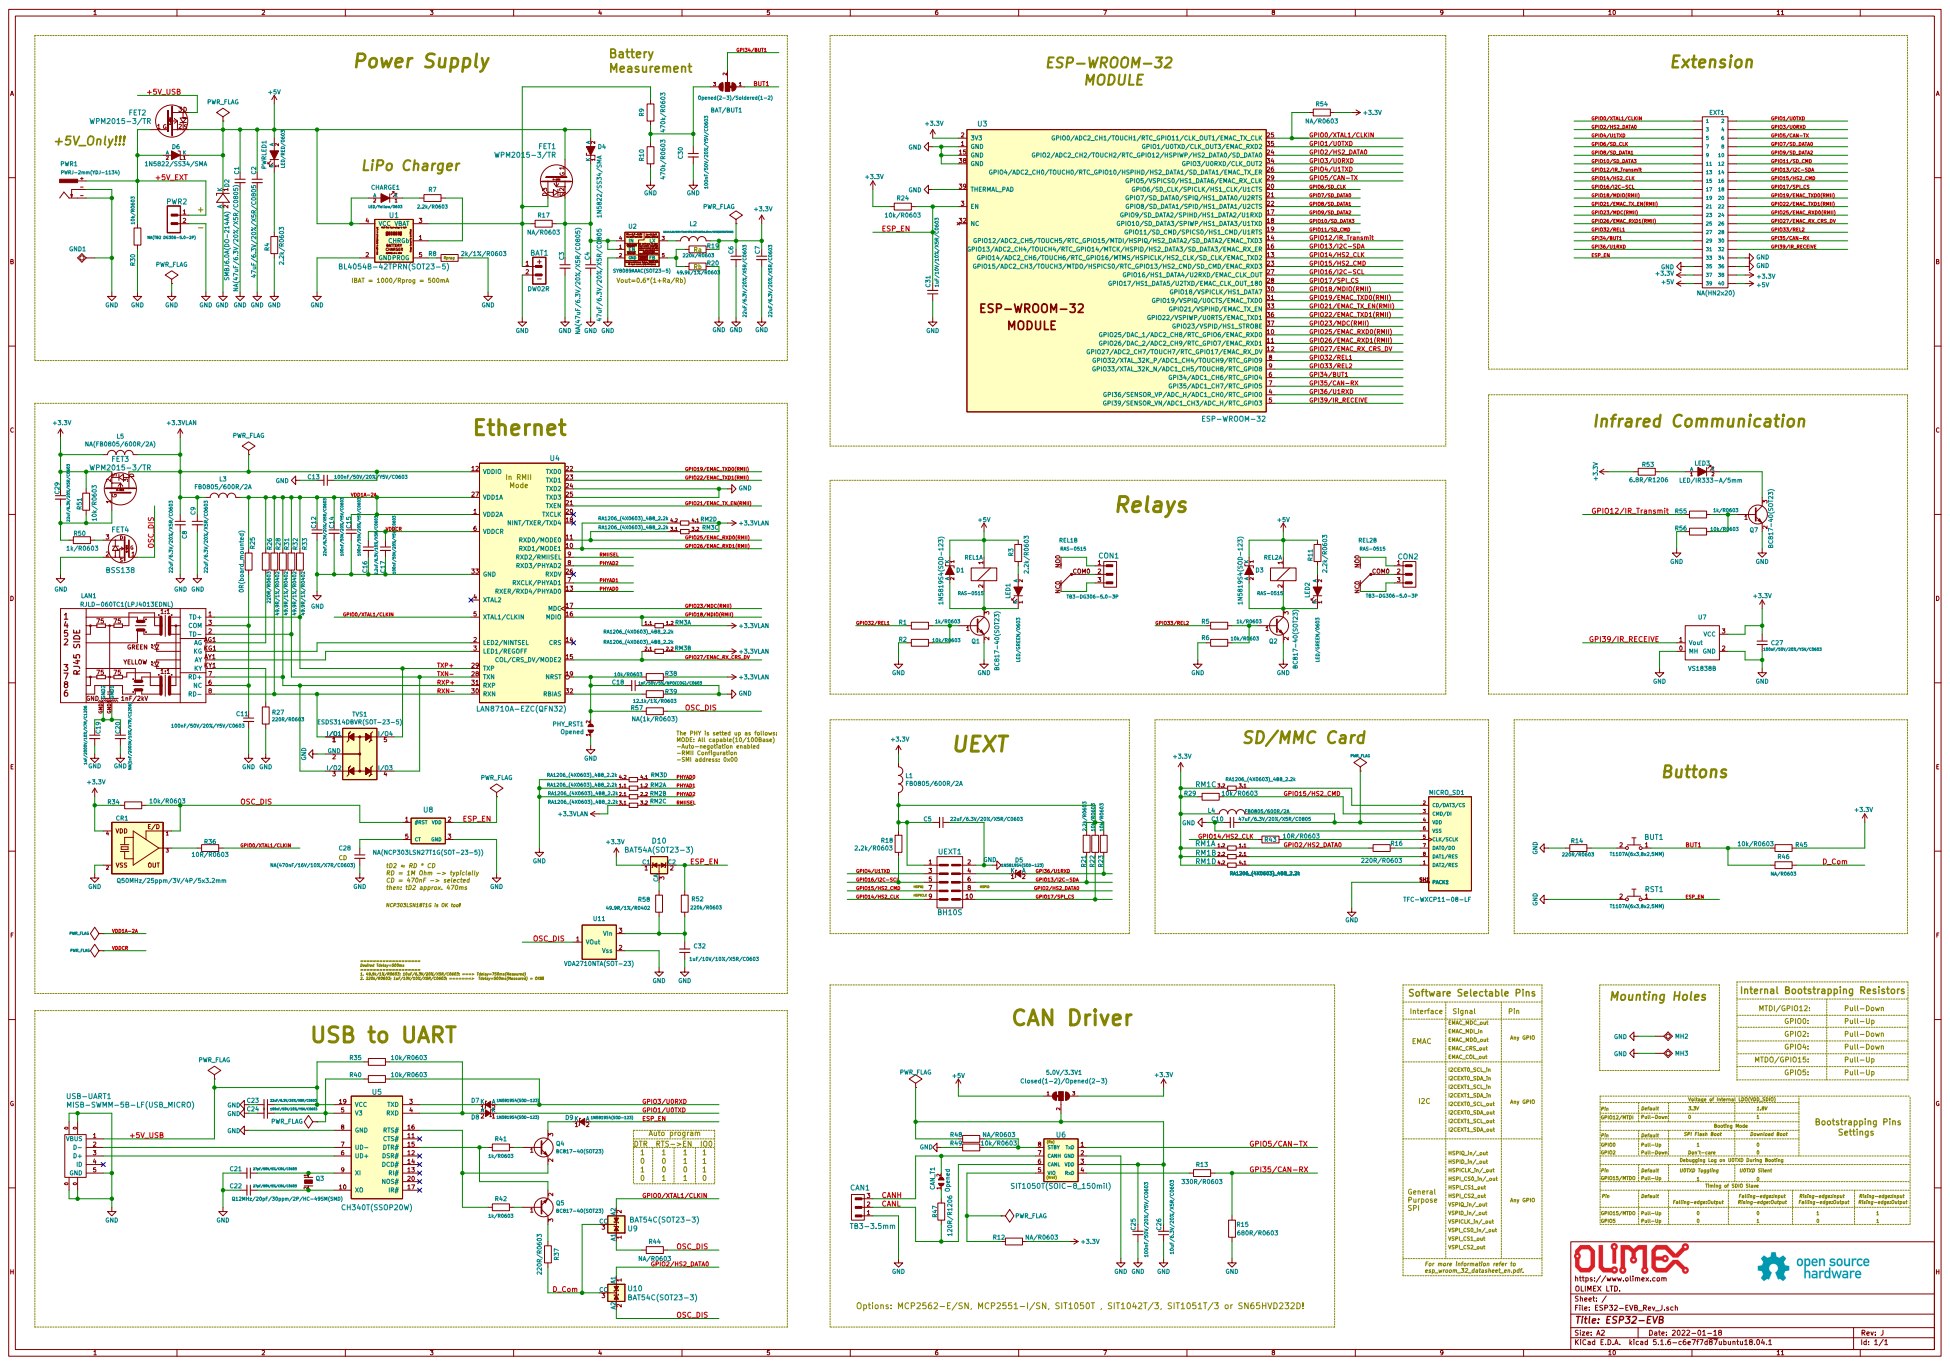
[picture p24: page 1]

2 PWRLED1 LED/RED/0603 GND GND GND GND OSC_DIS

Vout=0.6*(1+Ra/Rb) EN 1 GND 2

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

load current capability! Lx=2.2uH

Vout=0.6*(1+Ra/Rb) Ethernet

GPIO26/EMAC_RXD1(RMII) GPIO25/EMAC_RXD0(RMII) GPIO21/EMAC_TX_EN(RMII) GPIO22/EMAC_TXD1(RMII)

2 LED2 LED/GREEN/0603R1 1k/R0603 +3.3VLAN GND GNDC9 22uF/6.3V/20%/X5R/C0603 C8 22uF/6.3V/20%/X5R/C0603 GND GND

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

RD = 1M Ohm -> typiclally CD = 470nF -> selected

Settings GPIO4: NCP303LSN18T1G is OK too!

1. 49.9k/1%/R0603; 10uF/6.3V/20%/X5R/C0603; ===> Tdelay=750ms(Measured) 2. 220k/R0603; 1uF/10V/10%/X5R/C0603; =======> Tdelay=500ms(Measured) = OK!!!

Pull-Up GPIO2: Internal Bootstrapping Resistors

Pull-Down

File: ESP32-EVB_Rev_J.sch Sheet: / OLIMEX LTD. https://www.olimex.com

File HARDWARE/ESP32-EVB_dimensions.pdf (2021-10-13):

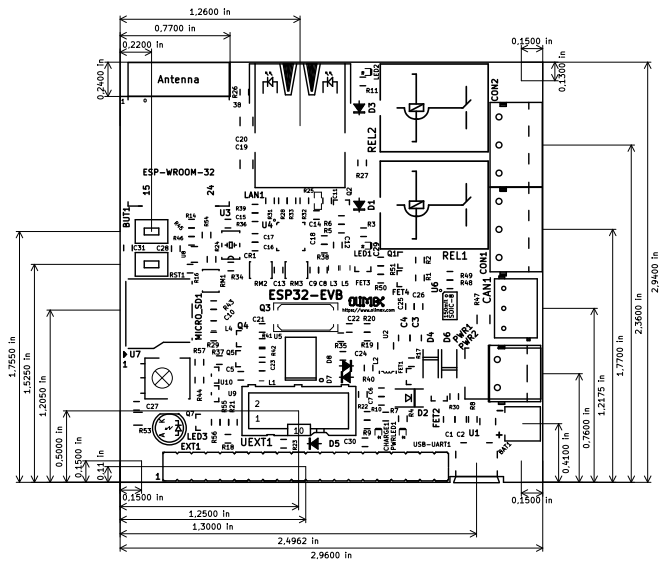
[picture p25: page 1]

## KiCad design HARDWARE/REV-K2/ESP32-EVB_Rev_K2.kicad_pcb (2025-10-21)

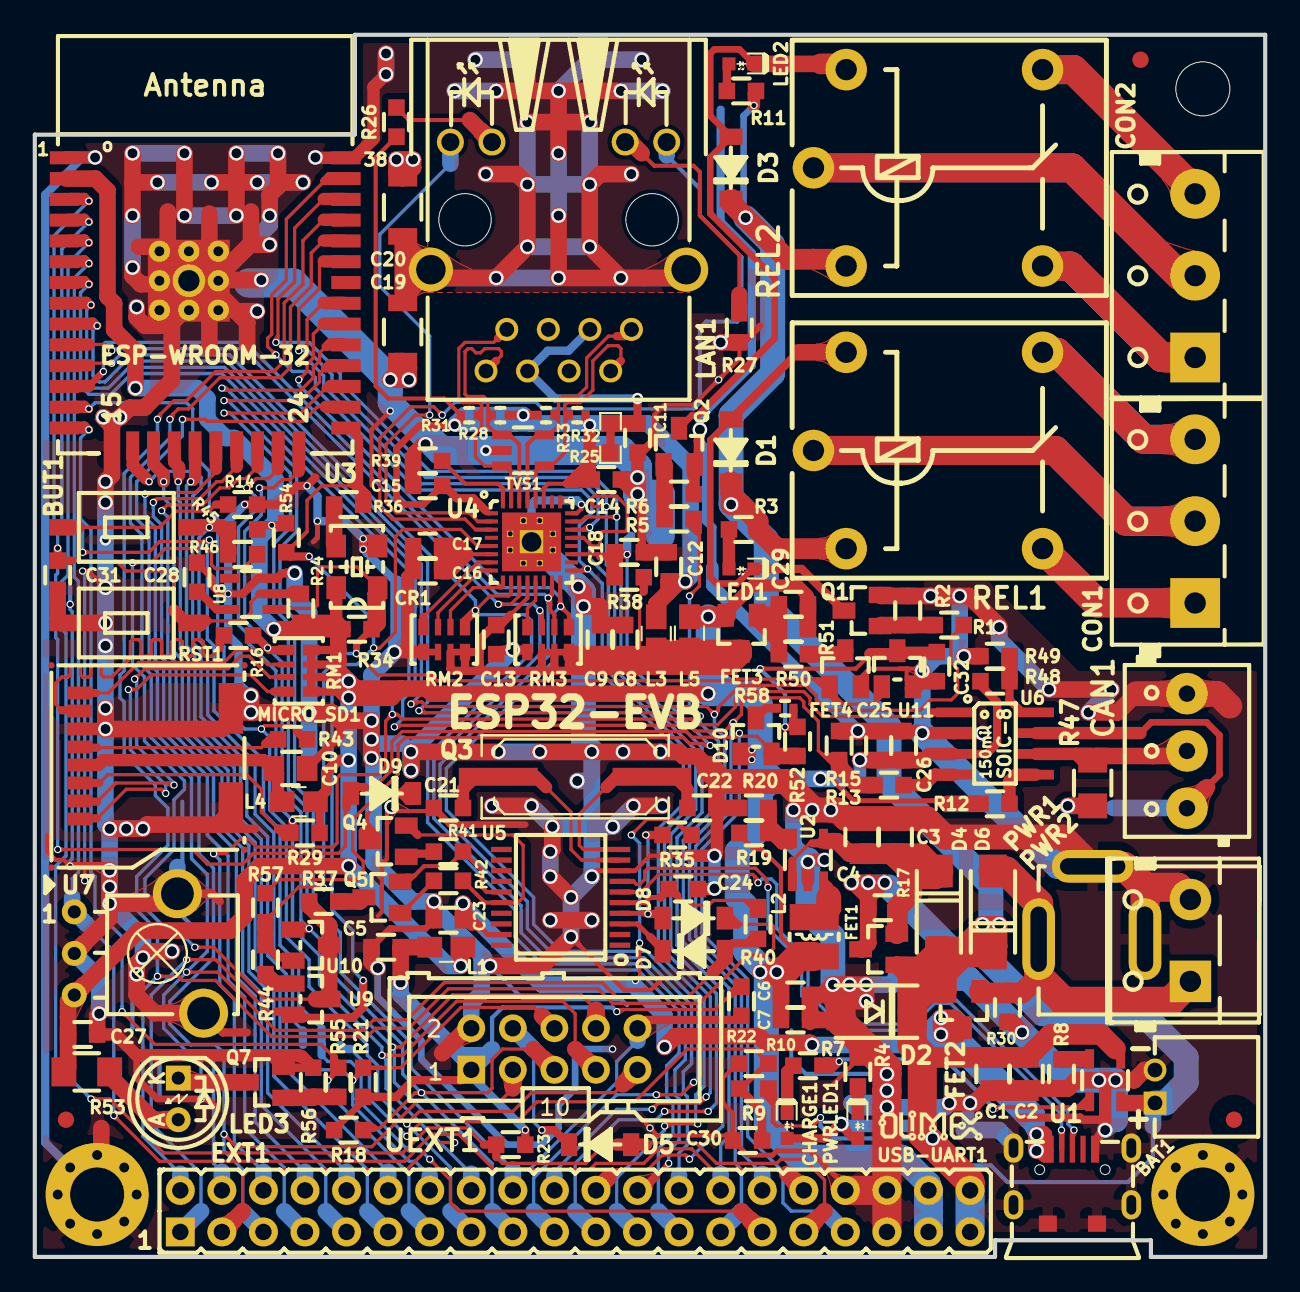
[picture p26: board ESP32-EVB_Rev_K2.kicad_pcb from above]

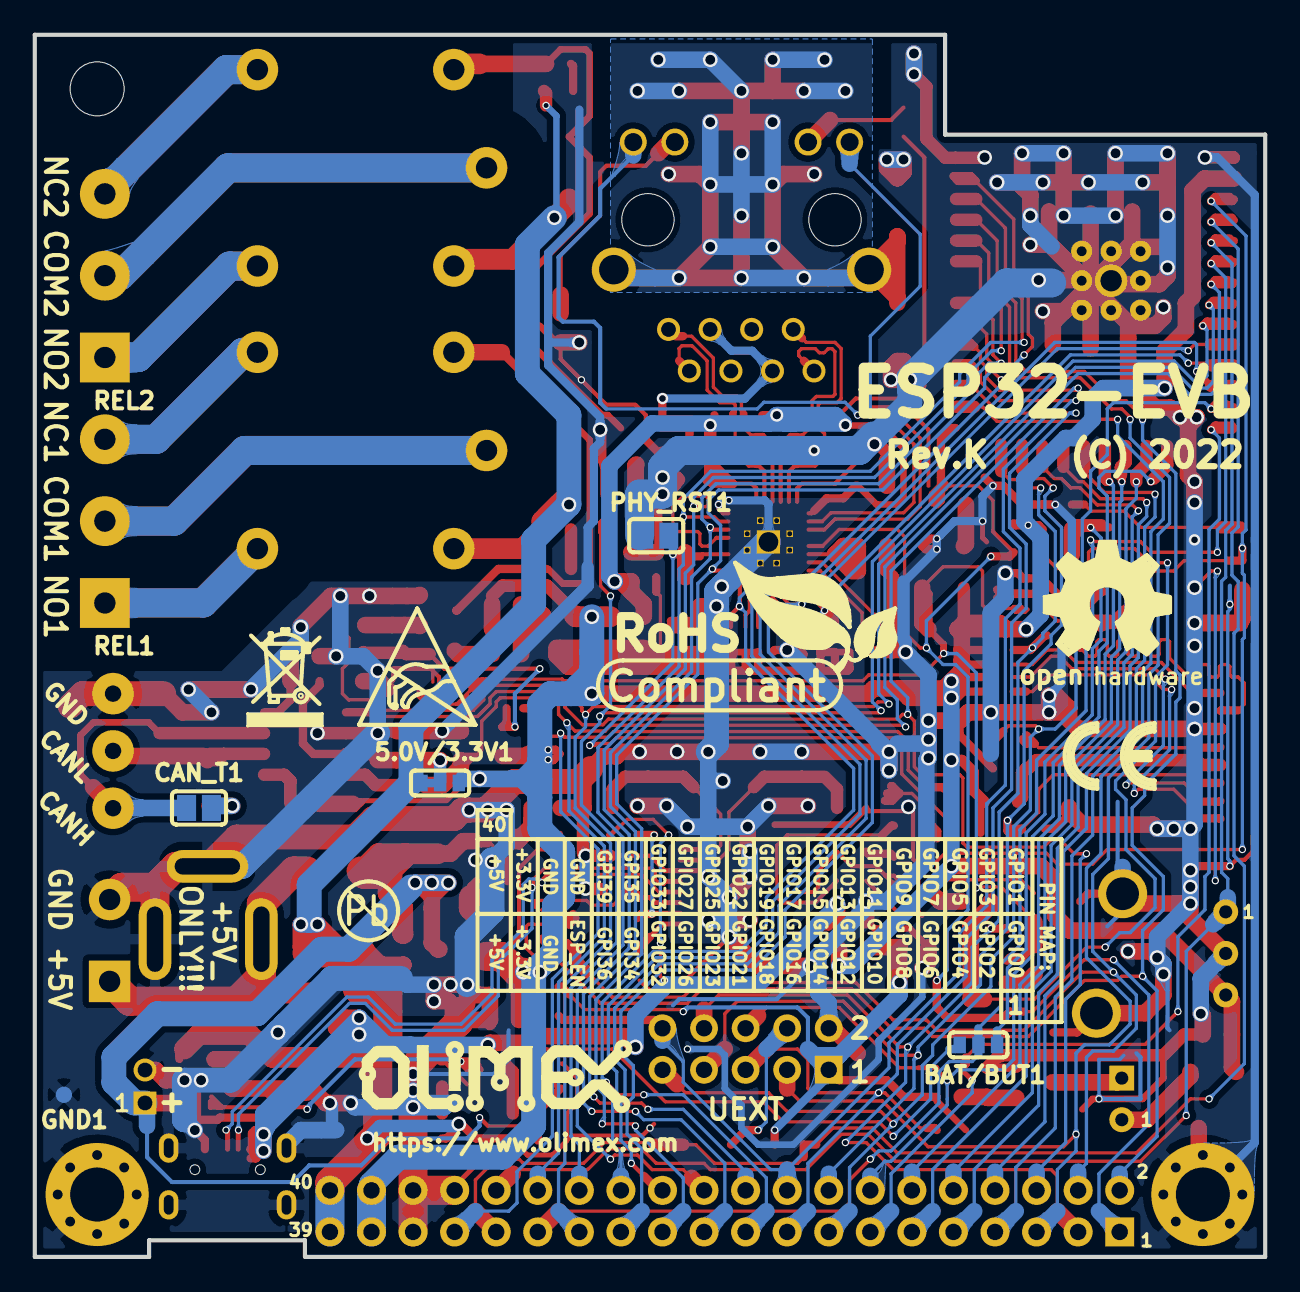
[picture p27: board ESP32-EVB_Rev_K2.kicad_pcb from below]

Board: 2 copper layers, 75.2 x 74.7 mm, 170 parts (12 on the bottom side), 120 nets.

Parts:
5.0V/3.3V1: Closed(1-2)/Opened(2-3); SJ_2_SMALL_12_TIED
BAT1: DW02R; LIPO_BAT-CON2DW02R
BAT/BUT1: Opened(2-3)/Soldered(1-2); SJ_2_SMALL
BUT1: T1107A(6x3,8x2,5MM)
C1, C3: NA(47uF/6.3V/20%/X5R/C0805); C_0805_5MIL_DWS
C2, C4, C10: 47uF/6.3V/20%/X5R/C0805; C_0805_5MIL_DWS
C5, C6, C7, C8, C9, C12, C23, C29: 22uF/6.3V/20%/X5R/C0603; C_0603_5MIL_DWS
C11, C13, C14, C15, C17, C24, C25, C27, C30: 100nF/50V/20%/Y5V/C0603; C_0603_5MIL_DWS
C16: 2.2uF/6.3V/10%/X5R/C0603; C_0603_5MIL_DWS
C18: 1nF/50V/5%/NPO(COG)/C0603; C_0603_5MIL_DWS
C19: 1nF/2000V/10%/X7R/C1206; C_1206_5MIL_DWS_ISO
C20: NA(1nF/2000V/10%/X7R/C1206); C_1206_5MIL_DWS_ISO
C21, C22: 27pF/50V/5%/C0G/C0603; C_0603_5MIL_DWS
C26: 10uF/6.3V/20%/X5R/C0603; C_0603_5MIL_DWS
C28: NA(470nF/16V/10%/X7R/C0603); C_0603_5MIL_DWS
C31, C32: 1uF/10V/10%/X5R/C0603; C_0603_5MIL_DWS
CAN1: TB3-3.5ММ(HD-351 3P); TB3-3.5mm
CAN_T1: Opened; SJ
CHARGE1: LED/Yellow/0603; LED_0603_KA
CON1, CON2: DG306-5.0-3P; TB3-DG306-5.0_3P
CR1: Q50MHz/25ppm/3V/4P/5x3.2mm; 5032-4P_HCX-3S
D1, D3, D5, D7, D8, D9: 1N5819S4(SOD-123); SOD-123_1C-2A_KA
D2: SMBJ6.0A(DO-214AA); DO214AA_1(K)-2(A)
D4, D6: 1N5822/SS34/SMA; SMA-KA
D10: BAT54A(SOT23-3); SOT23-3
EXT1: NA(HN2x20); HN2x20
FET1, FET2, FET3: WPM2015-3/TR; SOT23
FET4: BSS138; SOT23
Fid1, Fid2, Fid3: Fiducial1x3
GND1: TESTPAD; TESTPAD_40-ROUND
L1, L3, L4: 600R/2A/UPZ2012E-601-2R0TF; L_0805_5MIL_DWS
L2: 2.2uH/NRS3015T2R2MNGH; CD32
L5: NA(FB0805/600R/2A); L_0805_5MIL_DWS
LAN1: RJLBC-060TC1(LPJ4013EDNL); RJLBC-060TC1
LED1, LED2: LED/GREEN/0603; LED_0603_KA
LED3: LED/IR333-A/5mm; LED-5mm-PTH-AK
Logo-OSHW: LOGO_OPENHARDWARE_8x8
Logo-Olimex-Big: OLIMEX_LOGO_TB
Logo-Olimex_Small: LOGO_OLIMEX_80
MH1: Mounting_hole_Shield_3.3mm; Mounting_hole_3.3mm
MH2, MH3: Mounting_hole_Shield_3.3mm
MICRO_SD1: TFC-WXCP11-08-LF
PHY_RST1: Opened; SJ
PWR1: PWRJ-2mm(YDJ-1134); PWRJ-2mm(YDJ-1136)
PWR2: NA(TB2 DG306-5.0-2P); TB2-DG306-5.0_2P
PWRLED1: LED/RED/0603; LED_0603_KA
Q1, Q2, Q4, Q5, Q7: BC817-40(SOT23); SOT23
Q3: Q12MHz/2P/20ppm/20pF/HU49SM; Q_49U3HMS
R1, R5, R41, R42, R50, R55: 1k/R0603; R_0603_5MIL_DWS
R2, R6, R22, R23, R24, R29, R30, R34, R35, R38, R40, R45, R49, R51, R56: 10k/R0603; R_0603_5MIL_DWS
R3, R4, R7, R11, R18, R21: 2.2k/R0603; R_0603_5MIL_DWS
R8: 2k/1%/R0603; R_0603_5MIL_DWS
R9, R10: 470k/R0603; R_0603_5MIL_DWS
R12, R17, R44, R46, R48, R54: NA/R0603; R_0603_5MIL_DWS
R13: 330R/R0603; R_0603_5MIL_DWS
R14, R16, R26, R27, R37: 220R/R0603; R_0603_5MIL_DWS
R15: 680R/R0603; R_0603_5MIL_DWS
R19: 220k/R0603; R_0603_5MIL_DWS
R20: 49.9k/1%/R0603; R_0603_5MIL_DWS
R25: 0R(board_mounted); 0R_0603
R28, R31, R32, R33, R58: 49.9R/1%/R0402; R_0402_5MIL_DWS
R36, R43: 10R/R0603; R_0603_5MIL_DWS
R39: 12.1k/1%/R0603; R_0603_5MIL_DWS
R47: 120R/R1206; R_1206_5MIL_DWS
R52: 100k/R0603; R_0603_5MIL_DWS
R53: 6.8R/R1206; R_1206_5MIL_DWS
R57: NA(1k/R0603); R_0603_5MIL_DWS
REL1, REL2: RAS-0515 (LEG-5); Relay_RAS-05-15
RM1, RM2, RM3: RA1206_(4X0603)_4B8_2.2k; R_MATRIX_4
RST1: T1107A(6x3,8x2,5MM)
Sign-Antistatic: Val**; LOGO_ANTISTATIC_1
Sign-PbFree: LOGO_PBFREE
Sign-RecycleBin: LOGO_RECYCLEBIN_1
Sign-RoHS: Val**; LOGO_ROHS_1
Sign_CE: CE_Sign
TVS1: ESDS314DBVR(SOT-23-5); SOT-23-5
U1: TP4054-42-SOT25-R; SOT-23-5
U2: SY8089AAAC(SOT23-5); SOT-23-5
U3: ESP32-WROOM-32E-N4; ESP-WROOM-32_MODULE
U4: LAN8710A-EZC(QFN32); QFN32_EP(33)_5.00x5.00x0.90mm_Pitch_0.50mm
U5: CH340T(SSOP20W); SSOP-20W
U6: SIT1050T(SOIC-8_150mil); SOIC-8_150mil
U7: VS1838B; RPM7236-H8
U8: NA(NCP303LSN27T1G(SOT-23-5)); SOT-23-5
U9, U10: BAT54C(SOT23-3); SOT23-3
U11: HX7027(SOT-23); SOT-23
UEXT1: BH10S(B-D-02x5-LF); UEXT_ML10
USB-UART1: MISB-SWMM-5B-LF; USB-MICRO_MISB-SWMM-5B_LF

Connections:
+3.3V: 5.0V/3.3V1.3, C6.1, C7.1, C27.1, C29.1, CR1.4, D10.1, EXT1.37, EXT1.38, FET3.2, L1.1, L2.2, L4.1, L5.1, R12.1, R19.2, R24.1, R29.1, R34.1, R45.1, R51.1, R53.1, R54.2, RM1.1.2, RM1.2.2, RM1.3.2, RM1.4.2, U3.2, U7.3
+3.3VLAN: C8.1, C9.1, C13.1, FET3.3, L3.1, L5.2, R38.2, RM2.3.1, RM2.4.1, RM3.1.2, RM3.2.2, RM3.3.2, U4.12
+5V: 5.0V/3.3V1.1, C1.1, C2.1, CHARGE1.2, D1.1, D2.1, D3.1, D4.2, D6.1, EXT1.39, EXT1.40, FET1.1, FET2.2, PWRLED1.2, R3.1, R11.1, REL1.1, REL2.1, U1.4
/+5V_EXT: D6.2, FET2.1, PWR1.+, PWR2.1, R30.1
/+5V_USB: C23.1, FET2.3, R35.1, U5.19, USB-UART1.1
/BUT1: BAT/BUT1.1, BUT1.1, R45.2, R46.1
/CANH: CAN1.3, CAN_T1.2, U6.7
/CANL: CAN1.2, R47.2, U6.6
/D_Com: R37.2, R46.2, U9.3, U10.3
/ESP_EN: C31.2, D9.2, D10.2, EXT1.33, R24.2, R52.2, RST1.1, U3.3, U8.2
/GPI34/BUT1: BAT/BUT1.2, EXT1.29, U3.6
/GPI35/CAN-RX: EXT1.30, R13.1, R15.1, U3.7
/GPI36/U1RXD: D5.2, EXT1.31, R23.2, U3.4
/GPI39/IR_RECEIVE: EXT1.32, U3.5, U7.1
/GPIO0/XTAL1/CLKIN: EXT1.1, R36.2, R54.1, U3.25, U4.5, U9.2
/GPIO1/U0TXD: D8.1, EXT1.2, U3.35
/GPIO2/HS2_DATA0: EXT1.3, R16.1, RM1.1.1, U3.24, U10.1, UEXT1.8
/GPIO3/U0RXD: D7.2, EXT1.4, R40.2, U3.34
/GPIO4/U1TXD: EXT1.5, U3.26, UEXT1.3
/GPIO5/CAN-TX: EXT1.6, U3.29, U6.1
/GPIO6/SD_CLK: EXT1.7, U3.20
/GPIO7/SD_DATA0: EXT1.8, U3.21
/GPIO8/SD_DATA1: EXT1.9, U3.22
/GPIO9/SD_DATA2: EXT1.10, U3.17
/GPIO10/SD_DATA3: EXT1.11, U3.18
/GPIO11/SD_CMD: EXT1.12, U3.19
/GPIO12/IR_Transmit: EXT1.13, R55.1, U3.14
/GPIO13/I2C-SDA: EXT1.14, R21.2, U3.16, UEXT1.6
/GPIO14/HS2_CLK: EXT1.15, R43.1, U3.13, UEXT1.9
/GPIO15/HS2_CMD: EXT1.16, MICRO_SD1.3, R29.2, U3.23, UEXT1.7
/GPIO16/I2C-SCL: EXT1.17, R18.2, U3.27, UEXT1.5
/GPIO17/SPI_CS: EXT1.18, R22.2, U3.28, UEXT1.10
/GPIO18/MDIO(RMII): EXT1.19, RM3.1.1, U3.30, U4.16
/GPIO19/EMAC_TXD0(RMII): EXT1.20, U3.31, U4.22
/GPIO21/EMAC_TX_EN(RMII): EXT1.21, U3.33, U4.21
/GPIO22/EMAC_TXD1(RMII): EXT1.22, U3.36, U4.23
/GPIO23/MDC(RMII): EXT1.23, U3.37, U4.17
/GPIO25/EMAC_RXD0(RMII): EXT1.24, RM3.3.1, U3.10, U4.11
/GPIO26/EMAC_RXD1(RMII): EXT1.25, RM2.4.2, U3.11, U4.10
/GPIO27/EMAC_RX_CRS_DV: EXT1.26, RM3.2.1, U3.12, U4.15
/GPIO32/REL1: EXT1.27, R1.1, U3.8
/GPIO33/REL2: EXT1.28, R5.1, U3.9
/OSC_DIS: CR1.1, FET4.1, R34.2, R44.1, R57.2, U8.1, U10.2, U11.1
/PHYAD0: RM3.4.1, U4.13
/PHYAD1: RM2.1.2, U4.7
/PHYAD2: RM2.2.2, U4.8
/RMIISEL: RM2.3.2, U4.9
/RXN-: LAN1.8, R28.2, TVS1.1, U4.30
/RXP+: LAN1.7, R31.2, TVS1.3, U4.31
/TXN-: LAN1.2, R32.2, TVS1.4, U4.28
/TXP+: LAN1.1, R33.2, TVS1.5, U4.29
/VDD1A-2A: C12.1, C14.1, C15.1, L3.2, R25.1, R26.1, R28.1, R31.1, R32.1, R33.1, U4.1, U4.27
/VDDCR: C16.1, C17.1, U4.6
GND: BAT1.2, C1.2, C2.2, C3.2, C4.2, C5.1, C6.2, C7.2, C8.2, C9.2, C10.2, C11.2, C12.2, C13.2, C14.2, C15.2, C16.2, C17.2, C18.1, C19.2, C20.2, C21.2, C22.2, C23.2, C24.2, C25.1, C26.1, C27.2, C28.2, C30.2, C31.1, C32.1, CAN1.1, CR1.2, D2.2, EXT1.34, EXT1.35, EXT1.36, FET4.2, GND1.1, MH2.GND1, MH3.GND1, MICRO_SD1.6, MICRO_SD1.SH1, MICRO_SD1.SH2, PHY_RST1.1, PWR1.-, PWR2.2, Q1.2, Q2.2, Q7.2, R2.1, R4.2, R6.1, R8.1, R10.2, R14.2, R15.2, R20.2, R27.2, R30.2, R39.2, R49.2, R56.1, RM2.1.1, RM2.2.1, RM3.4.2, RST1.2, TVS1.2, U1.2, U2.2, U3.1, U3.15, U3.38, U3.39, U4.24, U4.25, U4.33, U5.8, U6.2, U7.0, U7.2, U8.3, U11.2, UEXT1.2, USB-UART1.0, USB-UART1.5
unnamed: 5.0V/3.3V1.2, C25.2, C26.2, R48.2, U6.3
unnamed: BAT1.1, FET1.3, R9.1, R17.1, U1.3
unnamed: BAT/BUT1.3, C30.1, R9.2, R10.1
unnamed: BUT1.2, R14.1
unnamed: C3.1, C4.1, D4.1, FET1.2, R17.2, U2.1, U2.4
unnamed: C5.2, L1.2, R18.1, R21.1, R22.1, R23.1, UEXT1.1
unnamed: C10.1, L4.2, MICRO_SD1.4
unnamed: C11.1, LAN1.3, LAN1.6, R25.2
unnamed: C18.2, PHY_RST1.2, R38.1, R57.1, U4.19
unnamed: C19.1, C20.1, LAN1.GND1, LAN1.GND2
unnamed: C21.1, Q3.1, U5.9
unnamed: C22.1, Q3.2, U5.10
unnamed: C24.1, R40.1, U5.5
unnamed: C28.1, U8.5
unnamed: C29.2, FET3.1, R50.2, R51.2
unnamed: C32.2, R52.1, R58.2, U11.3
unnamed: CAN_T1.1, R47.1
unnamed: CHARGE1.1, R7.2
unnamed: CON1.1, REL1.NO0
unnamed: CON1.2, REL1.COM0
unnamed: CON1.3, REL1.NC0
unnamed: CON2.1, REL2.NO0
unnamed: CON2.2, REL2.COM0
unnamed: CON2.3, REL2.NC0
unnamed: CR1.3, R36.1
unnamed: D1.2, LED1.1, Q1.3, REL1.2
unnamed: D3.2, LED2.1, Q2.3, REL2.2
unnamed: D5.1, UEXT1.4
unnamed: D7.1, U5.3
unnamed: D8.2, R35.2, U5.4
unnamed: D9.1, Q4.3
unnamed: D10.3, R58.1
unnamed: FET4.3, R50.1
unnamed: L2.1, U2.3
unnamed: LAN1.AG1, R26.2
unnamed: LAN1.AY1, U4.3
unnamed: LAN1.KG1, U4.2
unnamed: LAN1.KY1, R27.1
unnamed: LED1.2, R3.2
unnamed: LED2.2, R11.2
unnamed: LED3.1, R53.2
unnamed: LED3.2, Q7.3
unnamed: MICRO_SD1.1, RM1.4.1
unnamed: MICRO_SD1.2, RM1.3.1
unnamed: MICRO_SD1.5, R43.2
unnamed: MICRO_SD1.7, R16.2
unnamed: MICRO_SD1.8, RM1.2.1
unnamed: PWRLED1.1, R4.1
unnamed: Q1.1, R1.2, R2.2
unnamed: Q2.1, R5.2, R6.2
unnamed: Q4.1, R41.2
unnamed: Q4.2, R42.1, U5.16
unnamed: Q5.1, R42.2
unnamed: Q5.2, R41.1, U5.15
unnamed: Q5.3, R37.1
unnamed: Q7.1, R55.2, R56.2
unnamed: R7.1, U1.1
unnamed: R8.2, U1.5
unnamed: R12.2, U6.5
unnamed: R13.2, U6.4
unnamed: R19.1, R20.1, U2.5
unnamed: R39.1, U4.32
unnamed: R44.2, U9.1
unnamed: R48.1, R49.1, U6.8
unnamed: U5.6, USB-UART1.3
unnamed: U5.7, USB-UART1.2

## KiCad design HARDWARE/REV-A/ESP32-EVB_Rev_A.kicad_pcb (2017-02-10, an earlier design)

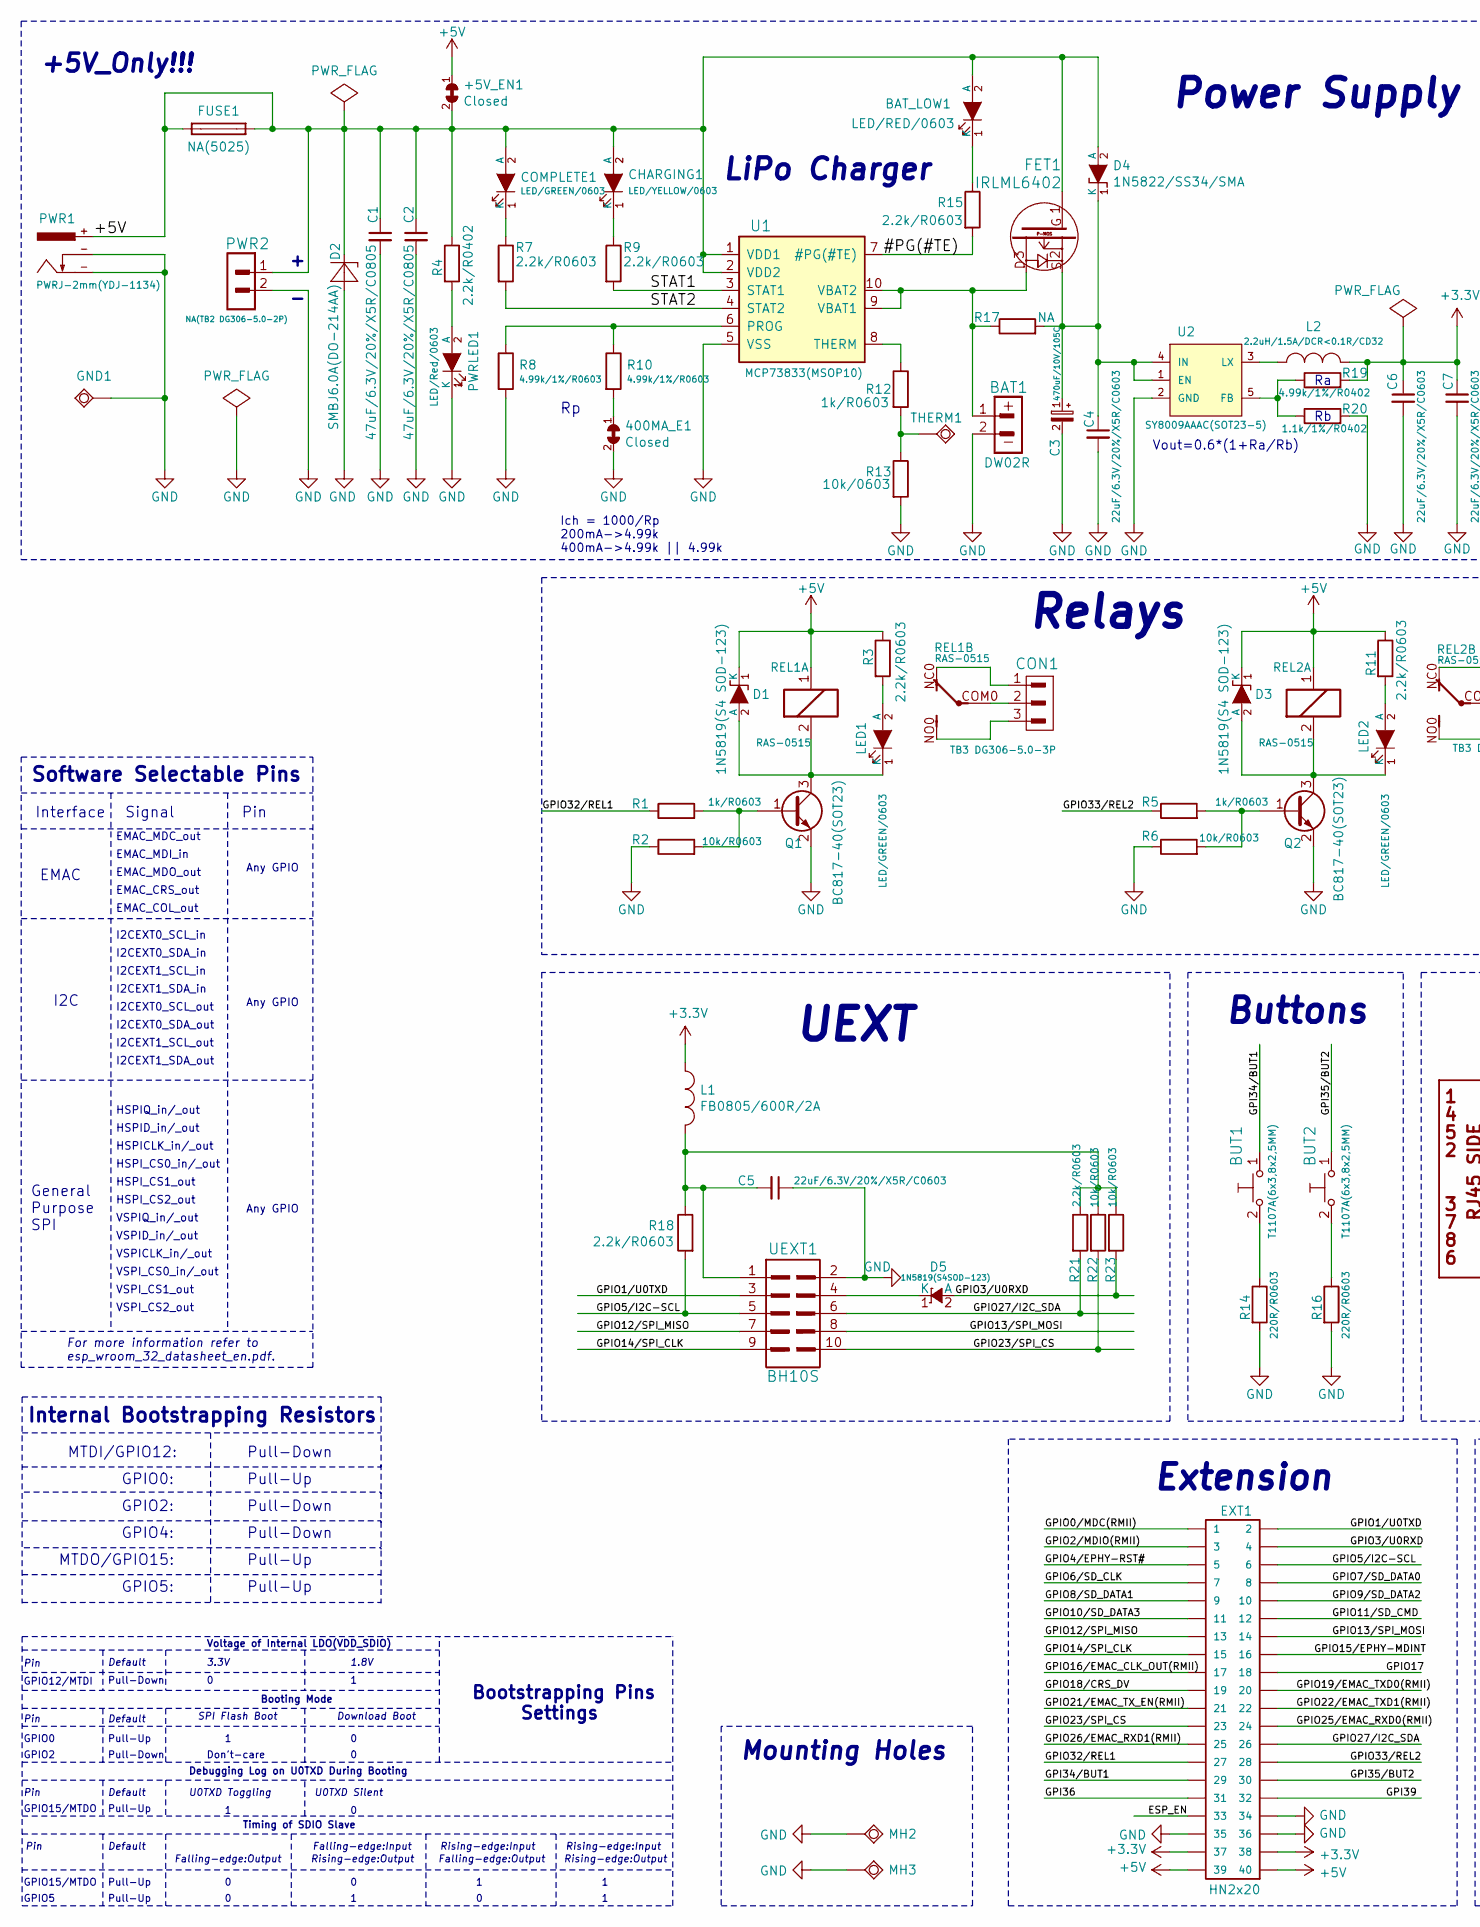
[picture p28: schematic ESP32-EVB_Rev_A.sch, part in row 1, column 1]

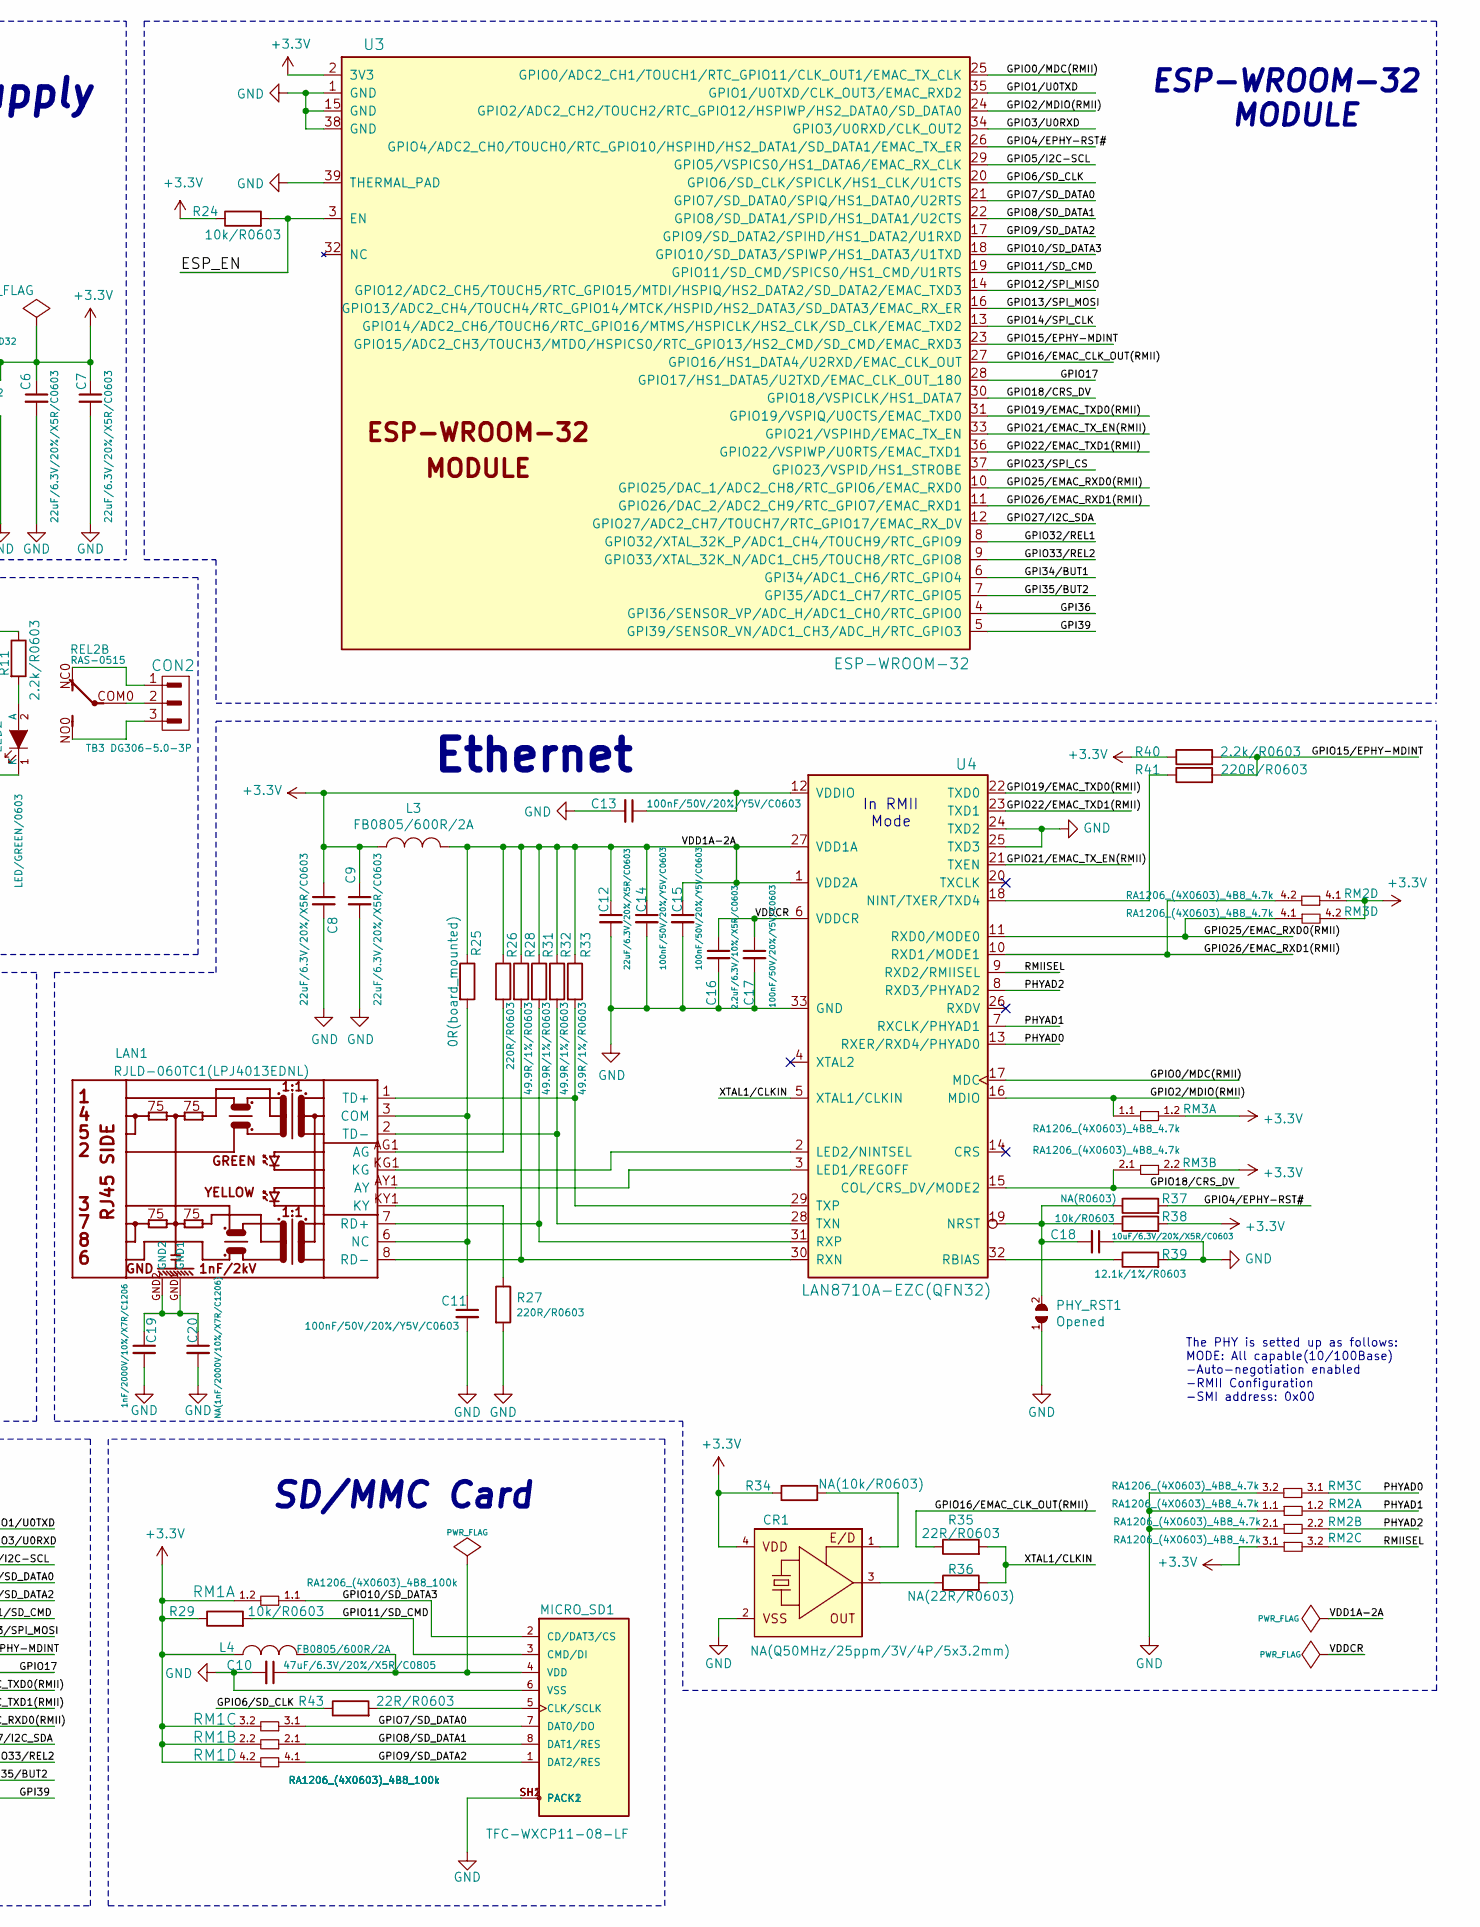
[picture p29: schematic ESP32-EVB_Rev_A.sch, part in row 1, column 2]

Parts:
400MA_E1: Closed; SJ_Closed
+5V_EN1: Closed; SJ_Closed
BAT1: DW02R; LIPO_BAT-CON2DW02R
BAT_LOW1: LED/RED/0603; LED_0603_KA
BUT1, BUT2: T1107A(6x3,8x2,5MM)
C1, C2, C10: 47uF/6.3V/20%/X5R/C0805; C_0805_5MIL_DWS
C3: 470uF/10V/105C; CPOL-EUE2.5-6.3(CPOL-EU)
C4, C5, C6, C7, C8, C9, C12: 22uF/6.3V/20%/X5R/C0603; C_0603_5MIL_DWS
C11, C13, C14, C15, C17: 100nF/50V/20%/Y5V/C0603; C_0603_5MIL_DWS
C16: 2.2uF/6.3V/10%/X5R/C0603; C_0603_5MIL_DWS
C18: 10uF/6.3V/20%/X5R/C0603; C_0603_5MIL_DWS
C19: 1nF/2000V/10%/X7R/C1206; C_1206_5MIL_DWS_ISO
C20: NA(1nF/2000V/10%/X7R/C1206); C_1206_5MIL_DWS_ISO
CHARGING1: LED/YELLOW/0603; LED_0603_KA
COMPLETE1: LED/GREEN/0603; LED_0603_KA
CON1, CON2: TB3 DG306-5.0-3P; TB3-DG306-5.0_3P
CR1: NA(Q50MHz/25ppm/3V/4P/5x3.2mm); 5032-4P_HCX-3S
D1, D3: 1N5819(S4 SOD-123); SOD-123_1C-2A_KA
D2: SMBJ6.0A(DO-214AA); DO214AA
D4: 1N5822/SS34/SMA; SMA-KA
D5: 1N5819(S4SOD-123); SOD-123_1C-2A_KA
EXT1: HN2x20
FET1: IRLML6402; SOT23
FUSE1: NA(5025); FUSE-5025
GND1: TESTPAD; TESTPAD_40-ROUND
L1, L3, L4: FB0805/600R/2A; L_0805_5MIL_DWS
L2: 2.2uH/1.5A/DCR<0.1R/CD32; CD32
LAN1: RJLD-060TC1(LPJ4013EDNL); RJLBC-060TC1
LED1, LED2: LED/GREEN/0603; LED_0603_KA
MH2, MH3: Mounting_hole_Shield_3.3mm
MICRO_SD1: TFC-WXCP11-08-LF
PHY_RST1: Opened; SJ
PWR1: PWRJ-2mm(YDJ-1134); PWRJ-2mm(YDJ-1136)
PWR2: NA(TB2 DG306-5.0-2P); TB2-DG306-5.0_2P
PWRLED1: LED/Red/0603; LED_0603_KA
Q1, Q2: BC817-40(SOT23); SOT23
R1, R5, R12: 1k/R0603; R_0603_5MIL_DWS
R2, R6, R22, R23, R24, R29, R38: 10k/R0603; R_0603_5MIL_DWS
R3, R7, R9, R11, R15, R18, R21, R40: 2.2k/R0603; R_0603_5MIL_DWS
R4: 2.2k/R0402; R_0402_5MIL_DWS
R8, R10: 4.99k/1%/R0603; R_0603_5MIL_DWS
R13: 10k/0603; R_0603_5MIL_DWS
R14, R16, R26, R27, R41: 220R/R0603; R_0603_5MIL_DWS
R17: NA; R_0603_5MIL_DWS
R19: 4.99k/1%/R0402; R_0402_5MIL_DWS
R20: 1.1k/1%/R0402; R_0402_5MIL_DWS
R25: 0R(board_mounted); 0R_0603
R28, R31, R32, R33: 49.9R/1%/R0603; R_0603_5MIL_DWS
R34: NA(10k/R0603); R_0603_5MIL_DWS
R35, R43: 22R/R0603; R_0603_5MIL_DWS
R36: NA(22R/R0603); R_0603_5MIL_DWS
R37: NA(R0603); R_0603_5MIL_DWS
R39: 12.1k/1%/R0603; R_0603_5MIL_DWS
REL1, REL2: RAS-0515; Relay_RAS-05-15
RM1: RA1206_(4X0603)_4B8_100k; R_MATRIX_4
RM2, RM3: RA1206_(4X0603)_4B8_4.7k; R_MATRIX_4
THERM1: TESTPAD; TESTPAD_40-ROUND
U1: MCP73833(MSOP10); MSOP-10_Pitch-0.5mm_3.00x3.00x1.00mm
U2: SY8009AAAC(SOT23-5); SOT-23-5
U3: ESP-WROOM-32; ESP-WROOM-32_MODULE
U4: LAN8710A-EZC(QFN32); QFN32_EP(33)_5.00x5.00x0.90mm_Pitch_0.50mm
UEXT1: BH10S; UEXT_ML10

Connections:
+3V3: C6.1, C7.1, C8.1, C9.1, C13.1, CR1.4 (VDD), EXT1.37, EXT1.38, L1.1, L2.2, L3.1, L4.1, R19.2, R24.1, R29.1, R34.1, R38.2, R40.1, RM1.1.2, RM1.2.2, RM1.3.2, RM1.4.2, RM2.3.1, RM2.4.1, RM3.1.2, RM3.2.2, RM3.4.2, U3.2 (3V3), U4.12 (VDDIO)
+5V: +5V_EN1.1, +5V_EN1.2, BAT_LOW1.2 (A), C1.1, C2.1, CHARGING1.2 (A), COMPLETE1.2 (A), D1.1 (K), D2.C, D3.1 (K), D4.2 (A), EXT1.39, EXT1.40, FET1.1, FUSE1.1, FUSE1.2, PWR1.+, PWR2.1, R3.1, R4.1, R11.1, REL1.1, REL2.1, U1.1 (VDD1), U1.2 (VDD2)
/#PG(#TE): R15.2, U1.7 (#PG(#TE))
/ESP_EN: EXT1.33, R24.2, U3.3 (EN)
/GPI34/BUT1: BUT1.1, EXT1.29, U3.6 (GPI34/ADC1_CH6/RTC_GPIO4)
/GPI35/BUT2: BUT2.1, EXT1.30, U3.7 (GPI35/ADC1_CH7/RTC_GPIO5)
/GPI36: EXT1.31, U3.4 (GPI36/SENSOR_VP/ADC_H/ADC1_CH0/RTC_GPIO0)
/GPI39: EXT1.32, U3.5 (GPI39/SENSOR_VN/ADC1_CH3/ADC_H/RTC_GPIO3)
/GPIO0/MDC(RMII): EXT1.1, U3.25 (GPIO0/ADC2_CH1/TOUCH1/RTC_GPIO11/CLK_OU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), U4.17 (MDC)
/GPIO1/U0TXD: EXT1.2, U3.35 (GPIO1/U0TXD/CLK_OUT3/EMAC_RXD2), UEXT1.3
/GPIO2/MDIO(RMII): EXT1.3, RM3.1.1, U3.24 (GPIO2/ADC2_CH2/TOUCH2/RTC_GPIO12/HSPIWP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), U4.16 (MDIO)
/GPIO3/U0RXD: D5.2 (A), EXT1.4, R23.2, U3.34 (GPIO3/U0RXD/CLK_OUT2)
/GPIO4/EPHY-RST#: EXT1.5, R37.2, U3.26 (GPIO4/ADC2_CH0/TOUCH0/RTC_GPIO10/HSPIHD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)
/GPIO5/I2C-SCL: EXT1.6, R18.2, U3.29 (GPIO5/VSPICS0/HS1_DATA6/EMAC_RX_CLK), UEXT1.5
/GPIO6/SD_CLK: EXT1.7, R43.1, U3.20 (GPIO6/SD_CLK/SPICLK/HS1_CLK/U1CTS)
/GPIO7/SD_DATA0: EXT1.8, MICRO_SD1.7 (DAT0/DO), RM1.3.1, U3.21 (GPIO7/SD_DATA0/SPIQ/HS1_DATA0/U2RTS)
/GPIO8/SD_DATA1: EXT1.9, MICRO_SD1.8 (DAT1/RES), RM1.2.1, U3.22 (GPIO8/SD_DATA1/SPID/HS1_DATA1/U2CTS)
/GPIO9/SD_DATA2: EXT1.10, MICRO_SD1.1 (DAT2/RES), RM1.4.1, U3.17 (GPIO9/SD_DATA2/SPIHD/HS1_DATA2/U1RXD)
/GPIO10/SD_DATA3: EXT1.11, MICRO_SD1.2 (CD/DAT3/CS), RM1.1.1, U3.18 (GPIO10/SD_DATA3/SPIWP/HS1_DATA3/U1TXD)
/GPIO11/SD_CMD: EXT1.12, MICRO_SD1.3 (CMD/DI), R29.2, U3.19 (GPIO11/SD_CMD/SPICS0/HS1_CMD/U1RTS)
/GPIO12/SPI_MISO: EXT1.13, U3.14 (GPIO12/ADC2_CH5/TOUCH5/RTC_GPIO15/MTDI/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), UEXT1.7
/GPIO13/SPI_MOSI: EXT1.14, U3.16 (GPIO13/ADC2_CH4/TOUCH4/RTC_GPIO14/MTCK/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), UEXT1.8
/GPIO14/SPI_CLK: EXT1.15, U3.13 (GPIO14/ADC2_CH6/TOUCH6/RTC_GPIO16/MTMS/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), UEXT1.9
/GPIO15/EPHY-MDINT: EXT1.16, R40.2, R41.2, U3.23 (GPIO15/ADC2_CH3/TOUCH3/MTDO/HSPICS0/RTC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)
/GPIO16/EMAC_CLK_OUT(RMII): EXT1.17, R35.1, U3.27 (GPIO16/HS1_DATA4/U2RXD/EMAC_CLK_OUT)
/GPIO17: EXT1.18, U3.28 (GPIO17/HS1_DATA5/U2TXD/EMAC_CLK_OUT_180)
/GPIO18/CRS_DV: EXT1.19, RM3.2.1, U3.30 (GPIO18/VSPICLK/HS1_DATA7), U4.15 (COL/CRS_DV/MODE2)
/GPIO19/EMAC_TXD0(RMII): EXT1.20, U3.31 (GPIO19/VSPIQ/U0CTS/EMAC_TXD0), U4.22 (TXD0)
/GPIO21/EMAC_TX_EN(RMII): EXT1.21, U3.33 (GPIO21/VSPIHD/EMAC_TX_EN), U4.21 (TXEN)
/GPIO22/EMAC_TXD1(RMII): EXT1.22, U3.36 (GPIO22/VSPIWP/U0RTS/EMAC_TXD1), U4.23 (TXD1)
/GPIO23/SPI_CS: EXT1.23, R22.2, U3.37 (GPIO23/VSPID/HS1_STROBE), UEXT1.10
/GPIO25/EMAC_RXD0(RMII): EXT1.24, RM3.4.1, U3.10 (GPIO25/DAC_1/ADC2_CH8/RTC_GPIO6/EMAC_RX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), U4.11 (RXD0/MODE0)
/GPIO26/EMAC_RXD1(RMII): EXT1.25, RM2.4.2, U3.11 (GPIO26/DAC_2/ADC2_CH9/RTC_GPIO7/EMAC_RX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), U4.10 (RXD1/MODE1)
/GPIO27/I2C_SDA: EXT1.26, R21.2, U3.12 (GPIO27/ADC2_CH7/TOUCH7/RTC_GPIO17/EMAC_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), UEXT1.6
/GPIO32/REL1: EXT1.27, R1.1, U3.8 (GPIO32/XTAL_32K_P/ADC1_CH4/TOUCH9/RTC_G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)
/GPIO33/REL2: EXT1.28, R5.1, U3.9 (GPIO33/XTAL_32K_N/ADC1_CH5/TOUCH8/RTC_G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)
/PHYAD0: RM3.3.1, U4.13 (RXER/RXD4/PHYAD0)
/PHYAD1: RM2.1.2, U4.7 (RXCLK/PHYAD1)
/PHYAD2: RM2.2.2, U4.8 (RXD3/PHYAD2)
/RMIISEL: RM2.3.2, U4.9 (RXD2/RMIISEL)
/STAT1: R9.2, U1.3 (STAT1)
/STAT2: R7.2, U1.4 (STAT2)
/VDD1A-2A: C12.1, C14.1, C15.1, L3.2, R25.1, R26.1, R28.1, R31.1, R32.1, R33.1, U4.1 (VDD2A), U4.27 (VDD1A)
/VDDCR: C16.1, C17.1, U4.6 (VDDCR)
/XTAL1/CLKIN: R35.2, R36.2, U4.5 (XTAL1/CLKIN)
GND: 400MA_E1.2, BAT1.2, C1.2, C2.2, C3.2 (-), C4.2, C5.1, C6.2, C7.2, C8.2, C9.2, C10.2, C11.2, C12.2, C13.2, C14.2, C15.2, C16.2, C17.2, C18.1, C19.2, C20.2, CR1.2 (VSS), D2.A, EXT1.34, EXT1.35, EXT1.36, GND1.1, MH2.GND1, MH3.GND1, MICRO_SD1.6 (VSS), MICRO_SD1.SH1 (PACK1), MICRO_SD1.SH2 (PACK2), PHY_RST1.1, PWR1.-, PWR2.2, PWRLED1.1 (K), Q1.2 (E), Q2.2 (E), R2.1, R6.1, R8.2, R13.2, R14.2, R16.2, R20.2, R27.2, R39.2, RM2.1.1, RM2.2.1, RM3.3.2, U1.5 (VSS), U2.2 (GND), U3.1 (GND), U3.15 (GND), U3.38 (GND), U3.39 (THERMAL_PAD), U4.24 (TXD2), U4.25 (TXD3), U4.33 (GND), UEXT1.2
unnamed: 400MA_E1.1, R10.2
unnamed: BAT1.1, FET1.3, R17.1, U1.9 (VBAT1), U1.10 (VBAT2)
unnamed: BAT_LOW1.1 (K), R15.1
unnamed: BUT1.2, R14.1
unnamed: BUT2.2, R16.1
unnamed: C3.1 (+), C4.1, D4.1 (K), FET1.2, R17.2, U2.1 (EN), U2.4 (IN)
unnamed: C5.2, L1.2, R18.1, R21.1, R22.1, R23.1, UEXT1.1
unnamed: C10.1, L4.2, MICRO_SD1.4 (VDD)
unnamed: C11.1, LAN1.3 (COM), LAN1.6 (NC), R25.2
unnamed: C18.2, PHY_RST1.2, R37.1, R38.1, U4.19 (NRST)
unnamed: C19.1, C20.1, LAN1.GND1, LAN1.GND2
unnamed: CHARGING1.1 (K), R9.1
unnamed: COMPLETE1.1 (K), R7.1
unnamed: CON1.1, REL1.NC0
unnamed: CON1.2, REL1.COM0
unnamed: CON1.3, REL1.NO0
unnamed: CON2.1, REL2.NC0
unnamed: CON2.2, REL2.COM0
unnamed: CON2.3, REL2.NO0
unnamed: CR1.1 (E/D), R34.2
unnamed: CR1.3 (OUT), R36.1
unnamed: D1.2 (A), LED1.1 (K), Q1.3 (C), REL1.2
unnamed: D3.2 (A), LED2.1 (K), Q2.3 (C), REL2.2
unnamed: D5.1 (K), UEXT1.4
unnamed: L2.1, U2.3 (LX)
unnamed: LAN1.1 (TD+), R33.2, U4.29 (TXP)
unnamed: LAN1.2 (TD-), R32.2, U4.28 (TXN)
unnamed: LAN1.7 (RD+), R31.2, U4.31 (RXP)
unnamed: LAN1.8 (RD-), R28.2, U4.30 (RXN)
unnamed: LAN1.AG1 (AG), R26.2
unnamed: LAN1.AY1 (AY), U4.3 (LED1/REGOFF)
unnamed: LAN1.KG1 (KG), U4.2 (LED2/NINTSEL)
unnamed: LAN1.KY1 (KY), R27.1
unnamed: LED1.2 (A), R3.2
unnamed: LED2.2 (A), R11.2
unnamed: MICRO_SD1.5 (CLK/SCLK), R43.2
unnamed: PWRLED1.2 (A), R4.2
unnamed: Q1.1 (B), R1.2, R2.2
unnamed: Q2.1 (B), R5.2, R6.2
unnamed: R8.1, R10.1, U1.6 (PROG)
unnamed: R12.1, U1.8 (THERM)
unnamed: R12.2, R13.1, THERM1.1
unnamed: R19.1, R20.1, U2.5 (FB)
unnamed: R39.1, U4.32 (RBIAS)
unnamed: R41.1, U4.18 (NINT/TXER/TXD4)

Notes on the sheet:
Vout=0.6*(1+Ra/Rb)
Power Supply
Buttons
Relays
UEXT
Ich = 1000/Rp 200mA->4.99k 400mA->4.99k || 4.99k
In RMII Mode
Ethernet
ESP-WROOM-32 MODULE
SD/MMC Card
Bootstrapping Pins Settings
Internal Bootstrapping Resistors
MTDI/GPIO12:
Pull-Down
GPIO0:
Pull-Up
GPIO2:
GPIO4:
MTDO/GPIO15:
GPIO5:
Voltage of Internal LDO(VDD_SDIO)
Pin
Default
3.3V
1.8V
Booting Mode
GPIO12/MTDI
GPIO0
GPIO2
SPI Flash Boot
Download Boot
Don't-care
Debugging Log on U0TXD During Booting
U0TXD Toggling
U0TXD Silent
GPIO15/MTDO
Timing of SDIO Slave
For more information refer to esp_wroom_32_datasheet_en.pdf.
Falling-edge:Output
Falling-edge:Input

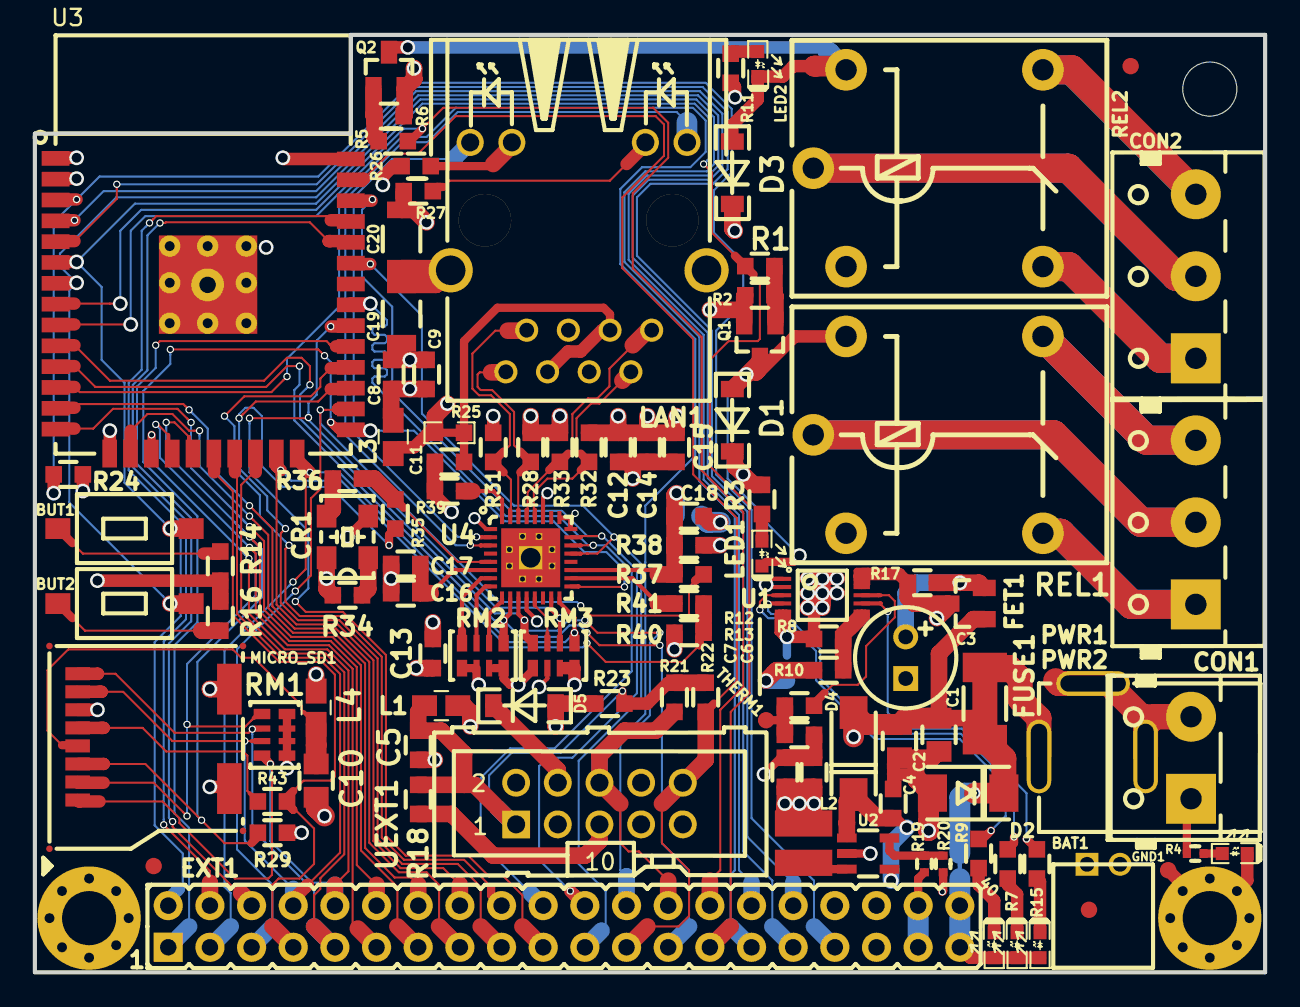
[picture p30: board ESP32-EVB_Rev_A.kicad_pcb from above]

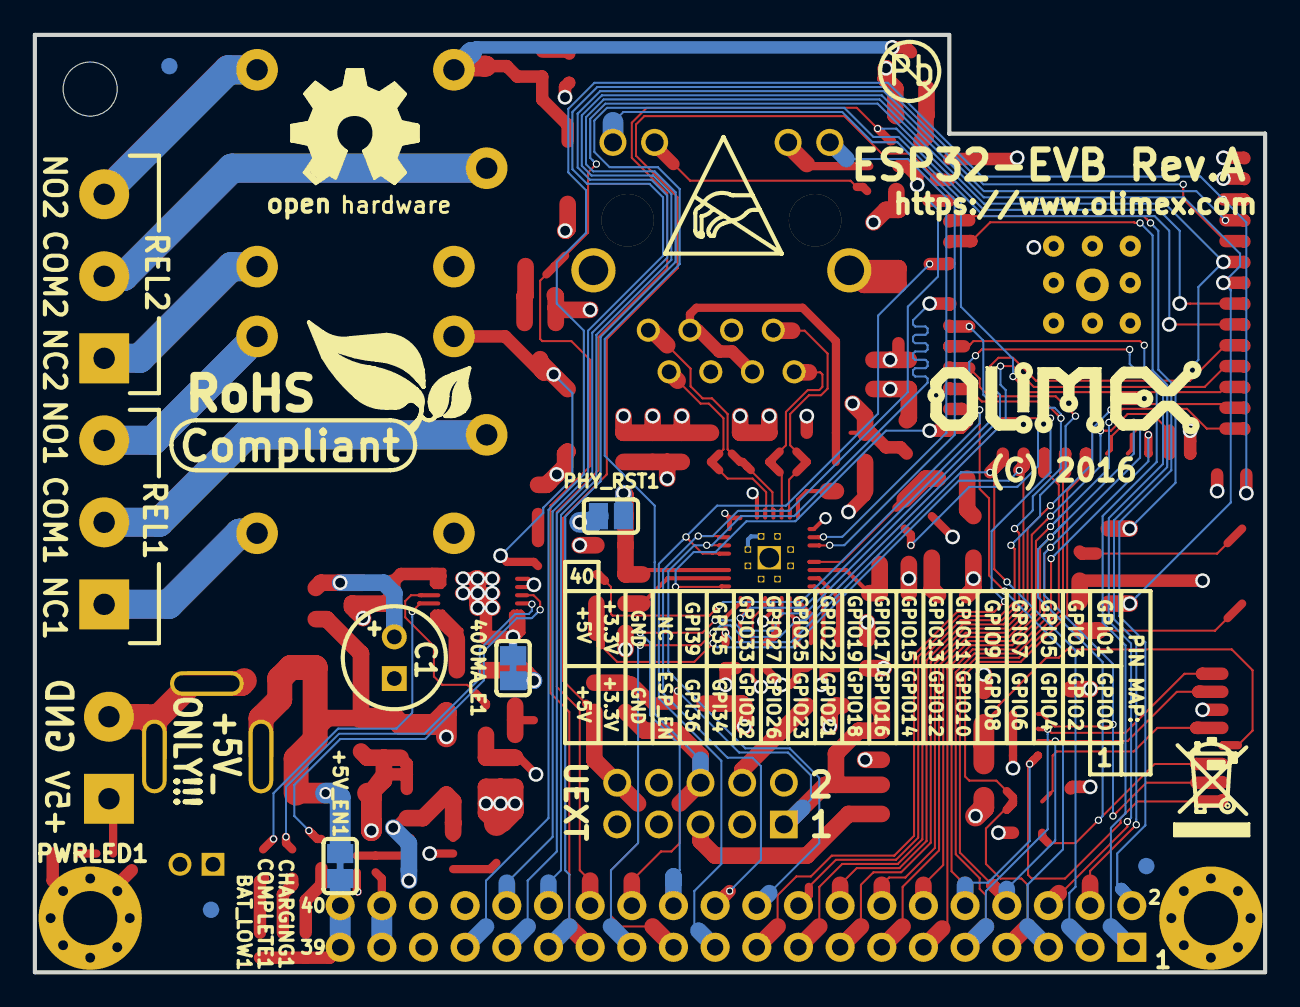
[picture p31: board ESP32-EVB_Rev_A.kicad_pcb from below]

Board: 4 copper layers, 75.0 x 57.2 mm, 111 parts (5 on the bottom side), 91 nets.

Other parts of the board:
MH1: Mounting_hole_Shield_3.3mm; Mounting_hole_3.3mm
Ref**: Val**; LOGO_ANTISTATIC_1
Ref**#2: Val**; LOGO_ROHS_1

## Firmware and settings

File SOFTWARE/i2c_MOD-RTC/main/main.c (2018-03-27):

/* i2c - Example

   For other examples please check:
   https://github.com/espressif/esp-idf/tree/master/examples

   This example code is in the Public Domain (or CC0 licensed, at your option.)

   Unless required by applicable law or agreed to in writing, this
   software is distributed on an "AS IS" BASIS, WITHOUT WARRANTIES OR
   CONDITIONS OF ANY KIND, either express or implied.
*/
#include <stdio.h>
#include "driver/i2c.h"

/**
 * TEST CODE BRIEF
 *
 * This example will show you how to use I2C module.
 *
 * - read external i2c module, here we use a PCF8563
 *
 * Pin assignment:
 *
 * - master:
 *    GPIO13 is assigned as the data signal of i2c master port
 *    GPIO16 is assigned as the clock signal of i2c master port
 *
 * Connection:
 *
 * - connect MOD-RTC to the UEXT of the ESP32-EVB
 *
 *
 * - read the data from the module, if connected.
 * - on the terminal date and time will be printed
 * - by default the date and time is set to 28 february 2020; 23:59:50
 */

#define I2C_EXAMPLE_MASTER_SCL_IO          16               /*!< gpio number for I2C master clock */
#define I2C_EXAMPLE_MASTER_SDA_IO          13               /*!< gpio number for I2C master data  */
#define I2C_EXAMPLE_MASTER_NUM             I2C_NUM_1        /*!< I2C port number for master dev */
#define I2C_EXAMPLE_MASTER_TX_BUF_DISABLE  0                /*!< I2C master do not need buffer */
#define I2C_EXAMPLE_MASTER_RX_BUF_DISABLE  0                /*!< I2C master do not need buffer */
#define I2C_EXAMPLE_MASTER_FREQ_HZ         100000           /*!< I2C master clock frequency */

// I2C address of the module
#define  ADDRESS 0x51

// Control and status registers
#define  CTRL_STAT1  0x00
#define  CTRL_STAT2  0x01

// Time and date registers
#define  SECONDS     0x02
#define  MINUTES     0x03
#define  HOURS       0x04
#define  DAYS        0x05
#define  WEEKDAYS    0x06
#define  MONTHS      0x07
#define  YEARS       0x08

// Alarm registers
#define  AMINUTES    0x09
#define  AHOURS      0x0A
#define  ADAYS       0x0B
#define  AWEEKDAYS   0x0C

//CLKOUT control register
#define  CLKOUT_CTRL 0x0D

// Timer registers
#define  TIMER_CTRL  0x0E
#define  TIMER       0x0F

#define WRITE_BIT                          I2C_MASTER_WRITE /*!< I2C master write */
#define READ_BIT                           I2C_MASTER_READ  /*!< I2C master read */
#define ACK_CHECK_EN                       0x1              /*!< I2C master will check ack from slave*/
#define ACK_CHECK_DIS                      0x0              /*!< I2C master will not check ack from slave */
#define ACK_VAL                            0x0              /*!< I2C ack value */
#define NACK_VAL                           0x1              /*!< I2C nack value */

// 28 february 2020; 23:59:50
#define	INITIAL_DATE_TIME	{20, 2, 28, 5, 23, 59, 50}

struct _Date_Time
{
	unsigned char Year, Month, Day, WeekDay, Hour, Minute, Second;
};
typedef struct _Date_Time Date_Time;

SemaphoreHandle_t print_mux = NULL;

const int Mask[16] =
{
	0xFF,  // 0
	0xFF,  // 1
	0x7F,  // 2
	0x7F,  // 3
	0x3F,  // 4
	0x3F,  // 5
	0x07,  // 6
	0x1F,  // 7
	0xFF,  // 8
	0x7F,  // 9
	0x3F,  // 10
	0x3F,  // 11
	0x07,  // 12
	0x03,  // 13
	0x03,  // 14
	0xFF,  // 15
};

const char WeekDays[7][10] =
{
	"Sunday",
	"Monday",
	"Tuesday",
	"Wednesday",
	"Thursday",
	"Friday",
	"Saturday"
};

int BCD_to_Int (int Input)
{
	return (Input>>4)*10+(Input&0x0F);
}

int Int_to_BCD (int Input)
{
	return ((Input/10)<<4) | (Input%10);
}

/**
 * @brief i2c master initialization
 */
static void i2c_example_master_init()
{
	int i2c_master_port = I2C_EXAMPLE_MASTER_NUM;
	i2c_config_t conf;
	conf.mode = I2C_MODE_MASTER;
	conf.sda_io_num = I2C_EXAMPLE_MASTER_SDA_IO;
	conf.sda_pullup_en = GPIO_PULLUP_ENABLE;
	conf.scl_io_num = I2C_EXAMPLE_MASTER_SCL_IO;
	conf.scl_pullup_en = GPIO_PULLUP_ENABLE;
	conf.master.clk_speed = I2C_EXAMPLE_MASTER_FREQ_HZ;
	i2c_param_config(i2c_master_port, &conf);
	i2c_driver_install(i2c_master_port, conf.mode, I2C_EXAMPLE_MASTER_RX_BUF_DISABLE, I2C_EXAMPLE_MASTER_TX_BUF_DISABLE, 0);
}

static esp_err_t i2c_example_master_sensor_test(i2c_port_t i2c_num, uint8_t* Data)
{
	int ret;
	i2c_cmd_handle_t cmd = i2c_cmd_link_create();
	i2c_master_start(cmd);
	i2c_master_write_byte(cmd, ADDRESS << 1 | WRITE_BIT, ACK_CHECK_EN);
	i2c_master_write_byte(cmd, CTRL_STAT1, ACK_CHECK_EN);
	i2c_master_stop(cmd);
	ret = i2c_master_cmd_begin(i2c_num, cmd, 1000 / portTICK_RATE_MS);
	i2c_cmd_link_delete(cmd);
	if (ret != ESP_OK)
	{
		return ret;
	}
	vTaskDelay(30 / portTICK_RATE_MS);
	cmd = i2c_cmd_link_create();
	i2c_master_start(cmd);
	i2c_master_write_byte(cmd, ADDRESS << 1 | READ_BIT, ACK_CHECK_EN);
	i2c_master_read(cmd, Data, 15, ACK_VAL);
	i2c_master_read_byte(cmd, Data+15, NACK_VAL);
	i2c_master_stop(cmd);
	ret = i2c_master_cmd_begin(i2c_num, cmd, 1000 / portTICK_RATE_MS);
	i2c_cmd_link_delete(cmd);

	return ret;
}

void I2C_Send (unsigned char Register, unsigned char Data)
{
	unsigned char Temp[2] = {Register, Data};
	i2c_cmd_handle_t cmd = i2c_cmd_link_create();
	i2c_master_start(cmd);
	i2c_master_write_byte(cmd, ADDRESS << 1 | WRITE_BIT, ACK_CHECK_EN);
	i2c_master_write(cmd, Temp, 2, ACK_CHECK_EN);
	i2c_master_stop(cmd);
	i2c_master_cmd_begin(I2C_EXAMPLE_MASTER_NUM, cmd, 1000 / portTICK_RATE_MS);
	i2c_cmd_link_delete(cmd);
}

void Set_Date_Time (Date_Time *Start_Date_Time)
{
	I2C_Send (YEARS, Int_to_BCD(Start_Date_Time->Year));
	I2C_Send (MONTHS, Int_to_BCD(Start_Date_Time->Month));
	I2C_Send (DAYS, Int_to_BCD(Start_Date_Time->Day));
	I2C_Send (WEEKDAYS, Int_to_BCD(Start_Date_Time->WeekDay));
	I2C_Send (HOURS, Int_to_BCD(Start_Date_Time->Hour));
	I2C_Send (MINUTES, Int_to_BCD(Start_Date_Time->Minute));
	I2C_Send (SECONDS, Int_to_BCD(Start_Date_Time->Second));

	return;
}

static void i2c_test_task(void* arg)
{
	unsigned char Data[16];
	int ret, i;
	Date_Time Start_Date_Time = INITIAL_DATE_TIME;
	Set_Date_Time (&Start_Date_Time);
	while (1)
	{
		ret = i2c_example_master_sensor_test( I2C_EXAMPLE_MASTER_NUM, Data);
		xSemaphoreTake(print_mux, portMAX_DELAY);
		if(ret == ESP_ERR_TIMEOUT)
		{
			printf("I2C timeout\n");
		}
		else if(ret == ESP_OK)
		{
			// raw data
			// for (i=0; i<16; i++)
				//printf ("Data[%d] = %x\n", i, Data[i]);
			for (i=0; i<16; i++)
				Data[i] = BCD_to_Int(Data[i] & Mask[i]);
			printf ("\f%.2d/%.2d/%.2d (%s) %.2d:%.2d:%.2d\n", Data[8], Data[7], Data[5], WeekDays[Data[6]], Data[4], Data[3], Data[2]);
		}
		else
		{
			printf("No ack, sensor not connected...skip...\n");
		}
		xSemaphoreGive(print_mux);
		vTaskDelay(50);	// equals ~half a seconds
	}
}

void app_main()
{
	print_mux = xSemaphoreCreateMutex();
	i2c_example_master_init();
	xTaskCreate(i2c_test_task, "i2c_test_task_1", 1024 * 2, (void* ) 1, 10, NULL);
}

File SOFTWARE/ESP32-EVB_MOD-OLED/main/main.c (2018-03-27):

/* i2c - Example

   For other examples please check:
   https://github.com/espressif/esp-idf/tree/master/examples

   This example code is in the Public Domain (or CC0 licensed, at your option.)

   Unless required by applicable law or agreed to in writing, this
   software is distributed on an "AS IS" BASIS, WITHOUT WARRANTIES OR
   CONDITIONS OF ANY KIND, either express or implied.
*/
#include <stdio.h>
#include <string.h>
#include "driver/i2c.h"
#include "Draw_Functions.h"
#include "SSD1306.h"

/**
 * TEST CODE BRIEF
 *
 * This example will show you how to use MOD-OLED with ESP32-EVB.
 * https://github.com/OLIMEX/ESP32-EVB
 *
 * Pin assignment:
 *
 * - master:
 *    GPIO13 is assigned as the data signal of i2c master port
 *    GPIO16 is assigned as the clock signal of i2c master port
 *
 * Connection:
 * - connect MOD-OLED to the UEXT of the ESP32-EVB
 *
 *
 * - on the screen you will see a welcome message
 * - when you press the button you will see the button counter
 * - it will inverse the colors on every click
 */

uint8_t oledBuffer[OLED_SIZE];

SemaphoreHandle_t print_mux = NULL;

#define	PRESSED 	1
#define	RELEASED	0

// button scan function with simple debounce check
int Button_State (void)
{
	int Debounce_Timeout = 100;	// threshold value
	if (!gpio_get_level(GPIO_NUM_34))
	{
		while ((!gpio_get_level(GPIO_NUM_34)) && --Debounce_Timeout);
		if (!Debounce_Timeout)
			return PRESSED;
	}
	return RELEASED;
}

void i2c_test_task(void* arg)
{
	int ret, Flag=1, Counter=0;
	char Text [32];

	// button initialized as input
	gpio_set_direction (GPIO_NUM_34, GPIO_MODE_INPUT);
	
	oledInitialize ();
	print_text(1, " OLIMEX");
	print_smtext(3, (unsigned char *)"         Hello World!", 1);
	print_smtext(5, (unsigned char *)"         Press BUT1  ", 1);
	print_smtext(6, (unsigned char *)"         to see the  ", 1);
	print_smtext(7, (unsigned char *)"        click counter", 1);
	 

	drawLine(1, 25, 128, 25);

	drawEllipse(20, 70, 5, 20);
	drawLine(23, 52, 37, 60);
	drawLine(17, 52, 10, 64);

	drawCircle(20, 40, 10);
	drawLine(15, 38, 18, 38);
	drawLine(22, 38, 25, 38);
	drawLine(20, 40, 21, 42);
	drawLine(15, 43, 16, 45);
	drawLine(17, 46, 20, 47);
	drawTriangle(5, 35, 20, 28, 35, 35);

	drawRectangle(37, 55, 40, 65);
	drawSolidRectangle(37, 54, 40, 30);

	oledUpdate ();

	while (1)
	{
		ret = ESP_OK;
		xSemaphoreTake(print_mux, portMAX_DELAY);
		if(ret == ESP_OK)
		{
			if ((Button_State() == PRESSED) && Flag)
			{
				Counter++;
				Flag = 0;
				sprintf (Text, "BUT1 click count: %d", Counter);
				oledClear ();
				_set_inverse_display (Counter&1);
				print_text(1," OLIMEX");
				print_smtext(4,(unsigned char *)Text,0);
				oledUpdate ();
			}
			if (Button_State() == RELEASED)
				Flag = 1;
		}
		else
			if(ret == ESP_ERR_TIMEOUT)
			{
				printf("I2C timeout\n");
			}
			else
			{
				printf("No ack, sensor not connected...skip...\n");
			}
		xSemaphoreGive(print_mux);
	}
}

void app_main()
{
	print_mux = xSemaphoreCreateMutex();
	i2c_example_master_init();
	xTaskCreate(i2c_test_task, "i2c_test_task_1", 1024 * 2, (void* ) 1, 10, NULL);
}

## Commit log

2017-02-10 Initial REV-A hardware
    [ESP32-EVB_Rev_A-BOM.ods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]
2017-05-29 ESP32-EVB revision B update
    [ESP32-EVB_Rev_B.csv, ESP32-EVB_Rev_B.kicad_pcb, ESP32-EVB_Rev_B.sch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]
2017-06-14 Add CAN Demo for the EVB Rev B
    Demo CAN
    ESP32 EVB REV B provide CAN on
    Rx GPIO 35
    Tx GPIO 5
    You can set over kconfig CAN properties.
    We send with NODE 0xC5 standard frames with 8 byte and
    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
2017-06-15 Add ETH PHY Demo for the EVB Rev B
    Demo ETH PHY
    ESP32 EVB REV B provide ETH PHY with LAN8710
    we use for config the compatible LAN8720 config
    the demo code was revised for EVB REV B
    TLK110 option was removed, also the PHY Power enable
    is not need on the EVB REV B Board.
    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
2017-10-23 Update
    hardware revision C files
    [ESP32-EVB_Rev_C-B.Cu.gbr, ESP32-EVB_Rev_C-B.Mask.gbr, ESP32-EVB_Rev_C-B.Paste.gbr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]
2018-03-21 New demo
    esp32-evb with mod-rtc
2018-03-22 New demo
    New demo of ESP32-EVB and MOD-OLED
2018-03-27 fix
    Small typo in the comments about I2C pins
    [main.c]
2018-07-04 Fix
    Changed ethernet example
    [ethernet_example_main.c, main.c, olimex_ethernet.c]
2019-06-13 Added demo
    Added ESP32-EVB iperf demo.
    [partitions_example.csv]
2020-07-27 Update
    Revision I added, revision changes updated
    [434121043836 (rev1).stp, 5040771891.stp, BAT54.step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]
2022-02-11 Update
    Updated a couple of examples for ESP-IDF v4.4, cleaned the repo a bit
    [partitions_example.csv]
2022-03-25 Tailor to ESP32-EVB
    Combined "Pin Assignment" and "Configure the project" sections and provided ESP32-EVB-specific values.
2022-03-29 Initial commit. WIP.
    Work in progress for CAN example.
    [ESP32-EVB_Rev_I-BOM.ods, partitions_example.csv]
2022-04-11 working example
    working example, but in test it drifted 10 minutes over 60 hours. Assumes a 20x4 LCD in 4-bit parallel mode.
    [sample_multipage_blob.csv, sample_singlepage_blob.csv]
2022-05-18 Example addition
    Added CAN library and examples for Arduino IDE
2022-07-27 Update
    Added info on Arduino for ESP32 installation.
2023-07-07 Update
    Revision K1
    [434121043836 (rev1).stp, 5040771891.stp, BAT54.step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]
2023-11-29 Update
    MQQT examples ESP32-EVB
2025-10-21 Update
    Added revisions K2 and L.
    [434121043836 (rev1).stp, 5040771891.stp, BAT54.step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]
2026-01-16 Update
    box design
    [bottom_v2_textured.stl, esp32-evbrevk.step, top_v2_textured.stl]

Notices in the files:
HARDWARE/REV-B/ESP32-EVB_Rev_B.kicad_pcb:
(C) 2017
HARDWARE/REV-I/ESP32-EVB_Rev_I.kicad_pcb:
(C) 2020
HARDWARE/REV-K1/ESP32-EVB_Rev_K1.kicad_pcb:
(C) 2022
